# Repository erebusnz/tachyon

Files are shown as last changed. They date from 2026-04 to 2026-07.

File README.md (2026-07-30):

# Tachyon

An open-hardware Eurorack step sequencer with an onboard **wavetable
voice**, built around the STM32F405RGT6 (WeAct core board). Tachyon plays
single-cycle wavetables loaded from a microSD card (Korg
`.korgmultisample` format), driven by a circle-of-fifths key/chord
arpeggiator or by a USB-MIDI host. It generates two precision 1 V/oct CV
outputs, two +5 V gate outputs, and two audio outputs, accepts two CV
modulation inputs and an external clock, and is navigated via a rotary
encoder, a parameter adjustment pot, and a 128×128 OLED screen.

## At a glance

| | |
|---|---|
| **MCU** | STM32F405RGT6 @ 168 MHz (WeAct 64-pin core board), 1 MB Flash, 192 KB RAM |
| **Storage** | MicroSD slot on the WeAct board (SDIO 4-bit) |
| **CV outputs** | 2 × 16-bit, 0–10 V, 1 V/oct, DAC8552 + OPA1642 ×4 |
| **Gate outputs** | 2 × 0/+5 V, 2N7002K level shift |
| **CV inputs** | 2 × bipolar modulation, OPA1642 attenuator → ADC1 |
| **Clock input** | +5 V trigger, TIM2 input capture (with internal BPM fallback) |
| **Audio output** | Stereo I²S, PCM5102A DirectPath |
| **Display** | 1.5″ 128×128 OLED (SSD1327, 4-bit grayscale, SPI) |
| **Controls** | Alps EC11E rotary encoder w/ push switch + Alps 100K pot |
| **USB** | USB-C on the WeAct board — USB MIDI class device, DFU flashing |
| **Power** | 10-pin Doepfer header, ±12 V only (local +5 V buck) |
| **Format** | Eurorack, 10 HP, 3-board sandwich (front / IO / backing) |

### High-level design

- **[hardware-design-plan.md](hardware-design-plan.md)** — the master
  hardware plan. MCU pin budget, peripheral selection, input /
  display / DAC / op-amp choices with rationale.

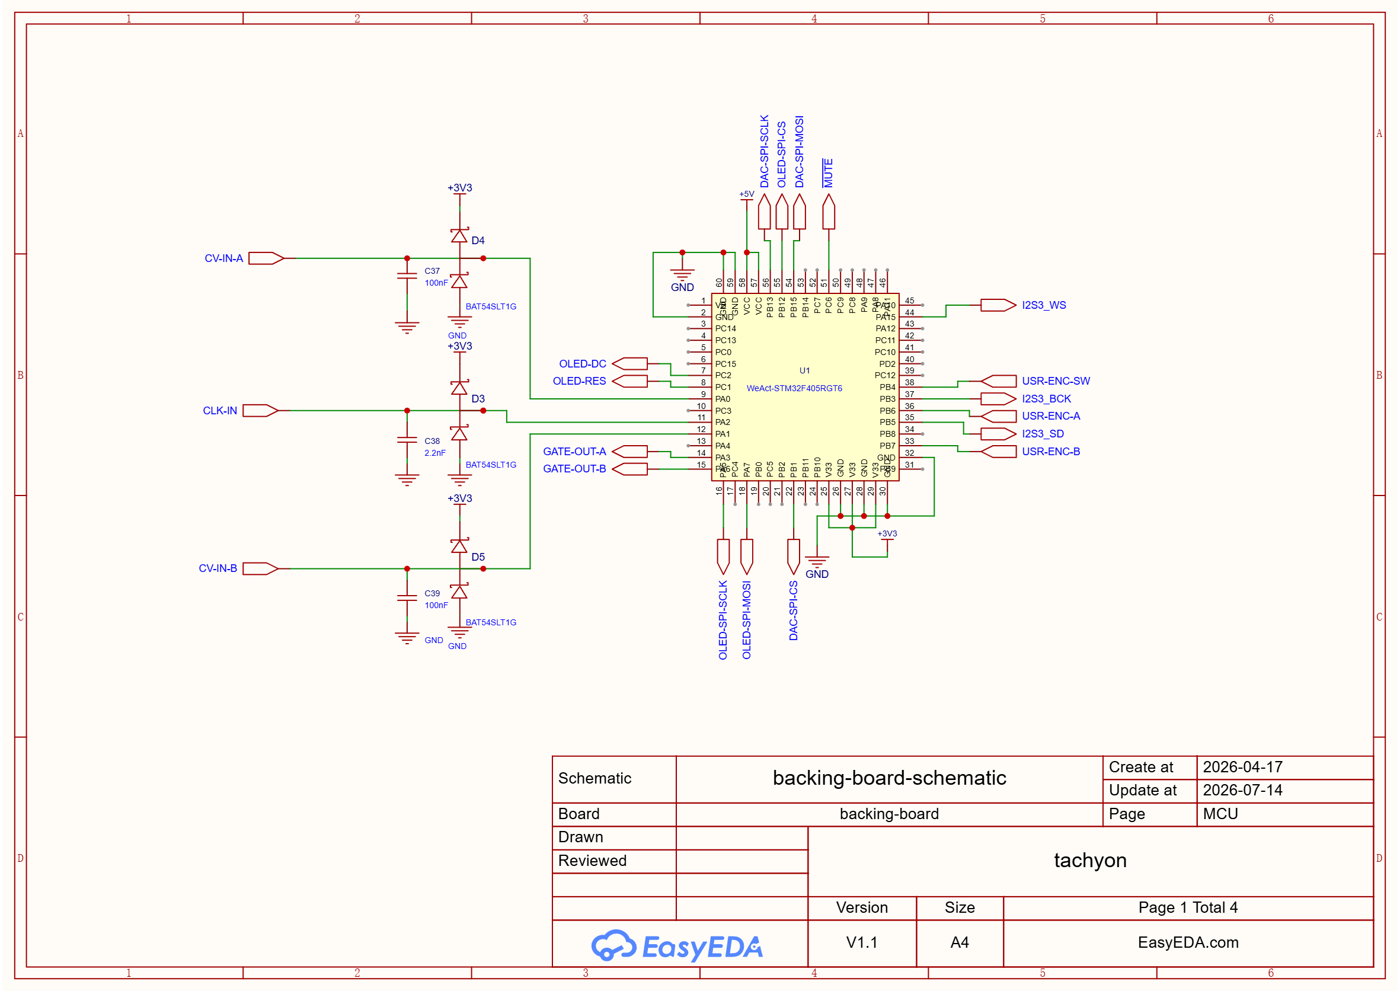
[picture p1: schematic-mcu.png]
MCU schematic
  

### Subsystem specs

These are schematic specs — per-pin connections,
decoupling BOMs:

- **[cv-output-dac.md](cv-output-dac.md)** — precision CV chain:
  DAC8552 (U6) + REF5025 (U2) + OPA1642 (U7), ×4 non-inverting gain
  stage producing 0–10 V at 1 V/oct, with feedback-tap and
  output-protection rules.

- **[cv-input.md](cv-input.md)** — 2 × bipolar Eurorack CV jacks
  through an OPA1642 (U23) inverting attenuator + 1.25 V bias stage
  into ADC1 (PA0/PA1), with BAT54S input clamping.

- **[gate-output.md](gate-output.md)** — 2 × 0/+5 V gate/trigger
  outputs via 2N7002K MOSFET inverting drivers with pull-ups to the
  +5 V rail.

- **[clock-input.md](clock-input.md)** — external +5 V clock jack
  routed to TIM2 input capture (PA2) with the same BAT54S clamp;
  firmware-generated BPM clock as the internal fallback.

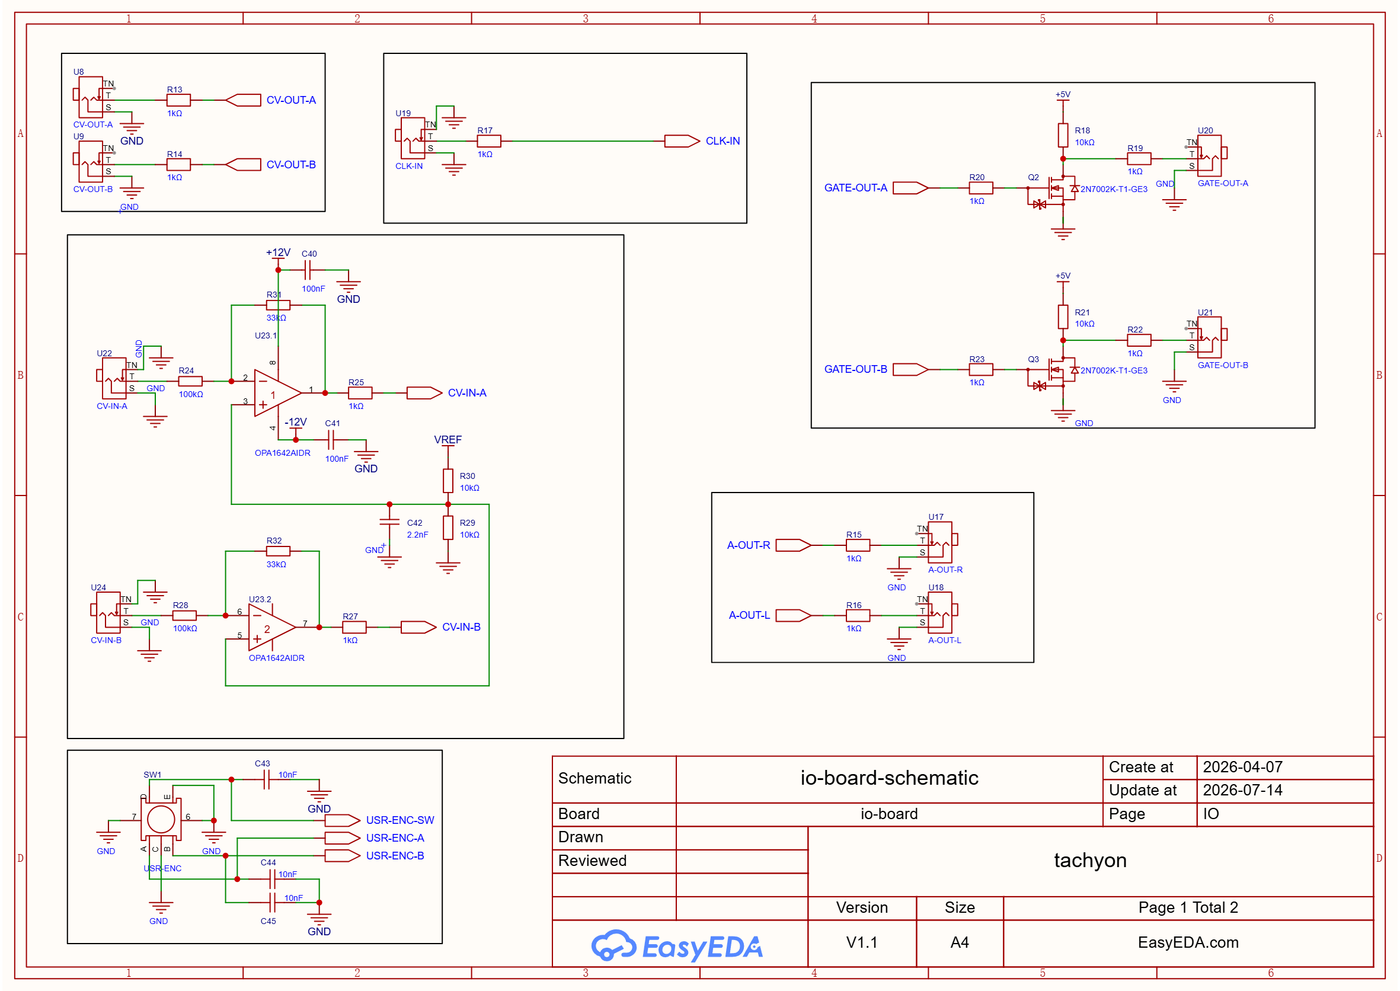
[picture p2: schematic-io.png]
CV and I/O schematic
  

- **[audio-output-dac.md](audio-output-dac.md)** — stereo audio
  chain: PCM5102A (U3) on I²S3, DirectPath outputs to two TS jacks,
  `~MUTE` line, and per-pin decoupling.

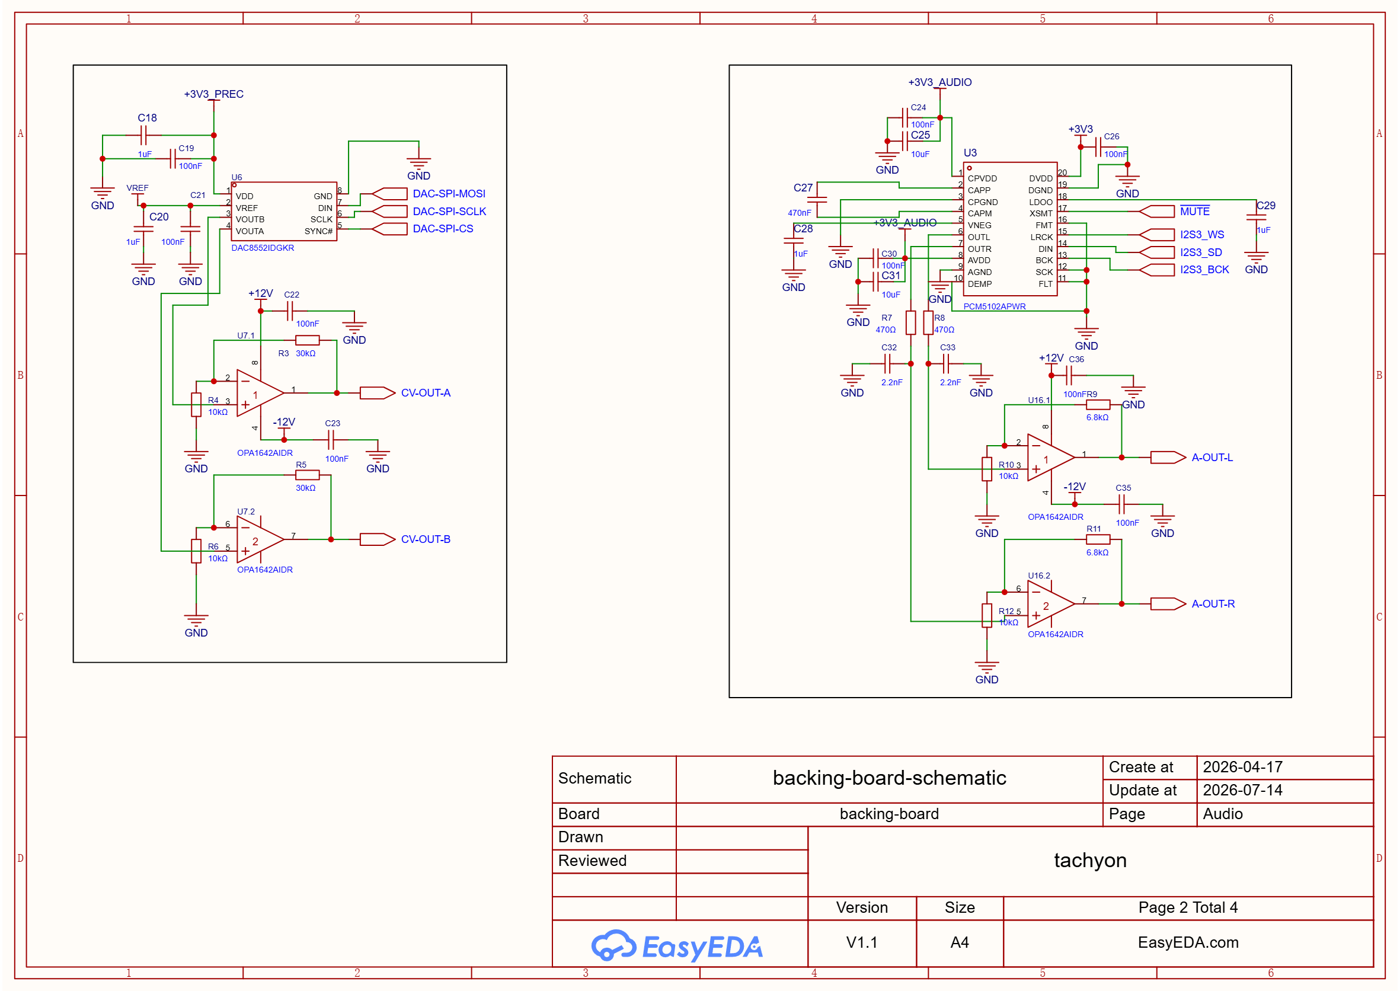
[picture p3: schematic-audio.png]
Audio schematic
  

- **[user-interface.md](user-interface.md)** — front-panel I/O:
  SSD1327 OLED on dedicated SPI1, Alps EC11E quadrature encoder on
  TIM4 with EXTI push-switch, and a 100 K Alps pot into ADC1.

- **[power-supply.md](power-supply.md)** — full power tree: +12 V
  input protection, +12 V → +5 V buck (TPS54202), the two
  TPS7A2033 low-noise LDOs for `+3V3_PREC` and `+3V3_AUDIO`, and
  the rail current budget.

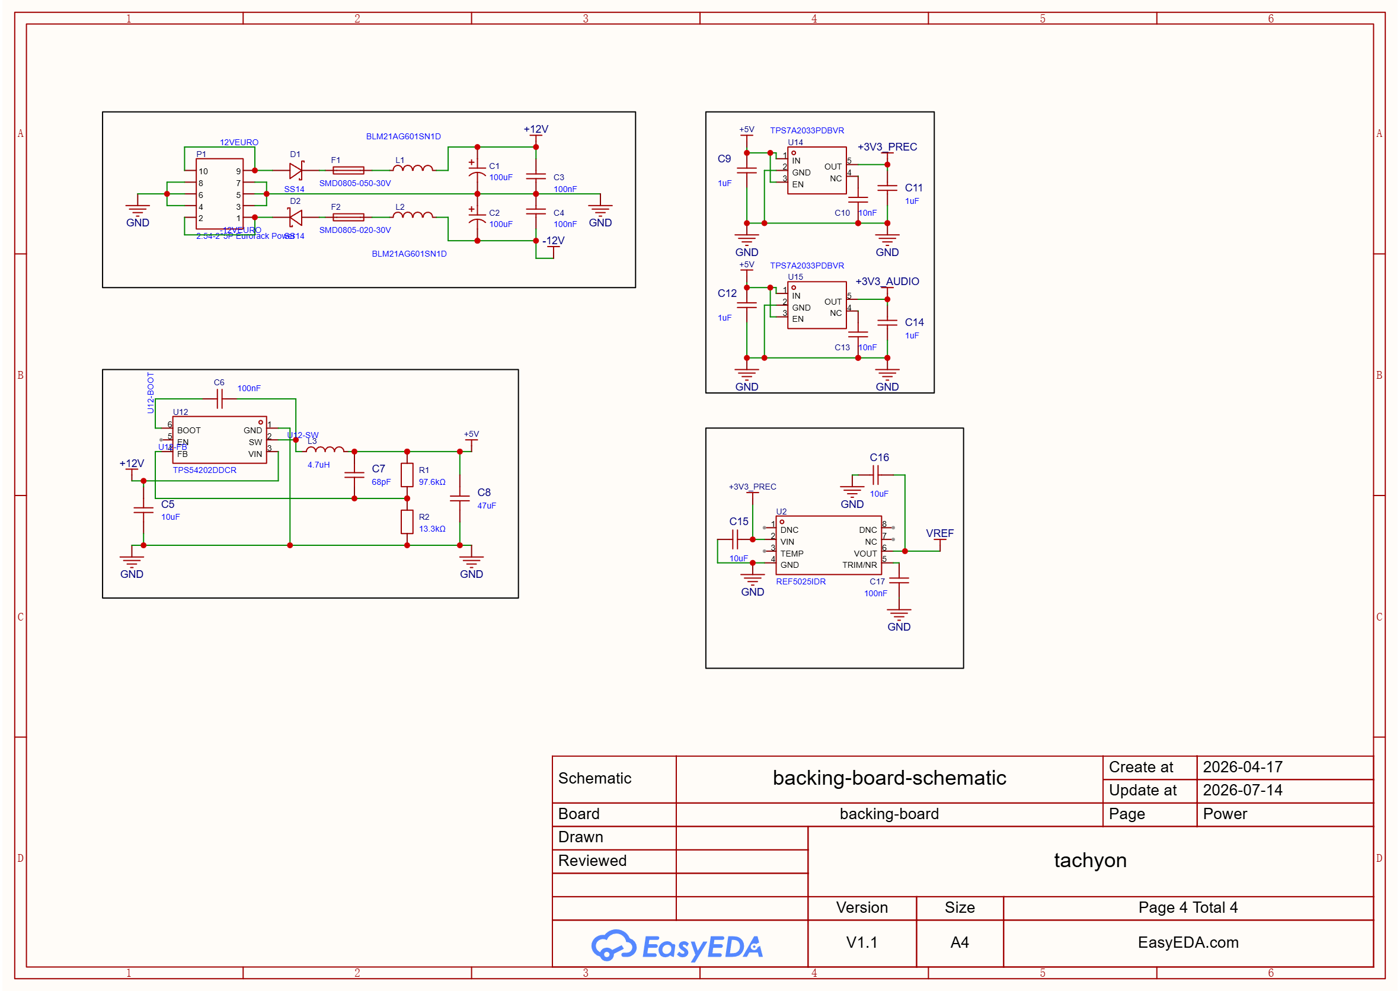
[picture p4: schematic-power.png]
Power schematic
  

### Physical design

The module is a three-PCB sandwich: a **front** board (panel
graphics, no electrical content), an **IO** board (panel-side
jacks, pot, encoder, and OLED ribbon connector), and a **backing**
board (the dense analog/digital board with the buck, LDOs,
references, DACs, op-amps, and the WeAct STM32 module on its
bottom side). The boards mate via inter-board pin headers.

- **[pcb-design.md](pcb-design.md)** — PCB stackup, ground plane
  rules (one continuous Layer 2 plane, no splits), power pour
  regions, placement zones, and signal routing guidance for the
  backing board, plus the inter-board header map.

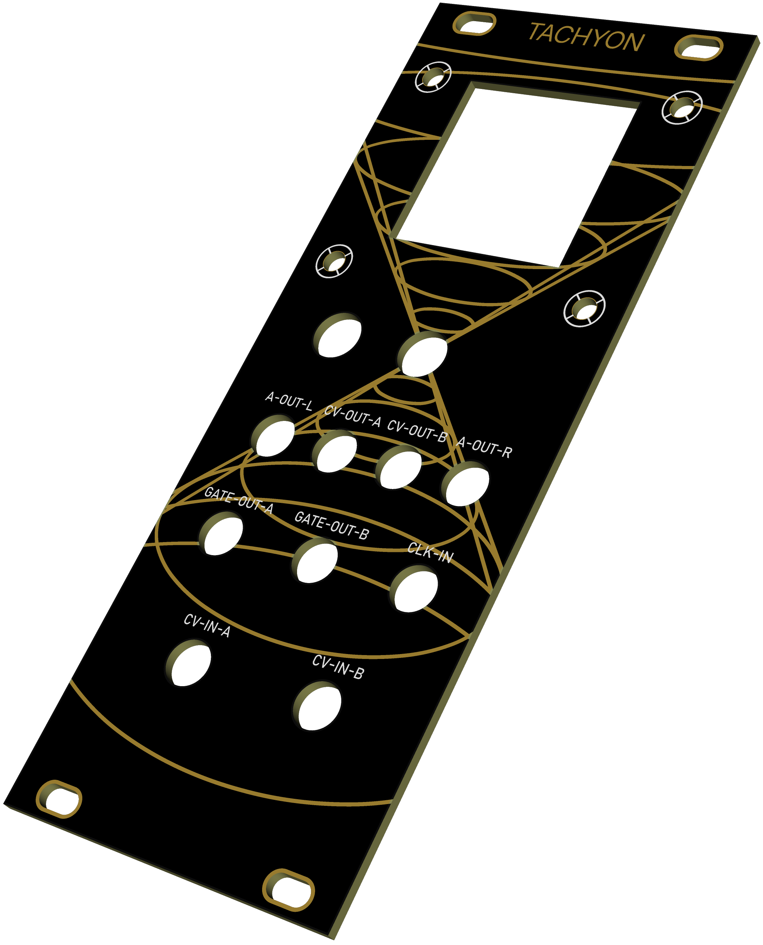
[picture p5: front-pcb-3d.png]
Front PCB 3D render
  

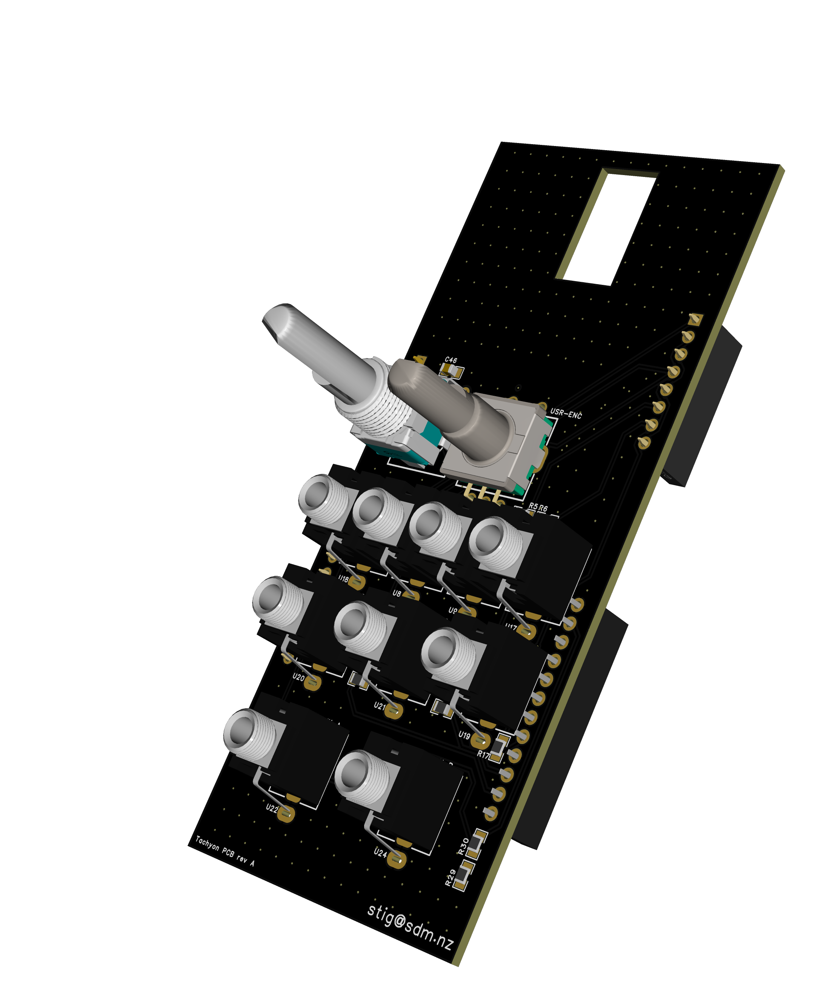
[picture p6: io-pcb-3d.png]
IO PCB 3D render
  

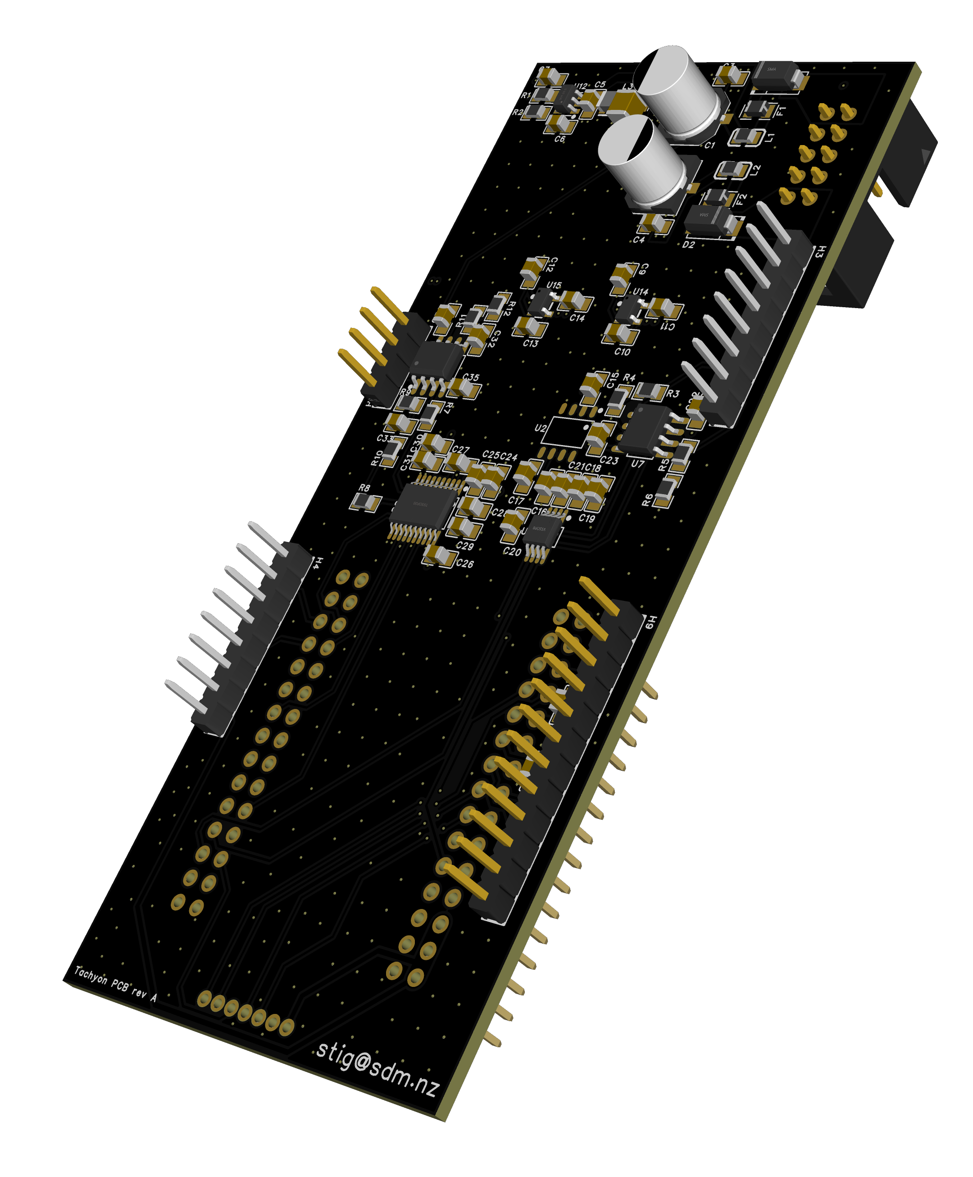
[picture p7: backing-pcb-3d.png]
Backing PCB 3D render
  

### Manufacturing outputs

The [`gerber/`](gerber/) folder holds the latest fab/assembly
exports for all three boards, plus the per-board audit reports
([`audit-front-board.md`](gerber/audit-front-board.md),
[`audit-io-board.md`](gerber/audit-io-board.md),
[`audit-backing-board.md`](gerber/audit-backing-board.md))
created by the included [`pcb-designer`](.claude/skills/pcb-designer/)
skill for Claude that cross-check each export against the design
docs. Combined per-board schematic PDFs live at the repo root:
[`io-board-schematic.pdf`](io-board-schematic.pdf),
[`mcu-audio-board-schematic.pdf`](mcu-audio-board-schematic.pdf).
The EasyEDA Pro source project is [`tachyon.eprj`](tachyon.eprj).

### Ordering PCBs

Using EasyEDA you can order direct with JLCPCB, but
[PCBWay](https://www.pcbway.com/) also provide excellent
high-quality PCB manufacturing, with a choice of 9 different
solder mask colors as well as a Black FR4 substrate option —
perfect for the Eurorack front plate.

When ordering the two 4-layer boards (IO and backing) from PCBWay,
the EasyEDA layer names aren't recognised automatically — select the
following Gerber file for each layer:

| PCBWay layer | Gerber file |
|---|---|
| L1 | `Gerber_TopLayer.GTL` |
| L2 | `Gerber_InnerLayer1.G1` |
| L3 | `Gerber_InnerLayer2.G2` |
| L4 | `Gerber_BottomLayer.GBL` |

Alternatively, rename `.G1` to `.GP1` and `.G2` to `.GP2` before
uploading.

### Bring-up

- **[calibration.md](calibration.md)** — one-time CV output
  calibration procedure (two-point slope/offset fit against a DMM)
  for the precision DAC path.

### Datasheets

The [`datasheets/`](datasheets/) folder holds per-part markdown
summaries (pinout, key electrical specs, application notes)
extracted from the manufacturer PDFs for every non-passive component
in the BOM. The PDFs live alongside each `.md` summary. Root-level
docs cite these with paths like `DAC8552.md:72` when a specific
paragraph matters.

### Firmware

- **[firmware/README.md](firmware/README.md)** — DFU flashing
  instructions and firmware build notes.

### Software required

- **EasyEDA** — schematic/PCB design
- **Claude Code** — schematic/PCB validation and planning
- **STM32CubeMX** — STM32 peripheral and clock configuration
- **Claude Code** — firmware development

Both hardware (schematic/PCB) and firmware design are supported in
Claude Code. The included markdown files — including MD versions of
the datasheets for key components — for the hardware design and the
[`pcb-designer`](.claude/skills/pcb-designer/) skill allow Claude to
reason about design changes to both hardware and software without
needing additional context to be shared within Claude.

## Operating the synth

### Wavetables — microSD (Korg `.korgmultisample`)

Tachyon's voice plays single-cycle wavetables stored on the WeAct board's
microSD slot. Wavetables are **Korg `.korgmultisample`** sets, created with
Korg's free
[**Sample Builder**](https://www.korg.com/us/support/download/software/1/447/4811/)
application (the sample-import tool for the Wavestate / Modwave): load your
WAVs, lay out the key-zones, and export the `.korgmultisample`. The format
can also be produced by tools such as
[ConvertWithMoss](https://github.com/git-moss/ConvertWithMoss) (whose
reference parser this firmware follows).

Card layout:

- Format the card **FAT32 or exFAT**.
- Put **one wavetable per folder** in the card root. Each folder holds a
  `.korgmultisample` file plus the member **WAV** files it references
  (16-bit mono PCM, single-cycle).
- The `.korgmultisample` maps **key-zones**: each zone assigns a key range
  (low / high / root) to one member WAV, so the timbre is band-limited per
  octave. The stock sets tile roughly one octave per zone.

On boot Tachyon mounts the card, caches the folder list, and loads a
default wavetable. Pick a different one from **Config → Audio Cfg →
Wavetable** (a scrolling browser of the card's folders); **Level** on the
same screen sets output volume. The played note chooses the zone and sets
the pitch — pitch is independent of each sample's recorded rate. Up to
**four voices** sound at once.

### The three play modes

Select a mode from the main menu (turn the encoder, push to enter). A mode
is an *instrument* — it keeps sounding while you visit the config screens;
**long-press** the encoder to return to the menu.

| Mode | What it does | Controls |
|---|---|---|
| **Key Arp** | A circle-of-fifths **key wheel**; the arpeggiator plays the key's tonic triad. | Turn = pick key · push = major/minor |
| **Chord Arp** | Pick among the **seven diatonic triads** of the selected key (circle-of-fifths order); the arp plays the chosen chord. | Turn = pick chord |
| **USB MIDI** | Tachyon enumerates over USB-C as **"Tachyon MIDI"**; notes from a DAW or controller play the wavetable voice **polyphonically** (4 voices). | Push = all-notes-off panic |

The arpeggiator (Key / Chord modes) is configured in **Config → Arp Cfg**:
direction, octave range, step length, internal/external clock, and tempo.
In those modes each step drives the audio voice **and** `CV-OUT-A`
(1 V/oct) plus the gate outputs — so Tachyon plays its own voice while
sequencing external modules, clocked internally or from the clock input.
The **USB MIDI** mode plays the internal voice only.

Every voice runs through a velocity-sensitive **envelope filter** (a
per-voice lowpass swept by an ADSR — playing harder is brighter and
louder), configured in **Config → Filter Cfg**: cutoff, resonance,
envelope amount, attack/decay/sustain/release, and velocity→level. See
**[filters.md](filters.md)**.

See **[harmony-engine.md](harmony-engine.md)** for the source × engine
model behind the modes, and **[usb-midi.md](usb-midi.md)** for the
USB-MIDI device (including the `USB_SERIAL_DEBUG` build flag that swaps the
port to a CDC serial console for debugging).

## Licence

Hardware (schematics, PCB, mechanical) is licensed under the
[CERN Open Hardware Licence Version 2 — Strongly Reciprocal](LICENSE)
(CERN-OHL-S v2).

Firmware (everything under [`firmware/`](firmware/)) is licensed
separately under the [MIT License](firmware/LICENSE).

Copyright © 2026 Stig Manning.

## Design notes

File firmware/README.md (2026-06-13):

# Firmware

## Flashing

### ST-LINK/V2 over SWD (preferred)

Fastest path — no BOOT0/DFU dance, ~2 s per flash. Wire the ST-LINK/V2 to the
WeAct board's SWD header (PA13/PA14, see `hardware-design-plan.md`):

| ST-LINK pin | Board pin |
|---|---|
| SWDIO | PA13 (`DIO`) |
| SWCLK | PA14 (`CLK`) |
| GND | GND |
| 3.3V (VTref) | 3V3 |

The `3.3V`/VTref wire is required even when the board is self-powered — the
ST-LINK senses target voltage on it before driving the SWD lines (a missing
VTref shows up as `Voltage : 0.00V` and `Unable to get core ID`). With the board
self-powered this ties the probe's 3.3 V to the live 3V3 rail (both ~3.3 V),
which is fine for programming.

Build and flash with the helper script (auto-discovers `STM32_Programmer_CLI`):
```powershell
./flash.ps1            # flash build/Debug/firmware.elf
./flash.ps1 -Build     # build Debug first, then flash
./flash.ps1 Release    # flash the Release build
```

Or invoke the programmer directly:
```
STM32_Programmer_CLI --connect port=SWD mode=UR --download build\Debug\firmware.elf --start
```

### DFU over USB (fallback, no ST-LINK)

Hold down the BOOT0 (B0) button and connect to the computer via USB, release after 1s. You should now be in DFU mode over USB.

You can test connection with:
```
STM32_Programmer_CLI --connect port=USB1
```

Flashing firmware:
```
STM32_Programmer_CLI --connect port=USB1 --download build\Debug\firmware.elf 0x08000000 --start
```

## Audio output (PCM5102A) — I2S considerations

The audio DAC (U3, PCM5102A) is driven from **I2S3**: `PB3` = BCK, `PB5` =
DIN/SD, `PA15` = LRCK/WS, with `PC6` = `~MUTE` to the XSMT pin. It is wired in
**3-wire mode**: `SCK` (pin 12) is tied to GND, so the part runs its **internal
PLL**, deriving the system clock from BCK — there is no MCLK. See
`audio-output-dac.md` and `datasheets/PCM5102A.md` for the full wiring.

This mode imposes firmware rules that are easy to get wrong and produce a DAC
that is powered, unmuted, and correctly clocked yet **completely silent**:

- **The I2S clocks must run continuously — never stop BCK/LRCK.** The PCM5102A
  treats any clock halt or invalid BCK/LRCK relationship (more than 4 LRCK
  periods) as a clock error: it drops to **standby and forces the analog
  output to bipolar-zero (silence)** until the clocks resynchronise. A blocking
  / one-shot `HAL_I2S_Transmit()` per buffer stops the clocks between bursts and
  will leave the output muted.
- **Drive the DAC from a circular DMA**, not polling/normal-mode transfers.
  `HAL_I2S_Transmit_DMA()` with the SPI3_TX stream (`DMA1_Stream5`, Channel 0)
  in `DMA_CIRCULAR` mode keeps the clocks free-running even when the CPU is busy
  (e.g. during a blocking OLED frame blit): if a refill callback is late the DMA
  simply replays the buffer rather than halting the clocks. Refill the buffer
  halves from `HAL_I2S_TxHalfCpltCallback` / `HAL_I2S_TxCpltCallback`. To emit
  silence, stream zeros — **do not stop the DMA.**
- **Let the PLL lock before expecting output.** With SCK grounded the internal
  PLL only starts after BCK + LRCK have run for **16 successive LRCK periods**.
  Start the (silent) stream early in init so the PLL is locked by the time audio
  is needed.
- **XSMT (`~MUTE`, PC6) sequencing:** hold it **LOW** through init until the I2S
  clocks are stable, then drive it **HIGH** to unmute (the net is active-low; PC6
  goes straight to XSMT with no inverter). XSMT LOW is also the part's
  power-down state.
- **Clock ratio:** the build runs **192 kHz, 32-bit** I2S (Philips standard),
  i.e. **64 BCK per stereo frame** (32 BCK/channel) → BCK = 12.288 MHz. That is
  within the PLL's supported BCK/LRCK range (32/48/64 per channel); changing the
  sample rate or word length must keep the ratio in that range.

> The `firmware-test/` bring-up console drives the DAC exactly this way
> (continuous circular DMA streaming silence from boot, sine on `tone <hz>`);
> mirror that pattern in the application audio path.

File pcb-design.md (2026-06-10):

# PCB Design -- Stackup and Layout Strategy

This document defines the PCB stackup and the mixed-signal layout
strategy for the Tachyon Eurorack module. It is the authoritative
source for:

- Layer count and stackup
- Ground plane topology (one plane, no splits)
- Power pour regions
- Component placement zones
- Signal routing guidance

Rail definitions, part selections, and per-IC decoupling live in
`power-supply.md` and `audio-output-dac.md`; this document describes how
those rails and ICs are arranged on the physical board.

**Naming convention:** "Layer 1 / Layer 2 / Layer 3 / Layer 4" refers to
the PCB stackup layers. Bare designators `L1`, `L2`, `L3` refer to
**component** reference designators (the two input ferrites and the buck
inductor, respectively, per `power-supply.md`).

---

## 1. Why 4 layers

A 2-layer board cannot deliver acceptable EMI or analog performance for
this design: the TPS54202 buck switch-node loop, the STM32F405 clock
lines, the I2S traces to the PCM5102A, and the precision reference /
DAC8552 rail all have to coexist within ~50 mm of each other. On 2
layers every fast return current loops through the air as a radiator,
and the precision analog rail shares its reference with the buck return.

A 4-layer board solves this with two devices:

1. **A continuous, unbroken ground plane** directly underneath every
   signal trace, containing HF return currents locally.
2. **A dedicated power pour layer**, so each rail gets its own copper
   region sized to its load, without running as a trace.

**6 layers would be overkill.** None of the signals on this board are
fast enough to need stripline routing, none of the ICs need tighter
power delivery than a 4-layer pour can give, and the cost jump
(roughly 5-6x at prototype quantity from JLCPCB) buys nothing audible
or measurable for this IC lineup. 4-layer is the correct target.

---

## 2. Stackup

Target fab: JLCPCB or equivalent, standard 1.6 mm 4-layer FR4, 1 oz
copper on all layers.

```
┌──────────────────────────────────────────────────┐
│ Layer 1  TOP     -- components + signal routing  │   0.035 mm Cu
├──────────────────────────────────────────────────┤
│         prepreg    ~0.2 mm                       │
├──────────────────────────────────────────────────┤
│ Layer 2  GND     -- solid, continuous ground     │   0.035 mm Cu
├──────────────────────────────────────────────────┤
│         core       ~1.065 mm                     │
├──────────────────────────────────────────────────┤
│ Layer 3  PWR     -- power pour regions           │   0.035 mm Cu
├──────────────────────────────────────────────────┤
│         prepreg    ~0.2 mm                       │
├──────────────────────────────────────────────────┤
│ Layer 4  BOTTOM  -- components + signal routing  │   0.035 mm Cu
└──────────────────────────────────────────────────┘
                  total ~1.6 mm
```

Notes on the stackup:

- **Layer 1 - Layer 2 separation (~0.2 mm)** is deliberately much thinner
  than the core. Layer 1 signals are referenced tightly to the Layer 2
  ground plane with low loop inductance. This is where the fast / noisy
  signals should route (buck switch node loop, I2S, SPI).
- **Layer 2 and Layer 3 are separated by the core (~1.065 mm)**. This is
  fine -- the distance between GND and PWR planes is not performance-
  critical here; bulk decoupling comes from the explicit ceramic caps,
  not from plane capacitance.
- **Layer 4 - Layer 3 separation (~0.2 mm)** mirrors Layer 1 - Layer 2,
  so bottom-side signals are referenced to the Layer 3 power pour
  regions. This is acceptable for slow signals (encoders, front-panel
  wiring, OLED cable, CV jacks) but **not** for fast signals -- those
  belong on Layer 1 over the GND plane.
- Fab will set the exact prepreg/core thicknesses to hit 1.6 mm; the
  ratios above are the standard JLCPCB "JLC04161H-7628" stackup. Do
  not request a custom stackup unless there is a specific reason.

---

## 3. Ground plane (Layer 2)

**Rule 1: Layer 2 is one single, continuous copper pour. It is never
split, cut, moated, or partitioned.**

This is the single most important layout rule on the board. The old
mixed-signal dogma of "split AGND from DGND and join at a star point"
is wrong for modern layouts and has been repeatedly debunked (Henry
Ott, Howard Johnson, Rick Hartley). A split plane forces return
currents to detour around the cut, which *increases* loop area and
radiated EMI rather than reducing it.

**Why one plane works:** HF return current does not take the path of
least resistance -- it takes the path of least inductance, which is
directly underneath the signal trace on the adjacent plane. This means
a continuous plane automatically separates return currents by
placement: the buck's return current stays under the buck, the audio
DAC's return current stays under the audio DAC, and they do not mix
even though the copper is electrically one net.

**Consequences:**

- There is no "AGND net" and no "DGND net" in the schematic. Everything
  is `GND`.
- There is no star-point tie between analog and digital grounds. There
  is nothing to star.
- The `power-supply.md` rule about "tie AGND at the LDO output cap" is
  **obsolete** with this stackup -- one continuous plane handles it.
- Partitioning is done by **component placement on Layer 1**, not by
  copper topology on Layer 2. See Section 5.

**Exceptions:** none. Do not cut Layer 2. If you think you need to cut
Layer 2, the answer is to move a component instead.

**Stitching vias:** place generous GND-to-GND stitching vias between
Layer 1 / Layer 4 ground pours and Layer 2, especially:

- Around the TPS54202 package (≥ 6 vias on its GND pad / thermal pad)
- Under the PCM5102A and DAC8552 GND pins
- Along the edge of the board (a via fence ~2 mm inside the board
  outline, ~5 mm pitch, for return-current containment at the edge)
- On the ground return of every decoupling cap (one via per cap, as
  close to the GND pad as possible)

---

## 4. Power plane (Layer 3)

Layer 3 is **not** a single power plane -- it is a set of **poured
regions**, each dedicated to one rail. The regions are placed directly
underneath the ICs they feed, so power delivery is vertical (through
vias) rather than horizontal (through traces).

### Regions

| Region | Rail | Footprint under... |
|---|---|---|
| `+5V` | Buck output | From TPS54202 output to WeAct VIN and both LDO VINs |
| `+3V3` | WeAct 3V3 out | STM32F405, OLED connector, PCM5102A DVDD |
| `+3V3_PREC` | U14 out | DAC8552 VDD and REF5025 VIN |
| `+3V3_AUDIO`| U15 out | PCM5102A AVDD pin 8 and CPVDD pin 1 |
| `+12V` | P1 (post D1 / L1 ferrite) | OPA1642 V+ (U7 pin 8) |
| `-12V` | P1 (post D2 / L2 ferrite) | OPA1642 V- (U7 pin 4) |

### Pour rules

- **Each region is a solid pour**, not a trace. Use polygon pours, not
  wide tracks.
- **Regions do not overlap.** The boundaries are determined by the
  placement of the ICs each region feeds -- if two ICs on different
  rails are adjacent, the boundary runs between them.
- **No region may cross under a sensitive IC that belongs to a different
  rail.** Specifically: `+5V` (noisy, carries buck output ripple) must
  not pass under the PCM5102A, REF5025, or DAC8552. The `+3V3_AUDIO` and
  `+3V3_PREC` regions sit there instead.
- **Gap between regions:** 0.5 mm minimum, to avoid fab over-etch
  joining two rails. The gap is not a slot in the *ground* plane
  (Layer 2) -- Layer 2 remains continuous beneath the power-region
  boundary.
- **Delivery vias:** each IC power pin gets its own via from Layer 1
  pad to Layer 3 region, placed as close to the pin as possible. Do not
  share one via between multiple power pins.
- **Bulk caps go to the same vias.** The decoupling cap for a given IC
  sits next to that IC on Layer 1 and shares the same local via stack
  down to Layer 3 (power) and Layer 2 (ground).

### What about the inter-region gaps on Layer 3?

The gaps between power regions on Layer 3 are **thin slivers of bare
FR4** (no copper). Signals on Layer 4 that cross these gaps would see a
return-path discontinuity on Layer 3 -- but this is not a problem in
practice because:

1. Layer 4 signals are referenced primarily to Layer 3 for slow
   signals, but the fast signals (I2S, SPI, buck switch loop) are on
   Layer 1 over Layer 2 (which is continuous and has no gaps).
2. Slow signals (encoders, CV jacks, OLED ribbon) have edge rates too
   low to care about return-path discontinuities on the other reference
   plane.

If you find yourself needing to route a fast signal on Layer 4 across
a power-region boundary, move it to Layer 1 instead.

---

## 5. Component placement (backing-board)

This section describes the placement strategy for the **backing-board**
(the dense board: TPS54202 buck, LDOs, STM32 module, audio DAC, CV DAC,
references, op-amps). The io-board is panel-side and its placement is
dictated by the panel ergonomics (jack and pot positions). The
front-board has no electrical content.

### Stratified layout

The backing-board is partitioned by **horizontal stratification** down
the long axis, not by cardinal quadrants. The board is 48 × 110 mm with
the Eurorack header (P1) at the top edge.

```
┌──────────────────────────────────────────────────────┐
│  POWER ENTRY STRIP    (top, ~Y = 0 .. -12 mm)         │
│  U12 TPS54202 buck (top-left, top side)               │
│  P1 Eurorack header (top-right, BOTTOM side; cable    │
│      plugs into the back face of the module)          │
│  D1 / D2 SS14 protection diodes                       │
│  F1 / F2 PTC fuses, L1 / L2 ferrites                  │
│  C1 / C2 bulk caps, C3 / C4 HF bypass                 │
│  C5 (buck input), C6 (BOOT), C7 (FF), C8 (output),    │
│      L3 (buck inductor), R1 / R2 (FB divider)         │
├──────────────────────────────────────────────────────┤
│  UPPER ANALOG BAND    (~Y = -28 .. -48 mm)            │
│  U14 TPS7A2033 +3V3_PREC LDO                          │
│  U15 TPS7A2033 +3V3_AUDIO LDO                         │
│  U2  REF5025 precision reference                      │
│  U7  OPA1642 CV output buffers                        │
│  U16 OPA1642 audio output buffers                     │
├──────────────────────────────────────────────────────┤
│  MID ANALOG BAND      (~Y = -48 .. -65 mm)            │
│  U3  PCM5102A audio DAC                               │
│  U6  DAC8552 CV DAC                                   │
├──────────────────────────────────────────────────────┤
│  MCU REGION           (~Y = -75 .. -95 mm)            │
│  U1  WeAct STM32F405 module — on the BOTTOM side      │
│      (physically isolated from the analog parts on    │
│       the top side by the PCB itself)                 │
│  H4, H9 — IO-board headers (bottom side)              │
└──────────────────────────────────────────────────────┘

Inter-board headers H2 / H3 sit on the left / right edges between the
upper and mid analog bands.
```

The buck noise source is at one extreme of the long axis, the analog
bands sit in the middle, and the MCU module hides on the back side of
the PCB. Analog return currents stay on the top half of the GND plane;
buck switching loop currents stay near U12; MCU digital return
currents stay near U1's pin headers on the bottom side.

### Spacing rules

Placement is constrained by these distance invariants. The audit script
(`run_audit.py`'s `SPACING_RULES`) enforces them automatically; keep
the two in sync.

| Constraint | Threshold | Rationale |
|---|---|---|
| `U12 ↔ U3` (buck ↔ audio DAC) | ≥ 30 mm | Switch-node loop must be far from the audio DAC to avoid radiative coupling. |
| `U12 ↔ U2` (buck ↔ ref) | ≥ 30 mm | Switch-node loop must be far from the precision Vref. |
| `U12 ↔ U16` (buck ↔ audio op-amp)| ≥ 30 mm | Audio output buffers are as sensitive as the DAC; same rule applies. |
| `U2 ↔ U6` (REF5025 ↔ DAC8552) | ≤ 20 mm | `VREF` analog trace must be short (`cv-output-dac.md` §6). |

Adjacency / orientation rules that don't reduce to a single distance:

- **U12 (TPS54202) sits at the top edge** of the board so the buck
  switch-node loop closes locally on Layer 1 with C5 (input) → VIN →
  GND → C5, ≤ 5 mm² loop area target.
- **U7 (OPA1642 CV)** sits adjacent to U6 (DAC8552) so DAC → buffer
  traces are short. CV output traces from U7 then run to H3 on the
  right edge.
- **U16 (OPA1642 audio)** sits adjacent to U3 (PCM5102A) so PCM5102A
  OUTL/OUTR → buffer inputs are short. Audio output traces from U16
  run to H2 on the left edge.
- **U14 / U15 LDOs** sit between the power-entry strip and the upper
  analog band, so the noisy +5 V copper terminates at the LDO inputs
  and only the regulated `+3V3_PREC` / `+3V3_AUDIO` rails reach the
  analog bands.
- **U1 (WeAct STM32 module) on the bottom side** keeps the digital
  switching noise on the opposite face of the PCB from the analog
  ICs. The WeAct module has its own onboard 3V3 LDO and decoupling;
  no per-pin bypass caps from the main PCB are required.

### Decoupling caps

Every IC's decoupling cap must be on the same side of the board as the
IC, within 2 mm of the power pin it decouples, with its GND via directly
adjacent to the cap pad. The audit reports the centre-to-centre
distance from each cap to its IC; ≤ 8 mm centre-to-centre on 0805 caps
is the practical equivalent of the 2 mm pin-to-cap rule.

Sub-modules with onboard decoupling (currently the WeAct STM32F405
module, U1) are exempt — those rely on their internal bypass network
and only need a single bulk cap at the module's `+5 V` input pin.

### The I2S bridge

The I2S signals (`I2S3_BCK`, `I2S3_SD`, `I2S3_WS`) run from U1 (STM32,
bottom side) to U3 (PCM5102A, top side, mid analog band). This is the
one place on the board where a fast digital signal must transition
between layers and enter the analog half. Mitigations:

1. **Route on Layer 1 over Layer 2 GND** for the segment on the top
   side. Drop a stitching via to Layer 2 GND adjacent to each
   layer-transition via.
2. **Keep total trace length short** — under 30 mm preferred, under
   50 mm absolute. Centre-to-centre U1 ↔ U3 is ~28 mm; routed length
   will be slightly longer.
3. **Ground-flanked routing.** Run a ground pour on Layer 1 on both
   sides of the I2S bundle, stitched to Layer 2 every ~3 mm with vias,
   for the segment closest to the analog band.
4. **No other signals in the I2S corridor.** The strip of board
   between U1 and U3 is reserved for I2S and ground only.

There is no buffer IC in the I2S path — earlier revisions of this
document referenced a 74AHCT1G125 (U4); that part was dropped because
the PCM5102A's internal PLL handles the clock-domain transition and
the STM32 I2S drive strength is adequate at the trace lengths on this
board.

#### Series termination — not required at this trace length

Earlier revisions of this section mandated 33 Ω series termination
at the STM32 I2S output. That rule was over-conservative for the
trace lengths on this board.

Howard Johnson's rule of thumb: a trace is electrically short and
needs no termination when its length is less than `t_r × v / 6`,
where `t_r` is the source rise time and `v` is the FR4 propagation
velocity (~167 mm/ns).

| STM32F405 GPIO speed | `t_r` | Critical length | This board's I2S trace |
|---|---:|---:|---:|
| Low (2 MHz) | 100 ns | 2800 mm | 30-40 mm  (90× margin) |
| Medium (25 MHz) | 10 ns  | 280 mm | 30-40 mm  (7× margin)  |
| Fast (50 MHz) | 4 ns | 110 mm | 30-40 mm  (3× margin)  |
| High (100 MHz) | 2 ns | 56 mm | 30-40 mm  (1.5× margin)|

The I2S signals are at audio rates (≤ 12.288 MHz BCK at 192 kHz / 64-fs),
so the firmware can — and should — set the I2S GPIO pins to **low or
medium speed**. At those speed settings the trace is electrically
short by a wide margin, reflections die out before edges transition,
and series termination delivers no measurable improvement (and can
slow edges enough to degrade the signal).

**Implementation note for firmware:** configure `PB3 (I2S3_BCK)`,
`PB5 (I2S3_SD)`, and `PA15 (I2S3_WS)` with
`GPIO_Speed_Level_Low` or `_Medium` in the I2S init code. Do not use
`_High` or `_Very_High`.

If a future redesign stretches the I2S trace beyond ~50 mm, or moves
to a faster receiver where edge rate must come up, revisit this
calculation. Until then the netlist correctly omits termination
resistors.

---

## 6. Signal routing guidance

### Where each signal class belongs

| Signal class | Preferred layer | Reference plane | Notes |
|---|---|---|---|
| Buck switch-node loop | Layer 1 | Layer 2 GND | Tightest possible loop |
| I2S (MCLK, BCK, LRCK, DATA) | Layer 1 | Layer 2 GND | Series-terminated, flanked |
| SPI to DAC8552 (SCK, MOSI, CS) | Layer 1 | Layer 2 GND | Short as possible |
| Precision analog (Vref → DAC, DAC → OPA1642 → jacks) | Layer 1 | Layer 2 GND | Kept inside Zone C |
| Audio output (PCM5102A → jacks) | Layer 1 | Layer 2 GND | Kept inside Zone C |
| Encoder / button / slow digital | Layer 1 or Layer 4 | Layer 2 or Layer 3 | No restrictions |
| Power delivery | Layer 3 pour | -- | Vertical via drops |
| Front-panel wiring (OLED cable, jacks) | Layer 1 or Layer 4 | -- | Kept away from buck |

### Layer transitions (vias)

- Minimize Layer 1 ↔ Layer 4 transitions for fast signals. Each via is
  an impedance discontinuity and each transition changes the reference
  plane (Layer 2 → Layer 3).
- When a fast signal must transition, place a stitching via
  (GND ↔ GND, Layer 2 ↔ local Layer 1 / Layer 4 pour) within 1 mm of
  the signal via, so the return current has a nearby path to hop to the
  new reference plane.
- Slow signals (encoders, etc.) do not need stitching vias on transitions.

### Trace widths (minimum)

| Net | Minimum width | Reason |
|---|---|---|
| +12V, -12V | 0.5 mm | Bus rail current + reverse-diode  |
| +5V | 0.6 mm | Full board digital + LDO inputs |
| +3V3 (digital)  | 0.4 mm | MCU + OLED load |
| +3V3_AUDIO | 0.3 mm | ~25 mA load |
| +3V3_PREC | 0.3 mm | ~10 mA load |
| GND return | n/a | Uses Layer 2 plane, not traces |
| Signal | 0.15 mm | JLCPCB minimum for 1 oz |
| I2S / SPI | 0.2 mm | Slight over-minimum for impedance |

Power rails are preferably delivered as Layer 3 pours, not traces; the
widths above apply only where a pour is not feasible (e.g. bridging
around a component).

---

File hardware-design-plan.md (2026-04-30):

# Tachyon — Hardware Design Plan

### MCU Specifications (STM32F405RGT6)

[WeAct Studio STM32F405RGT6 64-Pin Core Board](https://github.com/WeActStudio/WeActStudio.STM32F4_64Pin_CoreBoard)

- **CPU:** Cortex-M4F @ 168 MHz with hardware single-precision FPU + DSP SIMD
- **RAM:** 192 KB SRAM
- **Flash:** 1 MB onboard
- **ADC:** 12-bit, 3 × ADC peripherals (up to 16 channels each), ±2 LSB INL — adequate for all pots and CV modulation inputs
- **DAC:** 2 × 12-bit onboard DAC
- **I2S:** 2–3 × hardware I2S peripherals
- **USB:** USB OTG Full Speed — USB MIDI class device, no driver needed on Mac/Windows/Linux
- **Used in:** Mutable Instruments Clouds, Rings, Braids, Elements; Rebel Technology OWL — the proven Eurorack standard

### What the WeAct Board Provides
- **8 MHz HSE crystal** on PH0/PH1 — satisfies the USB clock requirement; feeds PLL to 168 MHz SYSCLK
- **32.768 kHz LSE crystal** on PC14/PC15 — RTC timekeeping
- **USB-C connector** on PA11 (D−) / PA12 (D+) — USB MIDI ready out of the box
- **3.3V LDO regulator** — digital supply for MCU; reduce digital power noise by adding a separate analog LDO (see Power Supply section below)
- **1× Blue LED** on PB2 — available for debug/status use
- **1× User button (KEY)** on PC13 (pull-down, active-high) — available for mode switching
- **MicroSD slot** via SDIO — available for patch/preset storage if needed

#### MicroSD SDIO Pin Allocation

| MicroSD pin | Signal | STM32 pin | Peripheral / AF |
|---|---|---|---|
| 1 (DAT2) | `SDIO_D2` | PC10 | SDIO_D2 (AF12) |
| 2 (CD/DAT3) | `SDIO_D3` | PC11 | SDIO_D3 (AF12) |
| 3 (CMD) | `SDIO_CMD` | PD2 | SDIO_CMD (AF12) |
| 4 (VDD) | `+3V3` | — | Decoupled with 100 nF close to slot |
| 5 (CLK) | `SDIO_CK` | PC12 | SDIO_CK (AF12) |
| 6 (VSS) | GND | — | — |
| 7 (DAT0) | `SDIO_D0` | PC8 | SDIO_D0 (AF12) |
| 8 (DAT1) | `SDIO_D1` | PC9 | SDIO_D1 (AF12) |

Card detect: NC (normally-closed) switch on MicroSD slot connects PA8 to GND when no card is present; inserting a card opens the switch. Internal pull-up on PA8 pulls it HIGH when the switch opens. Firmware reads PA8 as GPIO input with pull-up (HIGH = card inserted, LOW = no card).

On-board R11 100 kΩ pull-up on CD/DAT3 (PC11) keeps DAT3 high during card insertion to prevent spurious SPI-mode entry
- **SWD debug header** on PA13/PA14 — leave accessible for firmware development

### Pin Conflicts and Reservations

The following pins are consumed by on-board hardware and must not be reassigned to sequencer I/O:

| Pin(s) | Net name | Peripheral / AF | Notes |
|---|---|---|---|
| PH0, PH1 | — | HSE crystal | WeAct board; must remain unloaded |
| PC14, PC15 | — | LSE crystal | WeAct board; must remain unloaded |
| PA11, PA12 | — | USB OTG FS D−/D+ | WeAct board; keep 27 Ω series resistors populated |
| PA13, PA14 | — | SWD SWDIO/SWCLK | WeAct board; leave accessible for debug |
| PA0 | `CV-IN-A` | ADC1_IN0 | CV modulation input A (see `cv-input.md`) |
| PA1 | `CV-IN-B` | ADC1_IN1 | CV modulation input B (see `cv-input.md`) |
| PA2 | `CLK-IN` | TIM2_CH3 | Clock input capture (see `clock-input.md`) |
| PA3 | `GATE-OUT-A` | TIM2_CH4 | Gate A output compare (see `gate-output.md`) |
| PA8 | `SD_CD` | GPIO input | MicroSD card detect, NC switch with internal pull-up (HIGH = card inserted, LOW = no card) |
| PA5 | `OLED-SPI-SCLK` | SPI1_SCK (AF5) | OLED dedicated bus (see `user-interface.md` §1) |
| PA6 | `GATE-OUT-B` | TIM3_CH1 | Gate B output compare (see `gate-output.md`) |
| PA7 | `OLED-SPI-MOSI` | SPI1_MOSI (AF5) | OLED dedicated bus (see `user-interface.md` §1) |
| PA15 | `I2S3_WS` | I2S3_WS (AF6) | PCM5102A word select (see `audio-output-dac.md`) |
| PC1 | `OLED-RES` | GPIO output | OLED reset, active-low (see `user-interface.md` §1) |
| PC2 | `OLED-DC` | GPIO output | OLED data/command select (see `user-interface.md` §1) |
| PB1 | `DAC-SPI-CS` | GPIO output | DAC8552 SYNC, active-low (see `cv-output-dac.md`) |
| PB3 | `I2S3_BCK` | I2S3_CK (AF6) | PCM5102A bit clock (see `audio-output-dac.md`) |
| PB4 | `USR-ENC-SW` | GPIO EXTI | Encoder push switch (see `user-interface.md` §2) |
| PB5 | `I2S3_SD` | I2S3_SD (AF6) | PCM5102A serial data (see `audio-output-dac.md`) |
| PB6 | `USR-ENC-A` | TIM4_CH1 (AF2) | Encoder quadrature A (see `user-interface.md` §2) |
| PB7 | `USR-ENC-B` | TIM4_CH2 (AF2) | Encoder quadrature B (see `user-interface.md` §2) |
| PB12 | `OLED-SPI-CS` | GPIO output | OLED chip select, active-low (see `user-interface.md` §1) |
| PB13 | `DAC-SPI-SCLK` | SPI2_SCK (AF5) | DAC8552 clock (see `cv-output-dac.md`) |
| PB15 | `DAC-SPI-MOSI` | SPI2_MOSI (AF5) | DAC8552 data (see `cv-output-dac.md`) |
| PC0 | `USR-POT-1` | ADC1_IN10 | 100K pot wiper, U25 (see `user-interface.md` §3) |
| PC6 | `~MUTE` | GPIO output | PCM5102A ~XSMT (see `audio-output-dac.md`) |
| PC8 | `SDIO_D0` | SDIO_D0 (AF12) | MicroSD data 0 (WeAct board) |
| PC9 | `SDIO_D1` | SDIO_D1 (AF12) | MicroSD data 1 (WeAct board) |
| PC10 | `SDIO_D2` | SDIO_D2 (AF12) | MicroSD data 2 (WeAct board) |
| PC11 | `SDIO_D3` | SDIO_D3 (AF12) | MicroSD data 3 (WeAct board) |
| PC12 | `SDIO_CK` | SDIO_CK (AF12) | MicroSD clock (WeAct board) |
| PD2 | `SDIO_CMD` | SDIO_CMD (AF12) | MicroSD command (WeAct board) |

### Available GPIO for Sequencer Use

- **Port A:** PA4, PA9, PA10 (PA0/PA1 = CV in, PA2 = clock in, PA3 = gate A, PA5/PA7 = SPI1 OLED, PA6 = gate B, PA8 = SD card detect)
- **Port B:** PB0, PB2, PB8–PB11, PB14 (PB1 = `DAC-SPI-CS`, PB2 = LED shared, PB3 = `I2S3_BCK`, PB4 = `USR-ENC-SW`, PB5 = `I2S3_SD`, PB6/PB7 = `USR-ENC-A`/`USR-ENC-B`, PB12 = `OLED-SPI-CS`, PB13/PB15 = SPI2)
- **Port C:** PC3–PC5, PC7, PC13 (button, shared) (PC0 = `USR-POT-1`, PC1 = `OLED-RES`, PC2 = `OLED-DC`, PC8–PC12/PD2 = SDIO)
- **ADC-capable pins (12-bit):** PA0–PA7 (ADC1/2/3 inputs), PC0–PC5 (ADC1/2 inputs), PB0–PB1 (ADC1/2 inputs)
- **Reserve ADC pool:** PC3–PC5, PB0 — four ADC-capable pins for future pots, CV inputs, or sensors (PC1/PC2 consumed by OLED)
- **DAC outputs:** PA4 (DAC1) — onboard 12-bit; PA5 (DAC2) consumed by SPI1 OLED SCK. Supplemented by external 16-bit DAC for CV precision (see DAC section)
- **SPI buses:** SPI1 (PA5 SCK / PA7 MOSI) — OLED; SPI2 (PB13/PB15 + CS) — DAC8552
- **I2C buses:** I2C1 (PB8/PB9 — default PB6/PB7 consumed by TIM4 encoder), I2C2 (PB10/PB11)
- **Timers with PWM:** TIM1–TIM14; PWM available on most GPIO pins for RGB LED or gate timing

## RGB LED for Operating Mode Indication

**Problem:** The module has no visual feedback beyond the gate signals reaching downstream modules. With planned features (quantization on/off, scale selection, latch state, channel inversion mode), the operator has no way to read the current operating mode at a glance.

**Addition:** One common-cathode (or common-anode) RGB LED on the front panel, driven from 3 PWM-capable GPIO pins.

**Suggested colour mapping:**

| Colour | Mode |
|---|---|
| White / dim white | Default / unquantized LFSR output |
| Green | Quantization active, chromatic |
| Blue | Quantization active, diatonic scale |
| Cyan | Quantization active, pentatonic scale |
| Yellow | Lock latched (button pressed, pot frozen) |
| Red | Sequence fully locked (lock value at maximum) |
| Magenta | Channel 2 inversion active (switch) |

Colours can be mixed and brightness PWM-dimmed to indicate combined states (e.g. blue + yellow = quantized scale with latch active).

**Hardware requirements:**
- 3 PWM GPIO pins (one per channel R/G/B) with 3 current-limiting resistors (~100–330 Ω depending on LED spec).
- If GPIO PWM count is constrained, a single IS31FL3193 or PCA9685 I2C LED driver handles all three channels from one I2C bus.
- Panel footprint: standard 3mm or 5mm LED bezel, or a Lumex/ROHM SMD RGB in a daughterboard.
- Requires PWM support on the MCU — available on RP2040 (all GPIO support PWM) or SAMD21.

---

---

## STM32F405RGT6 Peripheral Stack

This section answers: given the WeAct STM32F405 core board, what external chips does the sequencer module still need?

### ADC — Built-in is sufficient

The STM32F405 has three independent 12-bit ADC peripherals with low INL (±2 LSB typical), running up to 1 MSPS each. F4 ADC is well-characterised with no known non-linearity pathologies near the rails. It is adequate for:

- All potentiometer readings (lock, steps, etc.)
- CV modulation inputs (lock CV per channel)
- Any non-pitch CV (steps CV, mod CV)

**No external ADC is needed** for this module's use case. The only scenario requiring an external ADC would be if a future revision adds a V/oct CV *input* for pitch tracking across 5+ octaves with sub-cent accuracy — at that point, a 16-bit ADC (e.g. ADS1115 via I2C) would be appropriate. For now, skip it.

The F405 can comfortably handle all existing CV inputs (CV_1, CV_2, LOCK, STEPS, SWITCH) and the new additions (reset trigger, extra lock CV) using built-in ADC channels.

### Crystal Oscillator — Already on WeAct board

The WeAct core board ships with an 8 MHz HSE crystal on PH0/PH1, which feeds the PLL to produce 168 MHz SYSCLK and the required 48 MHz USB clock (via PLLQ = 7). No crystal needs to be sourced or placed on the sequencer PCB.

---

### Power Supply — Partial (board provides digital 3.3V)

The WeAct board includes a 3.3V LDO that covers the MCU, USB, and DAC digital supply. The sequencer PCB still needs:

- **Analog 3.3V (separate):** Low-noise LDO with extra decoupling (e.g. MCP1700 or LT3042) for ADC VREF and DAC analog supply. Do not share the board's digital LDO — switching noise from the MCU couples into ADC readings.
- **Precision voltage reference:** For the DAC8552, an external 2.5 V precision reference (REF5025IDR, 3 ppm/°C) drives VREF at 2.500 V to set DAC full-scale. The board's onboard LDO is not stable enough to use as a DAC reference directly. See `cv-output-dac.md` for wiring.
- **Eurorack power input:** 10-pin (2×5, 2.54 mm pitch) "power-only" Doepfer header carrying ±12 V + GND only (no +5 V row, no CV/gate rows) — see `eurorackpower.png`. The WeAct board takes 5 V input; +5 V is generated locally from +12 V via the TPS54202 buck documented in `power-supply.md`.

---

### USB Connector — Already on WeAct board

The WeAct board has a USB-C connector on PA11/PA12 with the required series resistors. USB MIDI class device works without any additional USB hardware on the sequencer PCB. Route the USB-C port to the Eurorack front panel via a short flex cable or panel-mount USB-C extension.

---

### Non-Volatile Storage — Flash Pages Sufficient

The STM32F405 has 1 MB onboard flash. User settings (scale presets, calibration offsets, lock latch state) can be stored in the last few flash pages (each page = 16 KB on F405) without an external EEPROM. No external storage chip needed.

---

### Summary: External Chip BOM for WeAct STM32F405 Build

Items already provided by the WeAct core board are marked accordingly.

| Chip / Component | Purpose | Interface | Needed on sequencer PCB? |
|---|---|---|---|
| STM32F405RGT6 MCU | Main processor | — | No — on WeAct board |
| 8 MHz HSE crystal | USB + PLL clock | — | No — on WeAct board |
| 32.768 kHz LSE crystal | RTC | — | No — on WeAct board |
| USB-C connector | USB MIDI | — | No — on WeAct board (route to panel via extension) |
| Digital 3.3V LDO | MCU/USB power | — | No — on WeAct board |
| External ADC | Precision CV input | SPI/I2C | No — F405 built-in ADC is sufficient |
| DAC8552IDGKR (16-bit dual DAC) | CV outputs | SPI2 (dedicated) | **Yes** |
| OPA1642AIDR (dual JFET, RRO, LCSC C67640) | DAC output buffering + ×4 gain to 0–10 V | Analog | **Yes** |
| REF5025IDR (precision 2.5 V ref) | DAC VREF, powered from +3V3_PREC | — | **Yes** (for pitch accuracy) |
| Low-noise analog LDO | Separate analog 3.3V rail for ADC/DAC | — | **Yes** |
| PCM5102APWR | Audio I2S output (see `audio-output-dac.md`) | I2S3 | **Yes** |
| SSD1327 OLED 1.5″ 128×128 4-bit grayscale | Menu / status display | SPI1 (dedicated) | **Yes** |
| Alps Alpine EC11E18244AU | Menu navigation, parameter adjust, confirm (rotary encoder w/ push) | TIM4 encoder mode (PB6/PB7) + GPIO EXTI (PB4 switch) | **Yes** |
| Alps Alpine 100K linear pot (RK09K or equiv.) | General-purpose parameter knob, firmware-assignable | ADC1_IN10 (PC0) | **Yes** |

---

### Input Hardware

**Alps Alpine EC11E18244AU — incremental rotary encoder with push switch**
- 11 mm EC11E series, 24 detents/revolution, 24 pulses/revolution, integrated momentary push switch on the shaft
- Quadrature outputs A/B → PB6/PB7 (TIM4_CH1/CH2, AF2); decoded in hardware via TIM4 encoder mode — zero CPU overhead, counter auto-increments in hardware
- Common pin (between A and B) → GND
- Push switch → PB4, GPIO with internal pull-up (active-low on press), EXTI interrupt
- Use: rotate to navigate menu items / adjust the selected parameter value, press to confirm/enter and back out of sub-menus (short vs long press in firmware)
- Single-control UX: menu state machine distinguishes "navigation mode" (rotate moves highlight) from "edit mode" (rotate changes value); press toggles between them

**Debouncing:** The EC11E encoder contacts bounce (~5 ms typical). Handle the push switch in firmware (5–10 ms software debounce). TIM4 encoder mode's input filter (ICFilter) provides hardware-level bounce rejection on A/B; the external 10 nF caps to GND on A, B, and the switch pin add RF immunity in a Eurorack environment.

**Alps Alpine 100K linear potentiometer (RK09K1130C0L or equivalent 9 mm vertical PCB-mount), designator U25**
- Wiper → PC0 (ADC1_IN10), CW terminal → +3V3, CCW terminal → GND
- C46 100 nF on wiper to GND as ADC charge reservoir + noise filter
- Firmware-assignable: the ADC reading maps to whichever parameter is currently selected or assigned via the menu
- Added to the ADC1 scan group after PA0/PA1 (CV inputs); 8–16× moving average in firmware for stable readings

See `user-interface.md` for full wiring, decoupling, and firmware details.

### Display Hardware

**Selected: Waveshare 1.5″ SSD1327 OLED, 128×128, 4-bit grayscale, SPI**
- Controller: SSD1327 (Solomon Systech) — 4-bit grayscale (16 levels per pixel); see `datasheets/SSD1327.md`
- SPI mode: 4-wire (SCK, MOSI, CS, DC) + RES; no MISO needed — display is write-only
- SPI Mode 0 (CPOL=0, CPHA=0), max 10 MHz SCLK; dedicated SPI1 bus (PA5 SCK, PA7 MOSI) — no mode conflict with DAC8552 (Mode 1 on SPI2)
- 3.3V logic supply (VDD), ~15–30 mA typical; panel VCC from on-board boost converter
- GDDRAM: 8192 bytes (two pixels per byte, upper/lower nibble). Full framebuffer transfer at 10 MHz: ~6.6 ms
- 128×128 px fits 5–6 menu lines at 8px font or 3–4 lines at 16px, plus a status bar; grayscale enables smooth UI for waveforms, bar graphs, and highlighted selections
- Module dimensions: ~44.5 mm × 37 mm PCB; visible area ~27mm × 27mm — suits a 10 HP panel
- **Dedicated bus:** OLED runs on SPI1 (PA5 SCK / PA7 MOSI), separate from the DAC8552 on SPI2. This eliminates SPI mode switching and allows concurrent DMA transfers (SPI1 on DMA2, SPI2 on DMA1) — the 6.6 ms OLED framebuffer write never blocks timing-critical DAC updates
- **Driver:** U8g2 `U8G2_SSD1327_WS_128X128` or Adafruit SSD1327 (SPI mode); not register-compatible with SSD1306 or SH1107

### Pin Budget

| Net name | Pin | Peripheral / AF |
|---|---|---|
| `CV-IN-A` | PA0 | ADC1_IN0 |
| `CV-IN-B` | PA1 | ADC1_IN1 |
| `CLK-IN` | PA2 | TIM2_CH3 input capture |
| `GATE-OUT-A` | PA3 | TIM2_CH4 output compare |
| `OLED-SPI-SCLK` | PA5 | SPI1_SCK (AF5) |
| `GATE-OUT-B` | PA6 | TIM3_CH1 output compare |
| `OLED-SPI-MOSI` | PA7 | SPI1_MOSI (AF5) |
| `SD_CD` | PA8 | GPIO input, internal pull-up (HIGH = card inserted) |
| `I2S3_WS` | PA15 | I2S3_WS (AF6) |
| `DAC-SPI-CS` | PB1 | GPIO output, active-low |
| `I2S3_BCK` | PB3 | I2S3_CK (AF6) |
| `USR-ENC-SW` | PB4 | GPIO EXTI, pull-up |
| `I2S3_SD` | PB5 | I2S3_SD (AF6) |
| `USR-ENC-A` | PB6 | TIM4_CH1 (AF2) |
| `USR-ENC-B` | PB7 | TIM4_CH2 (AF2) |
| `OLED-SPI-CS` | PB12 | GPIO output, active-low |
| `DAC-SPI-SCLK` | PB13 | SPI2_SCK (AF5) |
| `DAC-SPI-MOSI` | PB15 | SPI2_MOSI (AF5) |
| `USR-POT-1` | PC0 | ADC1_IN10 |
| `OLED-RES` | PC1 | GPIO output |
| `OLED-DC` | PC2 | GPIO output |
| `~MUTE` | PC6 | GPIO output, active-low |
| `SDIO_D0` | PC8 | SDIO_D0 (AF12) |
| `SDIO_D1` | PC9 | SDIO_D1 (AF12) |
| `SDIO_D2` | PC10 | SDIO_D2 (AF12) |
| `SDIO_D3` | PC11 | SDIO_D3 (AF12) |
| `SDIO_CK` | PC12 | SDIO_CK (AF12) |
| `SDIO_CMD` | PD2 | SDIO_CMD (AF12) |

All pins are drawn from the free GPIO pool. The OLED uses a dedicated SPI1 bus (PA5/PA7) — separate from DAC8552 on SPI2 (PB13/PB15) — so there is no bus contention or SPI mode conflict. I2S3 is on PB3/PB5 (AF6) to avoid conflict with the onboard SDIO (PC8–PC12). PB6/PB7 provide TIM4 hardware encoder mode (CH1/CH2). OLED-DC and OLED-RES moved to PC2/PC1 respectively.

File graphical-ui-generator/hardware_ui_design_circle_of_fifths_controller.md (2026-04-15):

# Hardware UI Design – Circle of Fifths Controller

## Overview
This document defines a minimal, coherent hardware UI using:
- 1x Rotary Encoder (with push button)
- 1x Potentiometer

The goal is to control harmonic content (keys, progressions, modes) in a way that aligns with music theory and user intuition.

---

## Core Design Principles

- **Encoder = discrete harmonic movement**
- **Pot = continuous variation (tension / complexity)**
- **Button = context switching (mode layer)**

Avoid overlapping responsibilities between controls.

---

## Control Mapping

### 🎛 Rotary Encoder → Key (Circle of Fifths)

Each detent moves one step around the circle:

- Clockwise → +1 fifth (C → G → D → A…)
- Counterclockwise → −1 fifth (C → F → Bb → Eb…)

#### Controls:
- Global key center
- Key signature
- Diatonic chord set

#### Rationale:
- Matches the structure of the circle of fifths
- Produces musically valid transitions
- Keeps harmonic context consistent

---

### 🎚 Potentiometer → Harmonic Complexity / Progression Shape

Maps continuously to progression complexity:

| Position | Behaviour |
|---|---|
| 0% | Static (I only) |
| 25% | Simple (I–V) |
| 50% | Pop baseline (I–V–vi–IV) |
| 75% | Circle motion (I–IV–vii°–iii–vi–ii–V) |
| 100% | Extended / jazz (secondary dominants, ii–V chains) |

#### Controls:
- Number of chords
- Functional movement
- Harmonic tension

#### Rationale:
- Continuous control suits a pot
- Maps naturally to “more vs less movement”
- Avoids arbitrary parameters

---

### 🔘 Encoder Push Button → Mode Switching

Short press cycles between modes.

---

## Modes

### Mode 1: Key Select (Default)

- Encoder → Key (circle of fifths)
- Pot → Progression complexity

---

### Mode 2: Scale / Mode Selection

- Encoder → Select mode:
  - Ionian (Major)
  - Dorian
  - Phrygian
  - Lydian
  - Mixolydian
  - Aeolian (Minor)
  - Locrian

- Pot → Modal intensity:
  - Degree of modal mixture
  - Borrowed chord usage

---

### Mode 3: Playback / Step Control

- Encoder → Step through progression
- Pot → Tempo control

---

## Simplified Variant (Recommended for v1)

If complexity needs to be reduced:

- Encoder → Key (circle)
- Pot → Progression complexity
- Button → Play / Stop OR regenerate progression

#### Rationale:
- Lower implementation complexity
- More robust UX
- Faster iteration

---

## Interaction Enhancements

### Encoder Acceleration

- Slow rotation → single step
- Fast rotation → skip multiple steps

#### Benefit:
- Faster navigation across keys
- Improved responsiveness

---

### Smooth Transitions

- Key changes → transpose existing progression
- Pot changes → morph progression instead of replacing

#### Benefit:
- Feels like an instrument, not a preset selector

---

## Anti-Patterns (Avoid)

### ❌ Encoder = direct chord selection
- Breaks harmonic context
- Confuses users

### ❌ Pot = key selection
- Continuous input unsuitable for discrete pitch

### ❌ Button = major/minor toggle only
- Wastes limited input bandwidth

---

## Mental Model

Think of the system as:

- **Encoder → position in harmonic space**
- **Pot → amount of movement / tension**

If both controls attempt to select discrete states, the UI becomes ambiguous.

---

## Implementation Notes (Optional)

- Represent circle of fifths as a cyclic array
- Store chord sets per key + mode
- Use interpolation or rule-based morphing for progression changes
- Maintain separation between:
  - Key state
  - Mode state
  - Progression generator

---

## Summary

This design:
- Aligns physical controls with music theory
- Minimizes cognitive load
- Scales from simple to advanced usage
- Avoids common UI pitfalls

The result is a compact but expressive harmonic control interface.

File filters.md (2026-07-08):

# Filters — velocity-driven envelope filter for keyboard play

This document specifies the Tachyon's filter subsystem. The first deliverable
is a classic **envelope filter**: a per-voice lowpass whose cutoff is swept by
a velocity-scaled ADSR, so playing the USB-MIDI keyboard harder opens the
filter (and the note is louder). Later phases extend the same building blocks
to other filter types and modulation sources.

Source references / modules this builds on:
- `Core/IO/audio.c` — I2S render seam: ~192 kHz (`AUDIO_FS_HZ`), 128-frame
  blocks (`HALF_FRAMES`), render callback runs in the DMA Tx IRQ (≈667 µs
  deadline per block, see the `O3` note in `wt_osc.c`)
- `Core/IO/wt_osc.c` — 4-voice wavetable oscillator; the filter and envelope
  live inside its voice loop
- `Core/UI/app.c` — USB-MIDI event ring already carries `vel`, currently
  dropped in `midi_note_on()` ("Velocity is ignored for now")
- `usb-midi.md` §5 — flags per-voice velocity as a future `wt_osc` extension
- `firmware/test/` — host Unity/CTest suite; the new DSP modules are pure C
  and get host tests like `arp.c` and `wav.c` do

---

## 1. Concept

Today a voice is `wavetable → gain → sum`. Note-on resets phase (clean
attack); note-off zeroes `active` (a hard cut, which clicks). This plan makes
each voice:

```
             ┌───────────┐    ┌─────────────┐    ┌───────────┐
  note ───▶  │ wavetable │ ─▶ │  SVF (LP)   │ ─▶ │ VCA gain  │ ─▶ sum
             └───────────┘    └─────────────┘    └───────────┘
                                    ▲                  ▲
                              cutoff = base      level = env
                              × 2^(amt·env·vel)  × vel curve
                                    │                  │
                              ┌─────┴──────────────────┴───┐
  gate/velocity ────────────▶ │      per-voice ADSR        │
                              └────────────────────────────┘
```

- **One ADSR per voice**, triggered by note-on with that note's velocity,
  released by note-off. Phase 1 routes the single envelope to **both** the
  filter cutoff and the voice amplitude (Minimoog-style shared contour). A
  separate filter envelope is a later phase — one envelope already gives the
  target behaviour (velocity → brightness + loudness) and fixes the note-off
  click for free.
- **One SVF per voice**, because velocity is per note: two notes at different
  velocities must sound different brightnesses simultaneously. A single
  filter on the mix (paraphonic) is the documented fallback if the CPU
  budget fails (§6), not the design.
- Envelope and cutoff are evaluated at **block rate** (128 frames ≈ 0.67 ms —
  well above any audible envelope granularity); only the filter state update
  runs per sample.

---

## 2. Modules

Two new pure-C modules, no HAL includes, so they compile host-side unchanged
(same pattern as `arp.c`):

### 2.1 `Core/DSP/adsr.{c,h}`

```c
typedef struct { float a_coef, d_coef, r_coef, sustain; } adsr_params_t;
typedef struct { float level; uint8_t stage; } adsr_t;   /* per voice */

void  adsr_config(adsr_params_t *p, float a_ms, float d_ms,
                  float sustain, float r_ms);            /* main loop */
void  adsr_gate_on(adsr_t *e);        /* (re)attack from current level */
void  adsr_gate_off(adsr_t *e);
float adsr_step(adsr_t *e, const adsr_params_t *p);      /* one block tick */
bool  adsr_idle(const adsr_t *e);     /* fully released — voice reclaimable */
```

- Stages: idle → attack → decay → sustain → release. Exponential segments
  (one-pole toward a target), the standard analog-feel shape:
  `level += coef * (target - level)`, with attack overshooting toward ~1.27
  so it actually reaches 1.0 in the nominal time.
- Coefficients are derived from times at the **block rate**
  (`AUDIO_FS_HZ / HALF_FRAMES` ≈ 1.5 kHz), computed in `adsr_config()` on the
  main loop — the IRQ path never calls `expf`.
- Time ranges log-scaled: A 1 ms–5 s, D/R 5 ms–10 s, S 0–1.
- Retrigger attacks **from the current level** (no reset to 0) so fast
  re-strikes don't click.
- Release-to-idle threshold ≈ −80 dB (1e-4); at idle the voice is silent and
  reclaimable.

### 2.2 `Core/DSP/svf.{c,h}`

Zavalishin/Simper **TPT state-variable filter** — stable under fast cutoff
modulation (an envelope sweep is exactly that), cheap, and gives LP/BP/HP
from the same state for later phases.

```c
typedef struct { float g, k; } svf_coef_t;    /* shared per voice-block */
typedef struct { float ic1, ic2; } svf_t;     /* per voice state */

void  svf_coef(svf_coef_t *c, float fc_hz, float res, float fs_hz);
float svf_lp(svf_t *s, const svf_coef_t *c, float x);  /* per sample */
void  svf_reset(svf_t *s);
```

- `g = tan(pi * fc / fs)`, `k = 2 - 2*res`. At 192 kHz even fc = 20 kHz is
  only fs/9.6, so a short polynomial `tan` approximation is accurate across
  the whole audible range — no lookup table needed. `svf_coef()` runs at
  block rate; verify on the bench whether the approximation is needed at all
  or plain `tanf` fits the budget.
- `res` 0–1, clamped below self-oscillation (k ≥ ~0.06, Q ≈ 16) in phase 1.
- fc clamped to [20 Hz, 20 kHz].
- Per-sample cost ≈ 9 flops. Worst case 4 voices × 128 samples ≈ 4.6 k flops
  per block — tens of µs at 168 MHz under `O3`, comfortably inside the
  667 µs deadline. Confirmed by measurement in phase 3, not assumed (§6).

---

## 3. Voice integration (`wt_osc.c`)

### 3.1 Voice struct additions

`wt_voice_t` gains: `adsr_t env`, `svf_t filt`, `float vel` (0–1), and the
block snapshot in `wt_render()` carries the per-voice gain and `svf_coef_t`
for the block.

### 3.2 Render loop changes

Per block, per active voice (before the sample loop):
1. `e = adsr_step(&v->env, &params)`
2. `fc = base_cutoff * exp2f(env_amount_oct * e * v->vel)` — cutoff in
   octaves above the base, scaled by envelope and velocity
3. `svf_coef(...)` for this block
4. voice gain `= WT_OUT_GAIN * e * vel_curve(v->vel)`
5. if `adsr_idle()` after release → clear `active` (voice reclaimed)

Per sample, per voice: existing table lookup → `svf_lp()` → accumulate with
the block gain. One `exp2f` + one coefficient computation per voice per
block is main-cost-free next to the sample loop.

Block-rate coefficient stepping (rather than per-sample smoothing) is the
phase-1 answer to zipper noise; at a 1.5 kHz update rate with an exponential
envelope this is inaudible for cutoff. If a fast full-range attack sweep
audibly steps, linear-interpolate `g` across the block as a follow-up.

### 3.3 Note lifecycle changes (the semantic shift)

This is the real behavioural change and needs care:

- **`wt_osc_note_off()` no longer silences** — it calls `adsr_gate_off()`;
  the voice keeps sounding through its release and frees itself when the
  envelope idles (render clears `active`).
- **Voice allocation** (`alloc_voice()`): prefer a truly idle voice, then the
  quietest *releasing* voice, then steal the oldest as today. A stolen voice
  hard-retriggers (envelope re-attacks from its current level — no click).
- **`wt_osc_all_off()` / mode switches**: forcing every envelope into a fast
  release (~5 ms) instead of an instant cut kills the mode-change click too;
  `wt_osc_set_multisample()` keeps the hard cut (the table pointer is going
  away under the voice).

### 3.4 API — velocity plumbing

```c
void wt_osc_note_on(int midi_note, float freq_hz, uint8_t vel);  /* 1..127 */
```

- Existing call sites and the mono helpers (`wt_osc_note`,
  `wt_osc_set_pitch`, `wt_osc_chord`) pass a default velocity (100); the arp
  and CV paths get real dynamics in a later phase (arp accent).
- `app.c midi_note_on()` drops its `(void)vel;` and forwards the value —
  update the "velocity is ignored" comments here, in `app.h`, and in
  `usb-midi.md` §5 (this doc supersedes that note).
- The **CV free-run path** (`wt_osc_set_pitch`) must keep gating exactly as
  today: it re-gates only on a fresh note, never per pitch update, so glides
  don't retrigger the envelope.
- A **bypass** (`filter enabled: off`) preserves today's exact render path —
  the safe default until the feature is proven, and the A/B for CPU and
  sound checks.

### 3.5 Velocity mapping

Velocity is normalised (`v = vel/127.0f`) and routed to **exactly one
destination**, selected by the `VelMode` parameter (§4.1 row 8). The modes,
with `S` = the configured sustain level:

| Mode | Velocity drives | Mapping |
|---|---|---|
| **Volume** (default) | voice level | `gain × v^1.5` (perceptual curve) |
| **AtkAmt** | the A/D transient above sustain | `env' = S + (env − S)·v` for `env > S`; sustain & release unchanged |
| **AtkDec** | the whole contour, sustain included | `env' = env·v` |
| **FltEnv** | the cutoff sweep depth | `fc = base × 2^(EnvAmt·env·v)`; level follows the raw envelope |
| **AtkTime** | attack time | `t = attack_ms × (1−v)`, clamped ≥ 1 ms — harder = snappier |

- The routing is exclusive: in every mode but Volume, loudness follows the
  (possibly velocity-shaped) envelope only. AtkAmt/AtkDec shape the shared
  contour, so they are heard on both brightness and level.
- Per-note values (`vel_gain`, attack coef) are baked at note-on on the main
  loop; a mode or attack edit rebakes sounding voices so it is heard
  immediately. AtkAmt/AtkDec/FltEnv shaping runs at block rate in the render.
- Velocity curve selection (soft/linear/hard) is a later phase; linear
  scaling first.

---

## 4. Parameters & UI

### 4.1 Parameters

| # | Param | Range | Default |
|---|---|---|---|
| 0 | Filter | off / LP | LP |
| 1 | Cutoff (base) | 20 Hz – 20 kHz, log | 400 Hz |
| 2 | Resonance | 0 – 100 % | 15 % |
| 3 | Env amount | 0 – +7 oct | +4 oct |
| 4 | Attack | 1 ms – 5 s, log | 5 ms |
| 5 | Decay | 5 ms – 10 s, log | 300 ms |
| 6 | Sustain | 0 – 100 % | 60 % |
| 7 | Release | 5 ms – 10 s, log | 200 ms |
| 8 | VelMode | Volume / AtkAmt / AtkDec / FltEnv / AtkTime (§3.5) | Volume |

Defaults are chosen so plugging in a keyboard immediately gives the classic
"harder = louder" response with the envelope sweeping the filter at full
depth. Live pot → cutoff (à la user-interface.md §3 pot handling) is a
candidate follow-up, not phase 1.

### 4.2 Menu placement

The Config submenu (`render_config_menu()`) gains a third entry:
`Arp Cfg / Audio Cfg / Filter Cfg`, opening a new `APP_SCREEN_FILTER_CFG`.
The envelope lives on this screen too — it is the *filter's* contour (§1),
so a separate "Env Cfg" screen would split one instrument-feature across two
menus for no gain.

### 4.3 Filter Cfg screen

Same anatomy as Arp Cfg: 14 px header bar ("Filter Cfg"), one `Name: value`
row per parameter (Font12, 15 px pitch). Nine parameters don't fit the
~7 rows below the header, so the list **scrolls in a window** exactly like
the wavetable browser (`render_browse()` keeps the cursor centred and clamps
the window at the ends). All nine params — including the four envelope rows —
are plain list rows; nothing modal beyond the shared edit state.

Row rendering follows the Arp Cfg convention:

```
Filter:  LP
Cutoff:  400 Hz
Res:     15%
EnvAmt:  +4.0 oct
Attack: [5 ms]        <- cursored + editing: inverted bar, value in brackets
Decay:   300 ms
Sustain: 60%
                       (Release, VelMode scrolled below)
```

### 4.4 Encoder controls

Identical interaction grammar to Arp Cfg (`APP_SCREEN_ARP_CFG` handling in
`app_tick`), so nothing new to learn:

| Input | Not editing | Editing |
|---|---|---|
| rotate | move cursor (wrap) | adjust value, one step per detent |
| short press | on/off row (Filter): toggle in place, like `AP_CLK`; value rows (VelMode included): enter edit (brackets on) | confirm, leave edit |
| long press | back to Config | leave edit first (stay on screen) |

Value steps per detent:
- **Cutoff**: multiplicative, 12 steps/octave (≈ semitone resolution, ~120
  detents end-to-end; fine enough to dial a formant, coarse enough to sweep).
- **Attack / Decay / Release**: multiplicative ×1.12 per detent (~72/62/62
  detents across their log ranges), snapped for display.
- **Resonance / Sustain / Env amount**: linear — 2 %, 2 %, 0.25 oct.

Display formatting: times < 1 s as integer ms (`5 ms`, `300 ms`), ≥ 1 s as
seconds with one decimal (`1.5 s`); cutoff < 1 kHz as Hz, above as kHz with
one decimal (`2.4 kHz`).

### 4.5 Live edits

Edits apply **immediately** to sounding voices — hold a chord and dial the
release or sweep the cutoff to hear it. Mechanically free with §2's design:
the UI writes the shared `adsr_params_t` / base-cutoff / res from the main
loop; the render reads them at block rate, and single-float writes are
atomic on the M4 so no critical section is needed (same discipline as
`s_level`). The one exception is `Filter: off→on/on→off`, which hard-cuts
all sounding notes and resets per-voice envelope + SVF state under the
usual short `__disable_irq()` — the two render paths must not inherit each
other's state (a note carried across would jump or swell in level), so the
toggle trades a momentary silence for determinism.

### 4.6 Envelope preview (step-4 polish, optional)

When the cursor sits on an envelope row, draw a small ADSR shape
(~120 × 24 px, `Paint_DrawLine` segments) in place of the hint line at the
bottom: attack ramp, decay curve to the sustain plateau, release tail, with
the segment being edited drawn thicker. Cheap to render, and makes the four
time/level numbers legible as one shape. Nice-to-have — the numeric rows are
the deliverable.

---

## 5. Host tests (`firmware/test/`)

`test_adsr.c` and `test_svf.c`, compiled with the modules directly (as
`test_arp` does). Property-style assertions with tolerances — no
sample-exact golden vectors:

**ADSR**: attack reaches ≥0.99 within the configured time ±10 %; decay
settles to sustain; release decays to idle and `adsr_idle()` flips; retrigger
mid-release starts from current level (no discontinuity > step size); output
always in [0, ~1]; zero-length attack doesn't divide by zero.

**SVF**: DC in → DC out unchanged at any cutoff (LP passes DC); signal well
above cutoff attenuated (sine at 8×fc down ≥ 20 dB); silence in → decays to
silence (stability, no NaN/denormal blowup) across the full fc × res corner
grid, including per-block cutoff jumps from 20 Hz to 20 kHz (modulation
stability — the property TPT buys us); resonance boosts a sine at fc
monotonically with `res`.

---

## 6. CPU budget — measured, not assumed

The render already needs `O3` to meet the 667 µs block deadline.

- **Measurement (implemented)**: `wt_render()` is timed with the DWT cycle
  counter; `wt_osc_render_max_us()` returns the worst block since the last
  call. The Filter Cfg screen shows it live, right-aligned in the header —
  play a 4-note chord with the filter on and read the number.
- Budget target: ≤ 50 % of the block period (≤ ~330 µs) at 4 voices, leaving
  room for the chord engine and future mod sources. Record the measured
  worst case here after hardware bring-up: **TBD µs**.
- **Fallback if over budget** (in order): tan approximation instead of
  `tanf`; single paraphonic SVF on the mix (envelope from the newest note's
  velocity); reduce to 2× oversampled internal rate. Decision recorded here.

---

## 7. Later phases (out of scope for the envelope filter)

- **Filter types**: BP / HP outputs of the same SVF (free), LP/BP/HP morph.
- **Separate filter & amp envelopes** (two ADSRs per voice).
- **Keytracking**: cutoff follows note pitch (0 / 50 / 100 %).
- **CV-IN → cutoff**: `analog_in` CV modulates base cutoff — the Eurorack
  move; needs block-rate smoothing of the CV value.
- **Arp accent → velocity**: per-step velocity pattern in `arp.c`.
- **Drive**: soft saturation into the filter input.
- **LFO → cutoff**: shared LFO module, also useful for pitch/wavetable mod.

---

## 8. Implementation order

1. **`adsr.c` + host tests** — pure module, no firmware wiring. ✔ done
2. **`svf.c` + host tests** — pure module, includes the modulation-stability
   corner grid. ✔ done
3. **`wt_osc` integration** — voice struct, render loop, note lifecycle
   (release/steal semantics), velocity API + `app.c` plumbing, bypass
   switch. ✔ done — pending on-hardware verification: no clicks on
   note-off, velocity audibly opens the filter, CV free-run unaffected,
   block time within budget (§6).
4. **Filter Cfg screen** — Config submenu entry, scrolling param list with
   the cursor/edit encoder grammar, live-edit semantics (§4). ✔ done —
   the envelope preview (§4.6) not implemented yet. Note: parameters reset
   to defaults at boot; nothing in the firmware persists settings today
   (FatFs is compiled read-only), matching the arp/audio config screens.
5. Doc sweep: update `usb-midi.md` §5, `wt_osc.h` header comment, README
   feature list. ✔ done

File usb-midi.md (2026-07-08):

# USB-MIDI Device — play the wavetable synth from a USB-MIDI source

This document specifies the **USB MIDI** operating mode: the Tachyon
enumerates over its WeAct USB-C port as a **class-compliant USB-MIDI
device**, and a host (a PC running a DAW, or any USB-MIDI controller
routed through one) plays the polyphonic wavetable voice over USB.

The note sources are the Key wheel, the Chord wheel, and USB MIDI.
CV-IN (`cv-input.md`) is a modulation input only — it is not a harmonic
source. CV *output* (`CV-OUT-A`, gates) is driven by the Key/Chord arp
modes.

Source references / modules this builds on:
- `Core/IO/wt_osc.c` / `wt_osc.h` — polyphonic wavetable voice; the
  `wt_osc_note_on()` / `wt_osc_note_off()` pair is documented for exactly
  this "incremental / MIDI-style" use.
- `harmony-engine.md` — the `mode = (source × engine)` pipeline this
  plugs a new source into.
- `Core/UI/app.c` — the menu / mode state machine.
- `USB_DEVICE/` — the existing ST USB **device** stack (currently CDC).
- `power-supply.md` §5 — the WeAct onboard 3V3 LDO and how the board is
  powered; relevant to the "device, not host" power note below.

---

## 1. Why device-mode (and not host)

Three options were weighed for getting note data in:

| Option | HW change | FW effort | Standalone | Keeps debug |
|---|---|---|---|---|
| **USB-MIDI device → PC** (chosen) | none | small | ✗ needs PC | flag (§3) |
| TRS/DIN MIDI in (UART + optocoupler) | 1 jack + opto | small | ✓ | ✓ |
| USB host → keyboard | VBUS rework | large | ✓ | ✗ |

Device-mode wins on effort: the port is **already** a USB device, so
there is no enumeration code to write (the host enumerates *us*), no
VBUS sourcing problem, and no Type-C CC rework. The cost is that a
computer has to sit in the signal path. TRS-MIDI-in remains the cheapest
path to a *standalone* instrument and is kept on the table as a future
addition; it is orthogonal to this spec (different transport, same voice
routing in §5).

---

## 2. Hardware — no change

The WeAct USB-C port stays wired exactly as drawn (device/sink):

- `PA11`/`PA12` = `USB_OTG_FS_DM`/`DP` — unchanged; the OTG core stays in
  **device** role.
- `CC1`/`CC2` 5.1 kΩ pulldowns (Rd) — **correct** for a device.
- VBUS is an **input**, supplied by the host PC. The board's own power
  comes from the Eurorack buck (`+5 V → WeAct VIN`); the WeAct's `D4`
  Schottky isolates the PC's VBUS from the local 5 V rail, so the two
  5 V sources coexist exactly as they already do today whenever the CDC
  debug console is plugged in. No new power work.

(For contrast: *host* mode would have required driving 5 V out onto the
receptacle VBUS pin to power a keyboard — feeding the buck to the
connector-side VBUS net, not the post-`D4` VCC node — plus Rd→Rp. None
of that applies here.)

---

## 3. USB personality + the `USB_SERIAL_DEBUG` build flag

The OTG-FS port is a **single** USB device — it can be CDC *or* MIDI, not
both (a composite CDC+MIDI device was considered and rejected: the IAD
descriptor and shared endpoint dispatch are the most error-prone part of
the whole feature, and they only buy USB-side debug). The two
personalities are selected at **compile time**:

| `USB_SERIAL_DEBUG` | USB enumerates as | `printf` goes to | Use |
|---|---|---|---|
| **0 (default)** | MIDI device (this spec) | **SWO / ITM** | normal / play |
| **1** | CDC virtual COM port (today's behaviour) | USB CDC | bench debugging |

**CMake option** (in `firmware/CMakeLists.txt`):
```cmake
option(USB_SERIAL_DEBUG "USB enumerates as a CDC serial console instead of the MIDI device" OFF)
if(USB_SERIAL_DEBUG)
    target_compile_definitions(${CMAKE_PROJECT_NAME} PRIVATE USB_SERIAL_DEBUG=1)
endif()
```

**Code gating** — three `#if USB_SERIAL_DEBUG` sites:
- `MX_USB_DEVICE_Init` (`usb_device.c`): register `USBD_CDC` + the CDC
  interface, **else** register `USBD_MIDI`.
- `usbd_desc.c`: device-descriptor class triple
  (`0x02/0x02/0x00` CDC **vs** `0x00/0x00/0x00` "class at interface" for
  MIDI) and the product string (`"…Virtual ComPort"` vs `"Tachyon MIDI"`).
- `_write` (`main.c`): the CDC `while(CDC_Transmit_FS()==BUSY)` path
  **vs** `ITM_SendChar()` (SWO). The CDC retarget must move behind the
  flag regardless, because `CDC_Transmit_FS` does not exist in the MIDI
  build.

**Build-flash step** — a `-UsbSerialDebug` switch on `flash.ps1`:
```powershell
./flash.ps1 -Build                 # MIDI device build (default)
./flash.ps1 -Build -UsbSerialDebug # CDC serial-console build
```
The switch configures the flag and builds into a dedicated
`build/Debug-usbserial` directory so the two variants don't thrash each
other's CMake cache, then flashes that ELF over SWD. (If the `build/`
dirs turn out to be CubeIDE-configured rather than plain-`cmake`, the
flag falls back to a one-line `#define` in a small `usb_personality.h`
header — same compile-time switch, no reconfigure needed.)

**Debug pin:** SWO is `PB3` (TRACESWO); confirm it is broken out on the
WeAct header and that the ST-Link supports SWV. If not, the SWO branch
can instead retarget to a spare UART, or be stubbed (debugger-only).

---

## 4. MIDI device descriptors (USB-MIDI 1.0, MIDI-only)

A standard class-compliant USB-MIDI 1.0 device. Endpoint budget on
OTG-FS FS (EP0 control + EP1) — only one bulk pair is needed, so this
fits comfortably:

| Endpoint | Dir | Type | Use |
|---|---|---|---|
| EP0 | IN/OUT | Control | enumeration / standard requests |
| EP1 | OUT | Bulk (64 B) | host → device MIDI (**the notes we play**) |
| EP1 | IN | Bulk (64 B) | device → host MIDI (declared for compliance; unused initially) |

**Config descriptor layout** (~101 bytes):
```
Configuration
├─ Interface 0  AudioControl (class 0x01, subclass 0x01)
│   └─ CS AC header → references the MIDIStreaming interface
└─ Interface 1  MIDIStreaming (class 0x01, subclass 0x03)
    ├─ CS MS header
    ├─ MIDI IN  Jack  (Embedded)   id 1
    ├─ MIDI IN  Jack  (External)   id 2
    ├─ MIDI OUT Jack  (Embedded)   id 3  ← sourced from External-IN  (2)
    ├─ MIDI OUT Jack  (External)   id 4  ← sourced from Embedded-IN  (1)
    ├─ Bulk OUT endpoint (EP1 OUT) + CS-endpoint → Embedded-IN jack 1
    └─ Bulk IN  endpoint (EP1 IN)  + CS-endpoint → Embedded-OUT jack 3
```

Device descriptor: `bDeviceClass/SubClass/Protocol = 0x00/0x00/0x00`
(class defined per-interface), VID `0x0483` (ST), a project PID,
product string `"Tachyon MIDI"`. The class lives in a new
`USB_DEVICE/App/usbd_midi.c` + `.h` implementing `USBD_ClassTypeDef`
(`Init`/`DeInit`/`Setup`/`DataIn`/`DataOut`/`GetCfgDesc`), registered in
place of `USBD_CDC` when the flag is off.

---

## 5. MIDI parsing → voice routing

USB-MIDI delivers **32-bit USB-MIDI Event Packets** on the bulk-OUT
endpoint — each packet is 4 bytes, and a single bulk transfer may carry
several:

```
byte 0:  [ Cable Number (4b) | Code Index Number (4b) ]
byte 1:  MIDI status   (e.g. 0x90 = Note On ch 1)
byte 2:  MIDI data 1   (note number)
byte 3:  MIDI data 2   (velocity)
```

The OUT callback (in `usbd_midi.c`) walks the buffer in 4-byte strides
and dispatches by **Code Index Number** (low nibble of byte 0):

| CIN | Meaning | Action |
|---|---|---|
| `0x9` | Note On | `vel==0` → note-off, else **note-on** |
| `0x8` | Note Off | **note-off** |
| `0xB` | Control Change | (future: sustain, mod) |
| `0xE` | Pitch Bend | (future) |
| other | — | ignored |

```c
for (; len >= 4; p += 4, len -= 4) {
    uint8_t cin = p[0] & 0x0F;
    uint8_t note = p[2], vel = p[3];
    if      (cin == 0x9 && vel) midi_evt_push(MIDI_NOTE_ON,  note, vel);
    else if (cin == 0x9)        midi_evt_push(MIDI_NOTE_OFF, note, 0);
    else if (cin == 0x8)        midi_evt_push(MIDI_NOTE_OFF, note, 0);
}
```

**Threading.** The OUT callback runs in the **OTG IRQ**. Rather than call
the oscillator directly from that context (it takes a short critical
section that also guards the audio render IRQ), parsed events are pushed
into a small **lock-free SPSC ring** and drained in `app_tick()` on the
main loop:

```c
/* app.c, in app_tick() before render */
midi_evt_t e;
while (midi_evt_pop(&e)) {
    if (e.kind == MIDI_NOTE_ON)  app_midi_note_on(e.note, e.vel);
    else                         app_midi_note_off(e.note);
}
```

**The app seam** (declared in `app.h`, called only from the drain loop):
```c
void app_midi_note_on(uint8_t note, uint8_t vel);
void app_midi_note_off(uint8_t note);
```
Both are **gated**: they act only while `s_mode_active && s_src ==
SRC_MIDI`. Mapping:
- `app_midi_note_on(n,v)` → `wt_osc_note_on(n, midi_freq(n), v)` (the
  voice pool reuses the note's own voice on a re-strike, else allocates
  a free voice, else the quietest releasing one, else steals the oldest).
- `app_midi_note_off(n)`  → `wt_osc_note_off(n)` (starts the voice's
  envelope release; with the filter off, an immediate cut).

**Velocity** drives one selectable destination (the Filter Cfg `VelMode`
row, filters.md §3.5): voice level (default), the envelope's A/D transient,
the whole contour, the filter sweep depth, or the attack time.

Outside the mode (or before a mode is picked), events are still drained
and discarded, so stale notes never leak when you switch into USB MIDI.

---

## 6. App / menu integration

The mode matrix (`harmony-engine.md` §2) carries a USB-MIDI source on
the **Direct** engine, polyphonic:

| Source \ Engine | **Direct** | **Arp** |
|---|---|---|
| **Key wheel** | (freebie) | **Key Arp** |
| **Chord wheel** | — | **Chord Arp** |
| **USB MIDI** | **Midi Synth — poly, play-as-received** | — |

Target `app.c` / `app.h` structure:

- `pitch_src_t` includes `SRC_MIDI`.
- `AppScreen` / `k_mode_items[]` carry `APP_SCREEN_USB_MIDI` /
  `"USB MIDI"`. Modes stay contiguous so the menu-index → screen mapping
  is `APP_SCREEN_FIRST_MODE + selected`.
- `engine_tick()`: `if (s_src == SRC_MIDI) return;` — notes are
  event-driven from the drain loop, not polled from a root.
- Entering the mode calls `set_mode(SRC_MIDI, ENG_DIRECT)` (arp disabled,
  `wt_osc_all_off()` for a clean start).
- `render_usb_midi()` screen: title, USB connect state (enumerated /
  not), and a live count of sounding voices (or the last note name).

The USB connect state for the screen comes from a flag the class sets in
its `Init`/`DeInit` callbacks (`usbd_midi` exposes `usb_midi_connected()`).

---

## 7. Phased build plan

1. **App/menu refactor** — drop CV VCO/CV Arp, add the `USB MIDI` mode,
   `SRC_MIDI`, the `app_midi_note_on/off` seam, the SPSC event ring, and
   the `render_usb_midi()` screen. Compiles and is UI-testable with **no
   USB code yet** (ring simply stays empty).
2. **Flag plumbing** — CMake `option`, `flash.ps1 -UsbSerialDebug`, and
   the conditional `_write` → SWO/ITM retarget. After this the default
   build still enumerates CDC (until step 3) but `printf` is on SWO.
3. **MIDI device class** — `usbd_midi.c/.h` (descriptors §4 + the
   bulk-OUT parser §5 feeding the ring), registered under the flag in
   `MX_USB_DEVICE_Init`. Default build now enumerates as `Tachyon MIDI`.

Each step builds green; the feature is end-to-end after step 3.

---

## 8. Future / out of scope

- **CC / pitch-bend** (sustain pedal = CC64; pitch bend = CIN `0xE`).
- **MIDI channel filter** (play only a selected channel; today: omni).
- **MIDI clock in** (CIN `0xF`, 0xF8) driving the arp as an external
  clock source, unifying with `clock-input.md`.
- **TRS/DIN MIDI-in** (UART + optocoupler) as a standalone transport
  feeding the same `app_midi_note_on/off` seam — no PC required.
- **Device → host MIDI** (the declared EP1-IN): echo played notes / arp
  steps back to the DAW.

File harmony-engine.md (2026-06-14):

# Harmony Engine — note generation, modes, and progression sequencer

This document specifies how the Tachyon turns a **harmonic source** into the
**wavetable audio voice** and the **CV/gate outputs**. It replaces the ad-hoc
"CV VCO vs Arp" peer-screens (which let two note sources fight over the
oscillator) with one layered pipeline.

Source references / modules this builds on:
- `Core/IO/wt_osc.c` — single-cycle wavetable oscillator (the audio voice)
- `Core/Music/arp.c` — arpeggiator (step generator)
- `Core/UI/circle_of_fifths.c` — the key wheel rendering + geometry
- `Core/IO/cv_out.c`, `gate-output.md` — `CV-OUT-A`, `GATE-A/B` (1 V/oct + gates)
- `Core/IO/clock_in.c`, `clock-input.md` — external clock / internal tempo
- `Core/IO/analog_in.c`, `user-interface.md` §3 — CV-IN-A/B, panel pot, encoder

---

## 1. Concept

Everything is one pipeline:

```
   ┌──────────────────────┐     ┌───────────────┐     ┌────────────────────┐
   │   HARMONIC SOURCE    │     │    ENGINE     │     │      OUTPUTS       │
   │  (produces the live  │ ──▶ │ (renders the  │ ──▶ │  audio wavetable   │
   │  root / key / chord) │     │  harmony)     │     │  CV-OUT + gates    │
   └──────────────────────┘     └───────────────┘     └────────────────────┘
        CV-IN                       Direct                 1 V/oct CV
        Key wheel  (+ seq)          Arp                    gate per step
        Chord wheel(+ seq)          Chord (poly, future)
```

- Exactly **one** harmonic source is active at a time (this is what makes the
  modes mutually exclusive — the old bug was the arp running *globally* and
  colliding with the CV VCO).
- The **engine** decides how the current harmony becomes sound and CV.
- **Mode = (source × engine)** and is **persistent**: a selected mode keeps
  running while you visit config screens (Audio Cfg, Arp Cfg), like an
  instrument — it is not bound to whichever screen is on the OLED.

---

## 2. Mode matrix (source × engine)

| Source \ Engine | **Direct** | **Arp** | **Chord** (future) |
|---|---|---|---|
| **CV-IN** | **#1** CV VCO — note @ CV pitch, note passed to CV-OUT | **#2** CV root → arp → audio + CV-OUT | — |
| **Key wheel** | "play the wheel note" (freebie) | **#3** wheel → arp → audio + CV-OUT | — |
| **Chord wheel** | — | (arp the chord's notes) | **#4** chord on audio, arp on CV-OUT |

The four numbered cells are the user's four intended uses. `Key·Direct` falls
out for free; the empty cells are not required initially.

**CV-OUT / gate rule:**
- **Direct** → emit the (quantized) root on CV-OUT, gate on note change.
- **Arp** → emit each arp step on CV-OUT + gate per step (today's `arp_step_cb`).
- **Chord** → audio plays the chord (poly), arp drives CV-OUT + gate.

---

## 3. Harmonic sources

### 3.1 CV-IN
- Read `CV-IN-A` or `CV-IN-B` (short-press toggles; see CV VCO screen), 1 V/oct.
- **Quantize to nearest semitone** (chromatic — *not* scale-aware; the key/scale
  is a wheel concept and must not leak into CV mode). Hysteresis to avoid
  flutter at step boundaries. 0 V = C3.
- Produces a live **root note**. In `Direct` it is the played note; in `Arp` it
  is the arp's root.

### 3.2 Key wheel
- Circle-of-fifths selection (existing `circle_of_fifths.c`), with a
  **major / minor** option per key.
- Either a **single key**, or a **key sequence** (see §5): an ordered list of
  steps `{key, bars}` — e.g. `Am·2  Em·2  Bm·2` — advanced by the clock.
- Produces the current **key** (root + major/minor). The engine arpeggiates /
  plays the key's chord (default triad of the key root).

### 3.3 Chord wheel  *(alternative to the key wheel)*
- You first pick a key (root + major/minor) on the key wheel; the chord wheel
  then presents that key's **seven diatonic triads** (§4). Turning the wheel
  selects among them.
- Either a **single chord**, or a **chord sequence** (§5): steps `{chord, bars}`
  — e.g. `C·2  Dm·2  G·2` — advanced by the clock.
- Key-sequence and chord-sequence are **alternatives** — you sequence *keys*, or
  you sequence *chords within one key*, never both stacked.

---

## 4. Music theory (triads only, to start)

Diatonic triads of a key, in scale-degree order:

| Degree | Major key | Natural-minor key |
|---|---|---|
| I / i | major | minor |
| ii / ii°  | minor | dim |
| iii / III | minor | major |
| IV / iv | major | minor |
| V / v | major | minor |
| vi / VI | minor | major |
| vii° / VII| dim | major |

- Major and minor are **relative** (C major ↔ A minor share notes); the
  major/minor option selects which tonic the wheel is centred on.
- **Chord-wheel layout (decision):** the seven diatonic triads of a key occupy
  **seven adjacent positions on the circle of fifths** (IV–I–V–ii–vi–iii–vii°
  for a major key). Reusing the existing wheel geometry and highlighting those
  seven positions is the proposed layout — musically natural and reuses
  `circle_of_fifths.c`. (Alternative: lay them out by scale degree I…vii°.)
- A chord = root note + a triad-interval set `{0, third, fifth}` (third = 3 or 4
  semitones, fifth = 7; dim = `{0,3,6}`). The engine expands the chord into
  notes for the arp or the poly voice.

---

## 5. Progression sequencer (shared by key-seq and chord-seq)

One mechanism, applied at two harmonic levels.

- A **step list**, each step = `{ harmony item, length in bars }`. Harmony item
  is a key (key-seq) or a diatonic chord degree (chord-seq).
- **Time signature** is chosen from **predefined options** (e.g. 4/4, 3/4, 6/8);
  it defines beats per bar.
- **Clock**: reuse the arp clock — internal BPM or external `CLK-IN`
  (`clock-input.md`). A *bar* = (beats/bar) × (clock pulses/beat). When the
  current step's bars elapse, advance to the next step; loop at the end.
- The arp (when the engine is Arp) free-runs *within* the current step's
  harmony; the sequencer only swaps the harmonic context at bar boundaries.

---

## 6. Engines

- **Direct** — one note (the root) on the wavetable voice; emit it on CV-OUT.
- **Arp** — existing `arp.c`: expand the current key/chord into a note set,
  arpeggiate per the arp params (dir, octave, length, tempo, clock). Each step
  drives the wavetable + CV-OUT + a gate. Today's `arp_step_cb` already does
  this; it gets fed a root/note-set from the active source instead of only the
  key-select root.
- **Chord** *(future)* — play all chord notes at once on the audio voice
  (**requires polyphony**; the oscillator is mono today — a real dependency to
  flag), while the arp drives CV-OUT.

---

## 7. Outputs
- **Audio** — wavetable voice (`wt_osc`), selected/loaded via Audio Cfg.
- **CV-OUT-A** — 1 V/oct, the arp step or the passed-through Direct note
  (`cv-output-dac.md` range/scaling).
- **GATE-A/B** — per arp step (Arp), or per note change (Direct).

---

## 8. UI & controls

Controls: rotary encoder (rotate + short/long press, `user-interface.md` §2)
**and** the panel pot (`user-interface.md` §3). The sequencer editor uses
**both** — the encoder to navigate/select steps and turn the wheel, the pot for
a second continuous axis (proposed: step **length in bars**, or scrubbing the
harmony quickly). Exact split to be finalised while prototyping the editor.

- **Consistent model everywhere:** rotate = move selection, push = act / enter
  edit (toggles flip in place; values bracket-edit) — already applied to Menu,
  Audio Cfg, and Arp.
- **Screens (proposed):** Mode select (sets source × engine), Key wheel, Chord
  wheel, Sequence editor, Arp Cfg, Audio Cfg. Selecting a mode is persistent;
  config screens don't stop it.
- **Mutual exclusivity** falls out of "one active source": the arp no longer
  runs globally — it runs only when the engine is Arp.

---

## 9. Phased build plan

- **P1 — routing core + modes 1–3.** Persistent `mode = (source, engine)`;
  source = CV-IN | Key wheel, engine = Direct | Arp. Fix the exclusivity bug
  (arp runs only in Arp engine), add **CV-IN → arp root** (#2), and **Direct →
  CV-OUT passthrough** (#1). No sequencer yet (single key/chord).
- **P2 — harmony selection.** Key wheel major/minor; chord wheel showing the
  key's diatonic triads (single chord, no sequence).
- **P3 — progression sequencer.** The `{item, bars}` step list with predefined
  time signatures, clocked; key-seq and chord-seq (alternatives).
- **P4 — chord engine (#4) + polyphony.** Poly wavetable voice for chords; arp
  on CV-OUT. (Biggest unknown — depends on a poly oscillator.)

---

## 10. Open questions / to finalise

1. **Chord-wheel layout** — circle-of-fifths adjacency (proposed) vs scale-degree order.
2. **Pot vs encoder split** in the sequence editor (which axis is which).
3. **Bar definition** in clock pulses — exact mapping of beats↔arp steps↔CLK-IN.
4. **Sequence limits** — max steps, max bars/step, edit/insert/delete/reorder UX.
5. **Polyphony** for the Chord engine — voice count, mixing/headroom on the
   mono PCM5102A path (the oscillator and `audio.c` render are mono today).
6. **CV-OUT range/tuning** for very low/high arp notes (clamp to the DAC range).
7. **Default / power-on mode** and whether the last mode is persisted.

---

## 11. Known issues

- **CV-IN flutters between C3 and B2 when the jack is unplugged.** Unplugged,
  the switched jack normals the input to ~0 V, which *should* quantize to a
  steady C3 (midi 48). But the CV-IN is uncalibrated and `cv-input.md` notes a
  zero-offset of ~50 mV referred to the input ≈ **0.6 semitone** — enough to sit
  the idle reading on the **B/C step boundary (midi 47.5)**, where ADC noise
  tips it across. The quantizer's 0.6-semitone hysteresis isn't enough at the
  boundary, and the software average was removed (P1/CV-VCO) to kill the
  glissando, so nothing damps it. **Fix directions:** calibrate the per-channel
  CV-IN zero-offset (store the constant per `cv-input.md`/`calibration.md`) so
  0 V reads exactly midi 48; and/or widen the deadband / add a slow idle filter
  that only engages when the input is near a step centre. Low priority — only
  affects an *unpatched* CV input.

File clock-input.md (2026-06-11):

# Clock Input -- External Clock Jack → STM32F405 Timer Input Capture

This document is the schematic-side wiring spec for the external clock
input on the Tachyon board:

- **J_CLK** — 3.5 mm switched mono jack (PJ398SM or equivalent)
- **PA2** — STM32F405 GPIO / TIM2_CH3 input capture
- **Internal fallback clock** — firmware-generated BPM clock when
  nothing is patched

The input accepts standard Eurorack +5 V clock/trigger signals at any
PPQN from 1 to 24 (configurable in firmware) and a BPM range of
40–240 BPM.

Source references:
- `datasheets/STM32F405RG.md` — timer input capture, 5V-tolerant pins
- `hardware-design-plan.md` — available GPIO, timer peripherals
- `power-supply.md` — `+3V3` rail definitions
- `cv-input.md` — BAT54S clamping strategy (reused here)

---

## 1. Configuration summary

| Decision | Value | Rationale |
|---|---|---|
| Number of inputs | 1 | Single clock/trigger input |
| Nominal input | +5 V trigger/gate, 0 V low | Standard Eurorack clock level |
| Absolute max input | ±12 V (clamped) | BAT54S clamp + series R protects the GPIO; stage is not damaged |
| BPM range | 40–240 BPM | Covers typical musical tempo range |
| PPQN range | 1–24 (firmware-configurable) | At 240 BPM / 24 PPQN the max edge rate is 96 Hz — trivial for input capture |
| Detection method | Timer input capture (TIM2_CH3) | Hardware timestamping of rising edges; jitter-free period measurement at 32-bit resolution |
| Internal fallback | TIM-based software clock | When no external edges are detected within a timeout, firmware generates its own BPM clock |
| Jack normalization | Switched jack tip → GND when unplugged | Unpatched input is held LOW; no spurious edges, firmware sees silence and uses internal clock |
| Input threshold | STM32 Schmitt-trigger GPIO input | VIH ≈ 2.0 V on 5V-tolerant (FT) pin; clean switching on +5 V triggers |

---

## 2. Topology

The input stage is deliberately minimal — a series resistor, a small
filter cap, and a Schottky clamp — because the STM32F405's 5V-tolerant
GPIO pins already have built-in Schmitt-trigger inputs suitable for
digital clock signals.

```
                        R17 1 kΩ
JACK_TIP (U19) ──/\/\/\──┬──────────────────────► PA2 (TIM2_CH3)
                          │
                          ├── C38 2.2 nF ── GND
                          │
                          └── D3 BAT54SLT1G ── GND / +3V3
```

### Signal path

1. **Jack tip** receives the external clock signal (0/+5 V typical)
2. **R17 (1 kΩ)** limits fault current into the clamp diodes and
   GPIO under over-voltage conditions
3. **C38 (2.2 nF)** with R17 forms a low-pass filter at
   fc ≈ 72 kHz — passes clock edges cleanly (fastest edge rate at
   240 BPM / 24 PPQN is 96 Hz) while rejecting RF and switcher noise
4. **D3 (BAT54SLT1G)** clamps the filtered node to the 0–3.3 V
   range (same strategy as `cv-input.md` §4.2)
5. **PA2** reads the digital level via the internal Schmitt trigger;
   TIM2_CH3 captures the rising-edge timestamp in hardware

### Jack switch behaviour

The PJ398SM switched jack ties the tip to GND when no plug is
inserted. This holds PA2 LOW continuously — no edges, no interrupts.
Firmware interprets the absence of edges (timeout > 1.5 s, i.e.
below 40 BPM at 1 PPQN) as "no external clock" and runs the internal
BPM generator instead.

When a plug is inserted, the switch opens, and the tip receives
whatever the upstream module is sending. The first valid rising edge
causes firmware to lock onto the external clock and disable the
internal generator. If edges stop arriving (cable pulled, upstream
module stopped), the timeout fires and firmware reverts to internal
clock seamlessly.

---

## 3. Internal clock

When no external clock is detected, firmware runs a timer-based
internal clock:

| Parameter | Value | Notes |
|---|---|---|
| BPM range | 40–240 | Set via encoder / menu |
| Resolution | Sub-ms period accuracy | TIM2 at 84 MHz gives ~12 ns tick; period jitter is negligible |
| PPQN | 1–24, user-configurable | Internal clock generates edges at `60 / (BPM × PPQN)` second intervals |
| Output | Software event (same ISR path as external capture) | Downstream firmware sees identical tick events regardless of source |

The internal clock uses a separate TIM channel (or a second timer) in
output-compare mode to generate periodic interrupts at the configured
BPM and PPQN. The firmware clock API abstracts the source: consumers
receive a tick callback and a `clock_source` flag (internal/external)
but do not need to handle the two cases differently.

### External-to-internal handoff

When the external clock is active, firmware measures the inter-edge
period via TIM2_CH3 input capture. If edges stop (timeout), the
internal clock picks up at the **last measured tempo** so the sequence
continues without an abrupt tempo jump. The user can then adjust BPM
manually via the encoder.

### PPQN detection / configuration

PPQN is not auto-detected by default — the user sets it in the menu
(**default: 4 PPQN**). Firmware divides or multiplies incoming edges as
needed:

| Setting | Meaning |
|---|---|
| 1 PPQN | One clock edge = one step (quarter note) |
| 2 PPQN | Two edges per step — firmware counts every 2nd edge |
| **4 PPQN** | **Four edges per step (16th-note "step clock") — Doepfer analog default (MCV 24 / MSY2) and the common Eurorack default; the recommended default here** |
| 24 PPQN | Twenty-four edges per step (MIDI clock rate / Roland DIN sync) |

**BPM conversion:** `BPM = f_clk × 60 / PPQN` (f_clk in Hz). The earlier
default of 1 PPQN reported 4× the true tempo against a standard Doepfer
4-PPQN clock — e.g. a 120 BPM Doepfer clock emits 8 Hz, which at 1 PPQN
reads "480 BPM". Defaulting to 4 PPQN makes the displayed tempo correct
for typical Eurorack clocks. (Bench-confirmed 2026-06-10; the `firmware-test`
harness hardcodes `CLK_PPQN = 4` for its `clk`/OLED readout.)

If auto-detection is desired in a future revision, firmware can
measure the edge rate against a known BPM range and infer PPQN — but
this is a firmware feature, not a hardware concern.

---

## 4. Protection

### 4.1 Over-voltage (BAT54S clamp)

Same strategy as `cv-input.md` §4.2. R17 (1 kΩ) limits current
into the BAT54SLT1G clamp diodes at the GPIO node:

| Fault scenario | Voltage at jack | Current through R17 |
|---|---|---|
| Normal +5 V clock | +5 V | ~1.7 mA (5 V − 3.3 V across 1 kΩ) |
| Patched to +12 V | +12 V | ~8.7 mA into upper diode |
| Patched to −12 V | −12 V | ~12 mA into lower diode |

All currents are well within BAT54SLT1G ratings (200 mA pulse). The GPIO
pin never sees more than ~3.6 V or less than ~−0.3 V (diode forward
drop).

### 4.2 No TVS needed

The 1 kΩ series resistor limits DC fault current to safe levels and
the BAT54SLT1G diodes absorb transients. No TVS is required — same
reasoning as `cv-input.md` §4.3.

---

## 5. STM32F405 pin allocation

| Signal | STM32 pin | Peripheral / AF | Notes |
|---|---|---|---|
| `CLK-IN` | **PA2** | TIM2_CH3 (AF1) / TIM5_CH3 (AF2) / TIM9_CH1 (AF3) | 5V-tolerant (FT) pin; input capture for period measurement |

PA2 is **free** per the current `hardware-design-plan.md` pin
allocation. It is not claimed by USB, SWD, I2S3, SPI2, the encoder,
OLED, DAC CS, or the CV inputs (PA0/PA1).

### Why PA2 specifically

- Maps to **TIM2_CH3** — TIM2 is a 32-bit timer clocked at 84 MHz
  (APB1 × 2), giving ~12 ns resolution and a 51-second overflow
  period. At 40 BPM / 1 PPQN the inter-edge period is 1.5 s; at
  240 BPM / 24 PPQN it is ~10.4 ms. Both fit comfortably in 32 bits
  with no overflow handling needed for single-period measurement.
- Also available on TIM5_CH3 (another 32-bit timer) and TIM9_CH1
  (16-bit), giving flexibility if TIM2 is needed elsewhere.
- Adjacent to PA0/PA1 (CV inputs) — clean routing in Zone A of the
  PCB.
- Leaves PA3 and higher Port A pins free for future expansion (reset
  input, gate outputs, etc.).

### GPIO configuration

| Setting | Value | Rationale |
|---|---|---|
| Mode | Alternate function (TIM2_CH3, AF1) | Hardware input capture |
| Pull | Pull-down | Ensures pin reads LOW when jack is unplugged (belt-and-suspenders with the jack switch to GND) |
| Speed | Low (2 MHz) | Input pin; speed setting is irrelevant but low minimises EMI |
| Input capture edge | Rising edge | Captures the leading edge of each clock pulse |
| Input capture prescaler | /1 (every edge) | Firmware handles PPQN division in software |
| Input capture filter | 4 samples at fDTS/2 | Minimal hardware debounce; rejects sub-microsecond glitches without adding latency to real edges |

---

## 6. Jack wiring

Use a **switched** mono 3.5 mm jack (PJ398SM or equivalent):

| Jack pin | Net |
|---|---|
| Tip | `CLK_IN_TIP` — goes to R_clk |
| Tip switch (normalled) | **GND** — unplugged = tip held LOW |
| Sleeve | GND |

When nothing is plugged in, the tip switch ties the tip to GND. PA2
reads a steady LOW, no input capture interrupts fire, and firmware
runs the internal clock.

Inserting a plug breaks the normal and routes the external clock
signal to the conditioning network. The first rising edge triggers
input capture and firmware locks to the external source.

---

## 7. Component values

| Ref | Value | Package | MPN / LCSC | Notes |
|---|---|---|---|---|
| R17 | 1.0 kΩ 1 % | 0805 | Existing BOM 1 k line | Series current limiter; part of RC filter |
| C38 | 2.2 nF C0G/NP0 | 0805 | LCSC TODO | Filter cap; C0G for stable capacitance. fc ≈ 72 kHz with R17 |
| D3 | BAT54SLT1G | SOT-23 | BAT54SLT1G / LCSC TODO | Dual Schottky (common anode); clamps to +3V3 and GND |
| U19 | PJ398SM switched 3.5 mm jack | — | PJ398SM / LCSC TODO | Same jack type as J_CV1/J_CV2 |

All passives except C38 are already in the BOM.

---

## 8. Firmware notes

### Clock API sketch

```
typedef struct {
    uint32_t period_ticks;     // TIM2 ticks between last two edges
    uint32_t bpm_x100;        // derived BPM × 100 for 0.01 BPM resolution
    uint8_t  ppqn;            // user-configured PPQN (1–24)
    bool     external;        // true = external clock active
} clock_state_t;
```

- **Input capture ISR:** On each TIM2_CH3 capture event, compute
  `period = CCR_now − CCR_prev`. Convert to BPM:
  `bpm = 60 × f_timer / (period × ppqn)`. Apply a simple moving
  average (4–8 samples) to smooth jitter from upstream analog clocks.
- **Timeout:** If no capture event within `max_period` ticks
  (corresponding to 40 BPM at the configured PPQN), set
  `external = false` and start the internal clock at the last known
  BPM.
- **Internal clock:** Output-compare interrupt on a TIM channel,
  period set from the BPM/PPQN menu setting. Calls the same tick
  handler as the external capture path.
- **Swing / shuffle:** Can be applied in firmware by delaying
  alternate ticks — this is independent of the clock source and does
  not affect the hardware design.

### Tempo display

The measured or set BPM should be shown on the OLED status bar. When
external clock is active, show the measured BPM and a plug icon (or
"EXT" label). When internal, show the set BPM and "INT".

---

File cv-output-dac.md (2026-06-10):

# CV Output DAC -- DAC8552 (U6) + OPA1642 (U7) + REF5025 (U2) Wiring Spec

This document is the schematic-side wiring spec for the precision CV output
chain on the Tachyon board:

- **U6 — DAC8552IDGKR** — 16-bit dual-channel SPI DAC (raw 0–2.5 V output)
- **U2 — REF5025IDR** — 2.5 V precision voltage reference driving DAC8552 VREF
- **U7 — OPA1642AIDR** — dual JFET op-amp, ×4 non-inverting gain stage to 0–10 V

The symbols are already placed; this file enumerates every net, decoupling
component, feedback resistor, and MCU pin assignment needed to wire the
pitch-critical CV path in EasyEDA Pro.

Source references:
- `datasheets/DAC8552.md` — pinout, SPI protocol, decoupling rules
- `datasheets/REF5025.md` — pinout, noise-reduction pin, decoupling
- `datasheets/OPA1642.md` — pinout, rail-to-rail headroom, capacitive-load notes
- `hardware-design-plan.md` §"DAC 16-bit Precision DAC" and §"Op-Amp Output Stage — Mandatory"
- `power-supply.md` — rail definitions (`+3V3_PREC`, `+5V`, `±12V`), LDOs, current budget
- `ref-dac-amp.png` — reference schematic (feedback topology, resistor values)

---

## 1. Configuration summary

| Decision | Value | Rationale |
|---|---|---|
| DAC resolution | 16-bit | ~0.013 cents per step at 1 V/oct — full calibration headroom |
| DAC channels | 2 (DAC A, DAC B) | One per CV output; no spare channels for accent/mod |
| DAC VREF | 2.500 V from REF5025 (pin 6); net named `VREF` | Sets DAC full-scale to 2.500 V (the 2.5 V precision reference net is `VREF` — not to be confused with the STM32 ADC VREF+, which is the `+3V3` rail) |
| DAC SPI mode | Mode 1 (CPOL = 0, CPHA = 1) | Clocks in on falling SCLK edge |
| SPI bus | SPI2 (dedicated — OLED is on separate SPI1) | No bus contention or SPI mode conflict |
| Reference | REF5025IDR, 2.5 V, 3 ppm/°C | Drives DAC8552 VREF at 2.500 V |
| Op-amp | OPA1642AIDR (dual JFET, rail-to-rail) | 5.1 nV/√Hz noise, 1 mV typ Vos, ±11.8 V swing on ±12 V |
| Topology | Non-inverting, G = ×4 | Scales 0–2.500 V DAC to 0–10.000 V CV |
| Full-scale CV output | 0 V to +10 V unipolar | 10 octaves of 1 V/oct |
| Output protection | 1 kΩ series resistor per jack | Short-circuit limit + stability + defined Zout |

---

## 2. STM32F405 pin allocation

SPI2 is dedicated to the DAC8552 — the SSD1327 OLED runs on its own SPI1 bus
(see `user-interface.md` §1). This eliminates any bus contention between
display refreshes and timing-critical DAC updates.

| DAC8552 pin | Net name | STM32 pin | Peripheral / AF |
|---|---|---|---|
| 5 SYNC (~CS) | `DAC-SPI-CS` | **PB1** | GPIO output, push-pull, idle HIGH |
| 6 SCLK | `DAC-SPI-SCLK` | **PB13** | SPI2_SCK (AF5) |
| 7 DIN | `DAC-SPI-MOSI` | **PB15** | SPI2_MOSI (AF5) |

Notes:
- **`DAC-SPI-CS`** must idle HIGH. The DAC8552 clocks DIN on the falling edge
  of SCLK only while SYNC is LOW, and latches the 24-bit frame on the 24th
  falling edge; a premature rising edge on SYNC aborts the transfer
  (`DAC8552.md:46,72`). Firmware drives CS LOW for exactly 24 SCLK cycles
  per write.
- **SPI mode 1 (CPOL = 0, CPHA = 1).** The device also accepts mode 2
  (`DAC8552.md:71`), but pick mode 1 in the HAL config and do not change it.
- **No bus sharing.** The OLED has been moved to SPI1 (PA5/PA7) so SPI2 is
  now dedicated to the DAC8552. SPI2 remains permanently in Mode 1 — no
  CPHA switching needed. See `user-interface.md` §1.2 for rationale.

The REF5025 and OPA1642 consume **no MCU pins** — both are purely analog.

---

## 3. Pin-by-pin connection table

### U6 — DAC8552IDGKR (VSSOP-8)

| Pin | Name | Connection |
|---|---|---|
| 1 | VDD | `+3V3_PREC` via C18 (1 µF) + C19 (100 nF) decoupling |
| 2 | VREF | `VREF` from U2 (REF5025) pin 6, decoupled with C20 (1 µF) + C21 (100 nF) |
| 3 | VOUTB | To U7.1 +IN A (pin 3) — drives **CV-OUT-A** jack (channels cross-wired — see note below) |
| 4 | VOUTA | To U7.2 +IN B (pin 5) — drives **CV-OUT-B** jack (channels cross-wired — see note below) |
| 5 | SYNC | `DAC-SPI-CS` → STM32 PB1 |
| 6 | SCLK | `DAC-SPI-SCLK` → STM32 PB13 (shared SPI2 SCK) |
| 7 | DIN | `DAC-SPI-MOSI` → STM32 PB15 (shared SPI2 MOSI) |
| 8 | GND | GND (Layer 2 plane) |

> **Channel swap (PCB-placement driven):** DAC8552 `VOUTA` (pin 4) feeds the
> CV-OUT-**B** jack via U7.2, and `VOUTB` (pin 3) feeds the CV-OUT-**A** jack
> via U7.1. Firmware must therefore drive **DAC channel B** to reach the physical
> CV-OUT-A jack, and **DAC channel A** for CV-OUT-B. Channel select is the
> **buffer-select bit DB18** (0 = DAC A, 1 = DAC B), *not* DB21 — use the canonical
> control bytes **0x24 = write+update DAC B** (CV-OUT-A jack) and **0x10 =
> write+update DAC A** (CV-OUT-B jack). See `datasheets/DAC8552.md` §Application
> Notes. The select lives in the DAC driver; the `cv_cal[]` table in
> `calibration.md` remains indexed by physical jack (0 = CV-OUT-A,
> 1 = CV-OUT-B) so calibration and user-facing menus are unaffected.
> **(Corrected 2026-06-10 — was wrongly written as "set DB[21]=1"; that bit is
> the load-B control, not the channel select, and the bug left VOUTB dead.)**

### U2 — REF5025IDR (SOIC-8)

| Pin | Name | Connection |
|---|---|---|
| 1 | DNC | Do not connect (leave floating) |
| 2 | VIN | `+3V3_PREC` via C15 decoupling |
| 3 | TEMP | No connect (leave floating) |
| 4 | GND | GND (Layer 2 plane) |
| 5 | TRIM/NR | Noise-reduction cap C17 (100 nF) to GND |
| 6 | VOUT | `VREF` → U6 DAC8552 pin 2 via C16 decoupling |
| 7 | NC | No connect |
| 8 | DNC | Do not connect (leave floating) |

### U7 — OPA1642AIDR (SOIC-8, dual)

U7.1 (OPA1642 unit A) — drives **CV-OUT-A** jack, fed from DAC8552 **VOUTB**:

| Pin | Name | Connection |
|---|---|---|
| 1 | OUT A | CV_A net → R13 1 kΩ → CV jack A tip; also → R3 (30 kΩ) feedback tap |
| 2 | -IN A | Junction of R3 (30 kΩ to OUT A) and R4 (10 kΩ to GND) |
| 3 | +IN A | U6 pin 3 (VOUTB) — DAC channel B raw output |
| 4 | V- | `-12V` (Eurorack) via C23 (100 nF) |

U7.2 (OPA1642 unit B) — drives **CV-OUT-B** jack, fed from DAC8552 **VOUTA**:

| Pin | Name | Connection |
|---|---|---|
| 5 | +IN B | U6 pin 4 (VOUTA) — DAC channel A raw output |
| 6 | -IN B | Junction of R5 (30 kΩ to OUT B) and R6 (10 kΩ to GND) |
| 7 | OUT B | CV_B net → R14 1 kΩ → CV jack B tip; also → R5 (30 kΩ) feedback tap |
| 8 | V+ | `+12V` (Eurorack) via C22 (100 nF) |

All "GND" connections above land on the single continuous Layer 2
ground plane defined in `pcb-design.md` §3. There is no separate AGND /
DGND net; the DAC8552 GND (pin 8) and REF5025 GND (pin 4) each get
their own via to Layer 2 placed directly adjacent to the pin.

---

## 4. Power rails

Rail definitions, LDO selection, current budget, and sequencing live in
**`power-supply.md`**. This document only specifies which rail each pin
lands on:

| Part | Pin | Rail |
|---|---|---|
| U6 DAC8552 | VDD (pin 1) | `+3V3_PREC` |
| U2 REF5025 | VIN (pin 2) | `+3V3_PREC` (0.6 V over the REF5025 VS_min = 2.7 V hard floor per datasheet §6.5; moved onto the LDO rail so U2 can sit next to U6 and keep the `VREF` trace < 20 mm per §6) |
| U7 OPA1642 | V+ (pin 8) / V− (pin 4) | `+12V` / `−12V` (Eurorack) |

---

## 4a. Decoupling and passives BOM

Place every cap **as close to its pin as possible**, on the same side as the
part where practical, with short fat traces to GND.

### U6 — DAC8552 decoupling (per `DAC8552.md:74`)

| Ref | Value | Package | Net | Notes |
|---|---|---|---|---|
| C18 | 1 µF | 0805 X7R | VDD (pin 1) – GND | Bulk on `+3V3_PREC` |
| C19 | 100 nF | 0805 | VDD (pin 1) – GND | HF bypass, closest to pin |
| C20 | 1 µF | 0805 X7R | VREF (pin 2) – GND | Bulk on `VREF`; low-impedance source is mandatory (`DAC8552.md:75`) |
| C21 | 100 nF | 0805 | VREF (pin 2) – GND | HF bypass, closest to pin |
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

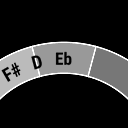
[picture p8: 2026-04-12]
graphical-ui-generator/note_sprites_preview.png

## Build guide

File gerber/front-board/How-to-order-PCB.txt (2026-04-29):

How to Order PCB

Please refer to:
https://prodocs.easyeda.com/en/pcb/order-order-pcb/index.html

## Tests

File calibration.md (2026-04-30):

# CV Output Calibration

Procedure for calibrating Tachyon's precision CV outputs
(CV-OUT-A and CV-OUT-B) so that each jack produces accurate 1 V/oct
pitch voltages across the full 0–10 V range.

This is a bring-up-time procedure, run once per assembled board and
stored in flash. Re-run if the board is moved to a dramatically
different temperature environment or if a downstream VCO is replaced
with one of very different input impedance.

Scope: this document covers only the precision CV path:

```
DAC8552 (VREF = REF5025 2.500 V)  →  OPA1642 non-inverting ×4
                                   →  R13/R14 1 kΩ  →  CV-OUT-A / CV-OUT-B jack
```

The audio DAC path (PCM5102A) is not calibrated — see `audio-output-dac.md`.

---

## 1. Why calibration is necessary

The nominal transfer function is:

```
V_jack_ideal = (DAC_code / 65535) × V_REF × Gain
             = (DAC_code / 65535) × 2.500 × 4
             = (DAC_code / 65535) × 10.000  V
```

In practice the actual jack voltage deviates from this because of a
chain of static linear errors, each contributing to either the
**slope** (V per DAC code) or the **offset** (V at DAC code 0):

| Source | Typical spread | Contribution |
|---|---|---|
| REF5025 initial accuracy | ±0.1% (±2.5 mV at 2.5 V) — I-grade | Slope |
| REF5025 tempco | 8 ppm/°C max = ±80 ppm over 10 °C — I-grade | Slope drift |
| DAC8552 INL | ±12 LSB max over 65536 codes = ±0.018% FS | Mostly slope, tiny curvature |
| DAC8552 DNL | ±1 LSB (guaranteed monotonic) | Below calibration resolution |
| R_f / R_g ratio (0.1% resistors) | √2 × 0.1% = ±0.14% | Slope |
| Feedback-resistor tempco mismatch | ~25 ppm/°C × 10 °C = ±250 ppm | Slope drift |
| R13/R14 / Eurorack Z_in divider (1 kΩ / 100 kΩ) | −0.99%, load-dependent | Slope |
| OPA1642 Vos × Gain | ±3.5 mV × 4 = ±14 mV max | Offset |
| OPA1642 Vos drift | 1.5 µV/°C × 4 × 10 °C = ±60 µV | Offset drift |

Sum of static slope errors: roughly ±1.3% worst case before
calibration. At 1 V/oct that is **~15 cents of pitch error per
octave**, accumulating to a full semitone over the 10-octave range.
Audibly out of tune.

After two-point calibration these all collapse into two per-channel
constants stored in flash. Residual errors are from tempco drift
(negligible over normal operating swings) and DAC nonlinearity (well
below 1 cent and below the quantizer's step size anyway).

---

## 2. What gets calibrated

Two numbers per channel, stored per unit in the last flash page:

```c
typedef struct {
    float slope;     // volts per DAC code, typically ≈ 10.0 / 65535 = 152.6 µV/LSB
    float offset;    // volts at DAC code 0, typically ≈ 0 ± 15 mV
} cv_cal_t;

cv_cal_t cv_cal[2];  // index 0 = channel A, index 1 = channel B
```

To produce a target voltage `V_target`, firmware computes:

```c
uint16_t code = (uint16_t)roundf((V_target - cv_cal[ch].offset) / cv_cal[ch].slope);
if (code > 65535) code = 65535;
dac8552_write(ch, code);
```

Slope and offset are fitted from two measured points via the standard
two-point linear fit:

```
slope  = (V_high_measured − V_low_measured) / (code_high − code_low)
offset = V_low_measured − slope × code_low
```

---

## 3. Equipment required

Pick one of the two measurement paths:

**Path A — digital multimeter (recommended, most accurate)**
- DMM with ≥ 4½ digit resolution on DC volts (a basic Fluke 115,
  Brymen BM235, or even a cheap UT61E is adequate; 5½ or 6½ digit is
  better if available).
- DC accuracy ≤ 0.1% of reading in the 0–20 V range (~10 mV worst case
  at 10 V; well under a semitone at 1 V/oct, leaving headroom for the
  Tachyon itself to be the dominant error).
- Test leads with banana-to-3.5mm-TS adapter, or a bare 3.5 mm TS cable
  cut short with the conductors stripped.

**Path B — reference VCO + chromatic tuner**
- A known-good 1 V/oct VCO with flat tracking (e.g. Mutable Plaits,
  Doepfer A-110-1, Intellijel Dixie II).
- A chromatic tuner accurate to ≥ 1 cent (Peterson StroboStomp, a
  Korg OT-120, or a software tuner like TE Tuner / Cleartune).
- Patch cable between the sequencer output and the VCO 1 V/oct input,
  audio cable from VCO out to the tuner's input.

Path A calibrates the sequencer **as a voltage source** and is
independent of any downstream module — the resulting slope/offset are
universal. Path B calibrates the sequencer **as-patched into one
specific VCO** — the slope absorbs that VCO's particular input
impedance into the R13/R14 divider, giving slightly better accuracy
when used with that VCO but slightly worse accuracy with others.

Recommended: use Path A for the permanent flash-stored calibration,
then spot-verify with Path B against the VCO you'll actually patch
into most often.

---

## 4. Procedure — Path A (DMM)

### 4.1 Setup

1. Power the sequencer from the Eurorack bus (±12 V and +5 V present,
   +3V3_PREC rail up, REF5025 and DAC8552 powered).
2. Connect the DMM across the CV-OUT-A jack: red probe on the tip
   (plug only partially inserted, or use a TS breakout), black probe
   on the sleeve (board GND).
3. **Leave the jack unloaded** — do not patch CV-OUT-A into any
   downstream module during this measurement. An unloaded output
   eliminates the R13/R14 divider so the calibration captures only the
   DAC + op-amp + REF5025 errors. (Why: see §6 below.)
4. Enter calibration mode via the OLED menu: **Menu → Calibration →
   CV Out A**. Firmware disables any sequence playback and holds the
   selected DAC code steady.

### 4.2 Low-point measurement

1. Firmware sets DAC code = **6554** (nominal 1.0000 V — 10% of full
   scale; avoids using code 0, which would make any output offset
   invisible).
2. Wait 2 seconds for the reading to settle (op-amp slews in
   microseconds, but the DMM filter averaging takes ~1 second for a
   stable reading).
3. Record the DMM reading as `V_low_measured` — to 4 decimal places
   if possible.
4. Press the EC11E encoder switch to confirm; firmware stores
   `code_low = 6554` and `V_low_measured`.

### 4.3 High-point measurement

1. Firmware sets DAC code = **58982** (nominal 9.0000 V — 90% of full
   scale; stays well inside OPA1642's rail-to-rail output capability
   even at ±12 V supplies, see `hardware-design-plan.md` § Op-Amp Output
   Stage for the headroom calculation).
2. Wait 2 seconds for settling.
3. Record `V_high_measured`.
4. Press to confirm; firmware stores `code_high = 58982` and
   `V_high_measured`.

### 4.4 Slope and offset computation

Firmware computes:

```c
float slope  = (V_high_measured - V_low_measured) / (58982.0f - 6554.0f);
float offset = V_low_measured - slope * 6554.0f;
cv_cal[0].slope  = slope;
cv_cal[0].offset = offset;
```

Example with typical real-world measurements:

```
V_low_measured  = 0.9972 V
V_high_measured = 8.9854 V

slope  = (8.9854 − 0.9972) / (58982 − 6554)
       = 7.9882 / 52428
       = 152.363 µV / LSB

offset = 0.9972 − 152.363e−6 × 6554
       = 0.9972 − 0.9986
       = −0.00137 V (−1.37 mV)
```

Compare against the ideal: 152.588 µV/LSB and 0 V offset. The
measured slope is 0.15% low (consistent with the R13/R14 divider not
being active because the jack is unloaded, and the feedback-resistor
ratio being slightly under 4) and the offset is within spec.

### 4.5 Save to flash

Firmware writes the new `cv_cal[0]` into the calibration flash page
and displays "CV A calibrated — slope 152.36 µV/LSB, offset −1.4 mV"
for user confirmation.

### 4.6 Repeat for CV-OUT-B

Same procedure with the DMM moved to the CV-OUT-B jack and the menu
advanced to **Menu → Calibration → CV Out B**. The two channels have
independent `slope` and `offset` values because the feedback
resistors R3/R5 and ground-leg R4/R6 have independent tolerances.

---

## 5. Procedure — Path B (reference VCO + tuner)

Use only to spot-verify or when a DMM isn't available.

1. Patch CV-OUT-A → VCO 1 V/oct input. Patch VCO audio out → tuner.
2. In the calibration menu, firmware sets code 6554 (nominal 1.0 V).
3. Note the VCO's current pitch on the tuner (e.g. "A2 +3 cents").
4. Firmware sets code 58982 (nominal 9.0 V).
5. Confirm the pitch is exactly 8 semitones × 12 = 96 semitones higher
   (e.g. "A10 +3 cents" — same cents offset).
6. If the cents offset differs between the two points, the slope is
   wrong. Compute the slope correction from the cents delta:

```
cents_error = cents_at_high - cents_at_low
slope_correction_factor = 1 - (cents_error / (8 × 1200))
new_slope = old_slope × slope_correction_factor
```

7. If the cents offset is the same at both points but non-zero,
   that's the octave offset — adjust `offset` by `(cents_at_low / 1200) × 1 V`.

Path B has no way to measure absolute voltage, only pitch ratios, so
it cannot calibrate the offset independently of the VCO's own offset.
This is why Path A (DMM) is the canonical procedure.

---

## 6. Why the jack is unloaded during Path A calibration

R13 / R14 (1 kΩ each) form a voltage divider with the downstream module's
input impedance. A typical Eurorack 1 V/oct input is 100 kΩ, giving a
−0.99% attenuation at the jack. Different VCOs have different input
impedances (30 kΩ to 1 MΩ is the range in the wild), so calibrating
into one VCO gives a slope that is 0.1–2% wrong for any other VCO.

Calibrating with the jack **unloaded** sidesteps this — the DMM's
input impedance is typically 10 MΩ (or 1 GΩ for an electrometer
DMM), so the divider attenuation is < 0.01% and effectively zero.
The stored slope then represents the op-amp output impedance, not
the op-amp + a particular load.

At runtime, every downstream module gets the same unloaded-calibration
slope, and the ~1% divider error at the jack is treated as part of
each downstream module's own tuning tolerance (which it is, since
different VCOs have different input impedances anyway). In practice
this residual error is well under a semitone and is absorbed into
the VCO's own front-panel tuning knob.

---

## 7. Verification

After calibration, firmware offers a **Menu → Calibration → Verify**
page that cycles through 5 test points and waits for the user to
record the DMM reading at each:

| Point | DAC code | Expected voltage | Measured | Error |
|---|---|---|---|---|
| 1 | 0 | 0.000 V | ___ | ___ |
| 2 | 16384 | 2.500 V | ___ | ___ |
| 3 | 32768 | 5.000 V | ___ | ___ |
| 4 | 49152 | 7.500 V | ___ | ___ |
| 5 | 65535 | 10.000 V | ___ | ___ |

Pass criteria:
- **Absolute error** at each point ≤ ±5 mV (half a cent at 1 V/oct).
- **Linearity error** (residual after subtracting the linear fit from
  point 1 to point 5) ≤ ±2 mV at any intermediate point.

If linearity is out of spec, the likely causes in order of probability:
1. DAC8552 has a bad INL segment (swap chips to confirm).
2. Op-amp is clipping on the high point (lower the high-point code
   from 65535 to 58982 and re-verify the top of range separately).
3. Feedback resistors have drifted or the PCB has a cold joint at R3
   or R5 — reflow U7's feedback network.
4. REF5025 is noisy or oscillating (add/check the NR cap on pin 5 and
   verify the 10 µF bulk on `+3V3_PREC`).

---

## 8. Flash storage format

Calibration constants live in the last 16 KB flash sector (sector 11
on the STM32F405RG) along with user presets. The calibration record
is a 32-byte struct at a fixed offset from the sector base:

```c
#define CAL_MAGIC 0x43564143  // 'CVCA'

typedef struct __attribute__((packed)) {
    uint32_t magic;        // CAL_MAGIC for valid record
    uint32_t version;      // 1
    float    slope_a;      // V per LSB, channel A
    float    offset_a;     // V, channel A
    float    slope_b;      // V per LSB, channel B
    float    offset_b;     // V, channel B
    uint32_t crc32;        // CRC-32 over bytes [0..27]
} cv_cal_flash_t;          // 32 bytes total
```

On boot, firmware reads the record, verifies magic and CRC, and
either loads the stored constants or falls back to the nominal
defaults (`slope = 10.0 / 65535`, `offset = 0`) if the record is
absent or corrupted. The user is notified via the OLED status bar if
default constants are in use.

Re-calibration rewrites only this 32-byte struct using the standard
erase-sector / program-word pattern. Since this is a 16 KB sector,
the other user data in the sector must be preserved via a
read-modify-write cycle with an RAM buffer.

---

## 9. When to re-calibrate

Calibration is stable and does not drift meaningfully under normal
conditions. Re-run only if:

- **First power-on after assembly** (no valid record in flash).
- **Ambient temperature has changed by > 15 °C** from the calibration
  temperature and pitch accuracy is audibly off. Typical Eurorack
  shows open to house temperature and a short soak; if you
  calibrated at 20 °C in winter and play at 35 °C under stage
  lights, recalibrate. Realistically this is ~5 cents of drift and
  most users won't notice.
- **A passive part in the precision chain has been replaced**
  (REF5025, DAC8552, OPA1642, R3–R6). This retunes the slope.
- **The module has sat unpowered for > 1 year** — op-amp Vos can age
  slightly. Verify first, re-cal only if out of spec.

Do not re-calibrate in response to a downstream VCO sounding flat —
that is almost always the VCO's own tuning knob, not the sequencer.

---

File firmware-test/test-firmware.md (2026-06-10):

# Tachyon IO Bring-up Test Plan

Bench-test plan for exercising **every non-power-rail IO pin** on the
assembled Tachyon stack (WeAct STM32F405 core) using instrument MCP servers
driven from this session plus a purpose-built **test firmware** running on
the F405.

## Test boundary — BACKING BOARD ONLY

**Only the backing (MCU + audio) board is under test. The IO board and front
panel are NOT connected.** Every test therefore happens **at the H2 / H3 /
H4 / H9 header pins** on the backing board, and the expected value is the
**backing-board-side** signal — *not* the post-IO-board jack/control value.

This matters because several conditioning stages live on the **IO board**, so
their effect is absent at the header:

| Stage | Lives on | Consequence at the backing-board header |
|---|---|---|
| Gate 2N7002K invert + +5 V level-shift | IO board (`H9.11→R20→Q2`) | Gates leave the MCU as **raw 3.3 V GPIO, non-inverting** — 3.3 V at H9.11/H9.10 is CORRECT, not a fault |
| Pot (U25) | IO board | H9.4 goes ~straight to the MCU ADC — **inject** a voltage at the header to test |
| Encoder (SW1) | IO board | H4.2/4.3/4.5 go ~straight to the MCU — **inject** edges at the header |
| CV-in scaling op-amp (inverting map) | IO board | H9.5/H9.6 reach the MCU ADC through protection only — **inject** 0–3.3 V; ADC code is linear, the inverted transfer function is absent |

Stages that **are** on the backing board and so *are* live at the header:
- **CV-out**: DAC8552 → **OPA1642 (U7)** → H3.6 / H3.7 (full 0–10 V swing).
- **Audio**: PCM5102A → buffer **U16** → H2.2 / H2.3 (~10 Vpp).
- **VREF**: REF5025 (U2/U6) → **H9.2 ≈ 2.500 V DC**.
- **Gates** (raw GPIO), **CLK-IN** (protection → TIM2 capture).

Pin/stage assignments are authoritative in the per-board `.tel` netlists
(`gerber/Netlist_backing-board-schematic_*.tel` and the `io-board` one), not
in the design markdown.

The test firmware in this folder (`firmware-test/`) is a fork of the main
`firmware/` tree. It replaces the application with a **USB-CDC test
console**: a command interpreter that lets the host drive each output and
read back each input, so the instruments and the MCU meet in the middle on
every net.

## Instruments

| Role | Hardware | MCP server | Purpose |
|---|---|---|---|
| Stimulus / digital capture | **Bus Pirate 6** | [`mplogas/buspirate-mcp`](https://github.com/mplogas/buspirate-mcp) | PSU stimulus into analog inputs, logic-analyzer capture of digital buses, SPI/I2C sniff, GPIO toggling |
| Measurement | **Rigol DS1000Z scope** (DS1054Z / DS1104Z etc.) | [`erebusnz/rigol-mcp`](https://github.com/erebusnz/rigol-mcp) | DC + AC measurement at output jacks, waveform capture, edge/pulse timing, frequency |

Key capability split, because it shapes the whole plan:

- **rigol-mcp is scope-only** — it measures, it cannot source a signal.
  No function generator, no DMM, no PSU. Tools we lean on: `measure`
  (VMAX/VMIN/VPP/VRMS/FREQ/PERIOD/PWIDTH/RTIME), `get_waveform`,
  `set_channel`, `set_timebase`, `set_trigger`, `screenshot`, `send_raw`.
- **buspirate-mcp is the only programmable source** — its bench PSU
  (`set_voltage` / `set_power`, **0–5 V positive only**, confirmation-gated)
  is our analog stimulus, and its 75 MHz 8-ch **logic analyzer**
  (`la_prepare`/`la_command`/`la_analyze`/`la_identify`/`la_cleanup`) plus
  `open_spi`/`spi_*` capture and decode the digital buses. GPIO toggling is
  available for injecting edges.

Consequences baked into the procedures below:

- The Bus Pirate PSU **cannot make negative voltage**, and on the backing
  board the CV-in/pot pins go straight to a 3.3 V MCU ADC, so inputs are
  injected over **0 V → 3.3 V** at the header. The bipolar/inverted range is
  an IO-board op-amp and is out of scope here.
- Neither instrument is a clean clock generator, so **CLK-IN is verified by
  loopback** from a Tachyon gate output (see §6), with the BP logic analyzer
  as cross-check.

### Instrument strategy — Bus-Pirate-first (Strategy)

For the backing-board pass the **Bus Pirate is the primary instrument** and
the **Rigol is deferred**. Rationale: everything testable at the headers is
either digital, ≤3.3 V, or a ≤5 V DC level the BP can source/read directly.

- **BP reads a static 0–5 V DC level** via `verify_connection`'s
  `voltage_range_mv` (min≈max for a flat level; it samples ~20 Hz, enough for
  slow gate clocks too). The MCP exposes no generic ADC/GPIO read, so for
  finer pin-ADC reads use the SDK (`bench/bp_probe.py` →
  `status_request()['adc_mv']`).
- **BP sources** analog stimulus with `set_voltage`/`set_power` (0–5 V,
  approval-gated) and **injects edges** by GPIO toggling.
- **Never feed the BP >5 V or anything negative**: the 0–10 V CV-out top
  half, the ~10 Vpp audio, and the ±12 V rails exceed BP limits. Verify CV-out
  only over `dac _ mv 0..5000` (≤5 V at the header), verify audio via the
  **I2S3 logic-analyzer decode** (BCK/LRCK/DIN), and read ±12 V / full audio
  only with the **Rigol + 10× probe** if/when it is reattached.
- The console runs over the F405's own USB-CDC (Windows **COM13**), driven by
  `bench/serial_cli.py`. The BP terminal is **COM14**, its BPIO2 binary
  interface **COM9** (see [[instrument-mcp-servers]]).

### MCP setup checklist

1. Bus Pirate 6 on USB in **BPIO2 binary mode** (`binmode`→`2`→save `y` on
   the COM14 terminal). `list_devices` → `verify_connection`. (Windows
   detection fix + orphan-process gotcha: see [[instrument-mcp-servers]].)
2. Tachyon console enumerated on **COM13**; `serial_cli.py --port COM13
   --send id` returns the build string.
3. **Common ground first, always.** Tie BP **GND** to a Tachyon **GND** (a
   header GND pin — e.g. H9.1/3/7/9/12 — or a board GND test point) before
   any other connection. With the IO board absent there are no jack sleeves.
4. Rigol is **deferred** (BP-first). Only attach it for the >5 V analog
   amplitude checks; then set probes to **10×** and declare the ratio to
   rigol-mcp via `set_channel`.

## Test firmware (USB-CDC console)

The fork keeps all the HAL/peripheral init from `firmware/` (same `.ioc`,
same pin map — see `Core/Inc/main.h`) but swaps the application loop for a
line-based command parser over the USB CDC ACM port. Flash it the working
way: **USB DFU** (BOOT0 high, `dfu-util`), not SWD.

The console exposes one verb per IO function. Sketch of the command set:

| Command | Action | Pins exercised |
|---|---|---|
| `id` | print firmware id + build | — (USB PA11/PA12) |
| `led on/off/blink` | toggle user LED | **PB2** (heartbeat / proof of life) |
| `dac <ch> <code>` | write 16-bit DAC8552 code (raw) | SPI2 PB1/PB13/PB15 → CV-OUT |
| `dac <ch> mv <millivolts>` | write calibrated CV output | CV-OUT-A/B |
| `gate <a\|b> <0\|1>` | static gate level | PA3 / PA6 |
| `gate <a\|b> pulse <ms>` | one-shot timer pulse | PA3 / PA6 |
| `gate <a\|b> clk <bpm> <ppqn>` | free-run gate as clock source | PA3 / PA6 (drives loopback) |
| `adc <a\|b>` | read CV-IN ADC code + volts | PA0 / PA1 |
| `pot` | read USR_POT_1 ADC code | PC0 |
| `clk` | report captured CLK-IN period / BPM | PA2 (TIM2_CH3 capture) |
| `enc` | report count, turn direction, live A/B/SW level + last SW edge | PB6 / PB7 / PB4 |
| `enc reset` | zero the encoder count | PB6 / PB7 |
| `tone <hz>` | play sine over I2S3 | PB3/PB5/PA15 → audio L/R |
| `mute <0\|1>` | drive XSMT | PC6 |
| `oled test` | draw test pattern (also drives SPI1) | PA5/PA7/PB12/PC1/PC2 |
| `sd` | mount card, read/write/verify a test file | PC8–12, PD2; PA8 = CD |
| `stream adc on/off` | continuous ADC dump (for live stimulus sweeps) | PA0/PA1/PC0 |

The console is what makes the instruments useful: for **outputs** the host
commands a known state and the scope measures it; for **inputs** the host
(BP PSU / loopback / a human) applies a stimulus and the console reports
what the MCU saw.

## Test scope — backing-board headers H2 / H3 / H4 / H9

**The OLED (SPI1) is connected and working — it is out of scope.** With the
IO board absent, the goal is to confirm the backing board **correctly drives
or reads each signal at its own header pin**: outputs (gates, CV-out, audio,
VREF) appear at the header at their backing-side level; inputs (CV-in, pot,
encoder, clock) are exercised by **injecting a stimulus at the header pin**
and reading what the MCU saw via the console. The DAC SPI2, I2S3, MUTE,
SDIO, and USB nets are backing-board-internal and validated incidentally
(e.g. a tone proves I2S3 on the way to checking H2).

Each output test is a **drive-and-measure**: the console commands a known
state, the instrument measures the header pin. Each input test is an
**inject-and-read**: the instrument applies a stimulus at the header pin, the
console reports the MCU reading. "Backing pin dead" shows up as the MCU
driving/reading its GPIO but nothing appearing at (or no response to) the
header.

Pinouts below are from `gerber/Netlist_backing-board-schematic_2026-05-04.tel`
(GND pins omitted — tie them to the common ground). **Expect = backing-side
value at the header pin**, with the BP as primary instrument (see Strategy).

### H2 — audio out (4-pin, left edge)
| Pin | Net | Console | Measure at | Expect (backing side) |
|---|---|---|---|---|
| 1, 4 | GND | — | — | common ground |
| 2 | A-OUT-R | `mute 0` + `tone 1000` | H2.2 | ~1 kHz, ~10 Vpp (buffer U16 on backing) — **>BP range; use I2S LA decode or scope** |
| 3 | A-OUT-L | `mute 0` + `tone 1000` | H2.3 | ~1 kHz, ~10 Vpp (via R9/U16) — same |

### H3 — CV out + analog power (8-pin, right edge)
| Pin | Net | Console | Measure at | Expect (backing side) |
|---|---|---|---|---|
| 1 | +12V | — | H3.1 | rail present (power-supply check) — **>BP; scope/DMM** |
| 2 | −12V | — | H3.2 | rail present — **negative; never into BP** |
| 4 | +5V | — | H3.4 | +5 V rail (BP-safe to read) |
| 3,5,8 | GND | — | — | common ground |
| 6 | CV-OUT-A | `dac a mv 0..5000` | H3.6 | 0–5 V, tracks command (DAC8552→OPA1642 U7; full range 0–10 V, **swept to ≤5 V for BP**) |
| 7 | CV-OUT-B | `dac b mv 0..5000` | H3.7 | 0–5 V, tracks command (via R5/U7) |

### H4 — encoder (8-pin, bottom)
| Pin | Net | Console | Stimulus (IO board absent) | Expect |
|---|---|---|---|---|
| 2 | USR-ENC-A | `enc` | **inject** quadrature edges at H4.2 (BP) | count changes |
| 3 | USR-ENC-B | `enc` | **inject** at H4.3, lead/lag vs A | direction sign flips with phase |
| 5 | USR-ENC-SW | `enc` | **pull H4.5 to GND** (BP) | "SHORT/LONG press" prints |
| 7 | +3V3 | — | H4.7 | +3V3 rail present (BP-safe) |
| 1,4,6,8 | GND | — | — | common ground |

### H9 — pot / CV in / clock / gates / Vref (12-pin, bottom)
| Pin | Net | Console | Stimulus / measure | Expect (backing side) |
|---|---|---|---|---|
| 2 | VREF | — | read H9.2 (BP) | **2.500 V DC** (REF5025 U2/U6 on backing) |
| 4 | USR-POT-1 | `pot` | **inject** 0–3.3 V at H9.4 (BP PSU) | code ~0 → ~4095, linear (U25 pot is IO board) |
| 5 | CV-IN-A | `adc a` | **inject** 0–3.3 V at H9.5 (BP PSU) | code linear ≈ V/3.3×4095 (inverted map is IO-board op-amp, absent) |
| 6 | CV-IN-B | `adc b` | **inject** 0–3.3 V at H9.6 | same |
| 8 | CLK-IN | `clk` | gate→clk header loopback, or BP edges at H9.8 | measured period/BPM |
| 10 | GATE-OUT-B | `gate b 1/0/pulse` | read H9.10 (BP) | **0 / 3.3 V, non-inverting** (raw GPIO) |
| 11 | GATE-OUT-A | `gate a 1/0/pulse` | read H9.11 (BP) | **0 / 3.3 V, non-inverting** (raw GPIO) |
| 1,3,7,9,12 | GND | — | — | common ground |

**Header-to-header loopbacks (one patch cable, no external source):**
GATE-OUT-A (H9.11) → CLK-IN (H9.8) proves the gate-out drive and the clock
capture together (3.3 V edges are valid logic). CV-OUT-A (H3.6) → CV-IN-A
(H9.5) proves the DAC→buffer→ADC chain — **sweep `dac a mv 0..3300` only**,
so CV-IN stays ≤3.3 V (the input protection clamps above that).

## Pin inventory — non-power-rail IO

The table below is the full MCU-pin reference. The pins that **cross the
headers above** (CV in/out, gates, clock, encoder, pot, audio) are the test
focus; the rest (SPI2/I2S3/SDIO/USB/OLED/MUTE) are backing-board-internal
and already working or incidentally covered.

Power pins (VDD/VDDA/VBAT/VSS and the board power nets `+3V3`, `+3V3_PREC`,
`+3V3_AUDIO`, `+5V`, `±12V`) are **out of scope** — they are not GPIO and
are validated separately in `power-supply.md` bring-up. Everything below is
a signal pin and gets tested. The **Test method** column reflects the
backing-board pass (measure/inject at the header, BP-first).

| STM32 pin | Net / label | Function | Dir | Test method | Instrument |
|---|---|---|---|---|---|
| PA0 | CV_IN_A | ADC1_IN0 | in | inject 0–3.3 V at H9.5 → `adc a` | BP PSU + console |
| PA1 | CV_IN_B | ADC1_IN1 | in | inject 0–3.3 V at H9.6 → `adc b` | BP PSU + console |
| PC0 | USR_POT_1 | ADC1_IN10 | in | inject 0–3.3 V at H9.4 → `pot` | BP PSU + console |
| PA2 | CLK_IN | TIM2_CH3 capture | in | gate→clk header loopback → `clk` | loopback + BP LA |
| PA3 | GATE_OUT_A | TIM2_CH4 | out | `gate a …`, read **H9.11** (3.3 V GPIO) | BP |
| PA6 | GATE_OUT_B | TIM3_CH1 | out | `gate b …`, read **H9.10** (3.3 V GPIO) | BP |
| PB1 | DAC_SPI_CS | GPIO out (SYNC) | out | `dac …`; frame timing | BP LA |
| PB13 | DAC_SPI_SCLK | SPI2_SCK | out | `dac …`; decode | BP `spi_*` / LA |
| PB15 | DAC_SPI_MOSI | SPI2_MOSI | out | `dac …`; decode | BP `spi_*` / LA |
| H3.6 | CV-OUT-A | DAC8552 B→OPA1642 U7 | out | `dac a mv 0..5000`, read **H3.6** | BP (≤5 V); Rigol for full 0–10 V |
| H3.7 | CV-OUT-B | DAC8552 A→OPA1642 U7 | out | `dac b mv 0..5000`, read **H3.7** | BP (≤5 V); Rigol for full 0–10 V |
| PA5 | OLED_SPI_SCLK | SPI1_SCK | out | `oled test`; clock activity | BP LA / Rigol |
| PA7 | OLED_SPI_MOSI | SPI1_MOSI | out | `oled test`; decode | BP `spi_*` / LA |
| PB12 | OLED_SPI_CS | GPIO out | out | `oled test`; framing | BP LA |
| PC1 | OLED_RES | GPIO out | out | reset pulse on `oled test` | BP LA / Rigol |
| PC2 | OLED_DC | GPIO out | out | toggles cmd/data | BP LA |
| PB3 | I2S3_CK (BCK) | I2S3 | out | `tone`; clock present | BP LA / Rigol |
| PB5 | I2S3_SD (DIN) | I2S3 | out | `tone`; data toggling | BP LA |
| PA15 | I2S3_WS (LRCK) | I2S3 | out | `tone`; ~Fs/64 of BCK | BP LA / Rigol |
| H2.3/H2.2 | A-OUT-L/-R | PCM5102A→buffer U16 | out | `tone 1000`; I2S decode now, F+VPP later | BP LA; Rigol for amplitude |
| PC6 | MUTE_N (XSMT) | GPIO out | out | `mute`; PC6 level (audio collapse on Rigol) | BP LA / SDK + console |
| PB6 | USR_ENC_A | TIM4_CH1 | in | inject edges at H4.2 → `enc` | BP + console |
| PB7 | USR_ENC_B | TIM4_CH2 | in | inject edges at H4.3 → `enc` | BP + console |
| PB4 | USR_ENC_SW | EXTI4 | in | pull H4.5 to GND → `enc` SW edge | BP + console |
| PA8 | SD_CD | GPIO in | in | insert/remove → `sd` | console (manual) |
| PC8–PC12 | SDIO D0–D3/CK | SDIO | i/o | `sd` mount + r/w/verify | console; BP LA optional |
| PD2 | SDIO_CMD | SDIO | i/o | covered by `sd` | console |
| PA11 / PA12 | USB DM / DP | USB FS | i/o | console link itself = pass | host enumeration |

## Per-subsystem procedures

All measurements/injections are **at the backing-board header pin** (IO board
absent). BP is primary; "read level" = `verify_connection` on the BP IO pin
clipped to that header pin, taking `voltage_range_mv`.

### 1. CV outputs (DAC8552 → OPA1642 U7, on backing) — read at H3.6/H3.7
1. BP IO clipped to **H3.6** (CV-OUT-A). Common ground.
2. Console `dac a mv 0 / 1000 / 2500 / 5000`; at each step read the level.
   **Stop at 5000 mV** — the chain swings 0–10 V full-scale, so >5000 mV
   exceeds BP input. (For the full 0–10 V span + calibration, use the Rigol.)
3. Expect a monotonic line, ~1:1 mV→mV over 0–5 V. Repeat on **H3.7**
   (CV-OUT-B). Watch for the documented A/B channel swap (firmware already
   maps jack A→DAC ch B).

### 2. Gate outputs (raw 3.3 V GPIO at the header) — read at H9.11/H9.10
1. BP IO clipped to **H9.11** (GATE-OUT-A). Common ground.
2. `gate a 0` → read ~3.3 V; `gate a 1` → read ~0 V. This is **non-inverting
   3.3 V GPIO** — correct for the backing board. (The MOSFET invert/+5 V
   level-shift is on the IO board; the firmware's inversion only takes effect
   once the IO board is attached.)
3. `gate a clk 120 1` → read over ~2 s: level toggles ~2 Hz (BP ~20 Hz
   sampling resolves it). For precise pulse width/edges use `la_*` or Rigol.
   Repeat for B at **H9.10**.

### 3. SPI bus — DAC (SPI2), backing-internal
1. BP logic analyzer on SPI2 SCK/MOSI/CS (PB13/PB15/PB1);
   `la_prepare` → `dac a 0x8000` (console) → `la_analyze` / `la_identify`,
   or `open_spi`+`spi_*` to decode.
2. Verify clock toggling, CS framing (DAC8552 = 24-bit frame, SYNC low for
   exactly 24 SCLK, **mode 1** per `cv-output-dac.md`), and MOSI data.
   (SPI1/OLED is already validated and out of scope.)

### 4. Audio (I2S3 → PCM5102A → buffer U16, on backing)
1. **Digital decode (BP):** logic analyzer on PB3/PB5/PA15 — confirm BCK
   present, LRCK ≈ BCK/64, data on DIN while `mute 0` + `tone 1000`.
2. **Mute (BP LA / SDK):** `mute 1` → DIN/I2S activity continues but the
   PCM5102A XSMT (PC6) asserts; confirm the PC6 level changes. Analog
   silence/return is only visible on the **Rigol** (audio is ~10 Vpp at
   H2.2/H2.3 — **never into the BP**).
3. **Amplitude (Rigol, deferred):** scope H2.3 AC-coupled, `tone 1000`,
   `measure FREQ`≈1 kHz and `VPP`≈10 Vpp.

### 5. ADC inputs (CV-IN, pot) — inject at the header, read console
1. `stream on`.
2. **CV-IN-A:** BP `set_voltage` 0 → 3.3 V in steps, output clipped to
   **H9.5**; `adc a` code should rise ~linearly (`code ≈ V/3.3×4095`). The
   inverted 0 V⇒2063 map of `cv-input.md` is an **IO-board op-amp** and is
   absent here. Repeat at **H9.6** for CV-IN-B. **Never** feed >5 V or
   negative into the BP. Keep injection ≤3.3 V (input protection clamps).
3. **Pot:** inject 0 → 3.3 V at **H9.4**; `pot` should sweep ~0 → ~4095.

### 6. Loopback self-tests (header-to-header patch, no external source)
- **Gate → Clock:** patch **H9.11 (GATE-OUT-A) → H9.8 (CLK-IN)**.
  `gate a clk 120 1`, then `clk` should report ≈120 BPM via TIM2 capture —
  exercises PA3 (out) and PA2 (capture) together (3.3 V edges are valid
  logic). BP LA on the net confirms the edges.
- **CV-OUT → CV-IN:** patch **H3.6 (CV-OUT-A) → H9.5 (CV-IN-A)**. Sweep
  `dac a mv 0…3300` only (keeps CV-IN ≤3.3 V); `adc a` code should track the
  commanded voltage. Exercises DAC→OPA1642→ADC with just a patch cable.

### 7. Encoder, USB (and SD)
- **Encoder (inject at header):** the encoder (SW1) is on the IO board, so
  pulse **H4.2/H4.3** with quadrature edges from the BP and confirm `enc`
  count moves; lead/lag of A vs B sets the sign (`dir=CW/CCW`). `enc` also
  prints the live A/B/SW pin levels — handy for confirming the BP is actually
  toggling the right header pin before chasing a count that won't move.
  `enc reset` zeroes the count for a clean baseline between sweeps. Pull
  **H4.5** to GND for the SW press; `enc` reports it as `last_sw=SHORT/LONG`.
- **USB:** if the console enumerates on COM13 and round-trips commands,
  PA11/PA12 are proven by definition.
- **SD:** backing-board-internal (card slot on the backing board) — `sd`
  card-detect + block-0 read still applies if a slot/card is present;
  otherwise defer.

## Coverage / limitations
- **Backing-board scope:** every signal pin is checked **at its header**;
  IO-board-side behaviour (MOSFET 0/+5 V gates, pot/encoder hardware,
  inverted CV-in map, jack wiring) is explicitly **out of scope** until the
  IO board is attached.
- **BP input ceiling (≤5 V, no negative):** CV-out is verified only over
  0–5 V, audio only via I2S decode, ±12 V not at all. Full 0–10 V CV-out,
  audio amplitude, and the ±12 V rails need the **Rigol + 10× probe**.
- Inputs with no on-board source (CV-in, pot, encoder) are tested by
  **injecting** a stimulus at the header; the console reports the reading.

## Safety
- Common ground before anything else — to a header GND pin (e.g. H9.1/3/7/
  9/12) or a board GND test point (no jack sleeves with the IO board off).
- Bus Pirate sees only Tachyon's 0–5 V / 3.3 V logic and its own PSU
  output — **never the ±12 V rails, the 0–10 V CV-out top half, or the
  ~10 Vpp audio**. Keep CV-out reads ≤ `dac _ mv 5000` and injections ≤3.3 V;
  use the scope with a 10× probe for anything higher.
- Scope probes at 10×; declare the ratio to rigol-mcp (only when attached).
- BP PSU and `set_power` are confirmation-gated — approve each deliberately,
  and double-check the target pin before enabling output.

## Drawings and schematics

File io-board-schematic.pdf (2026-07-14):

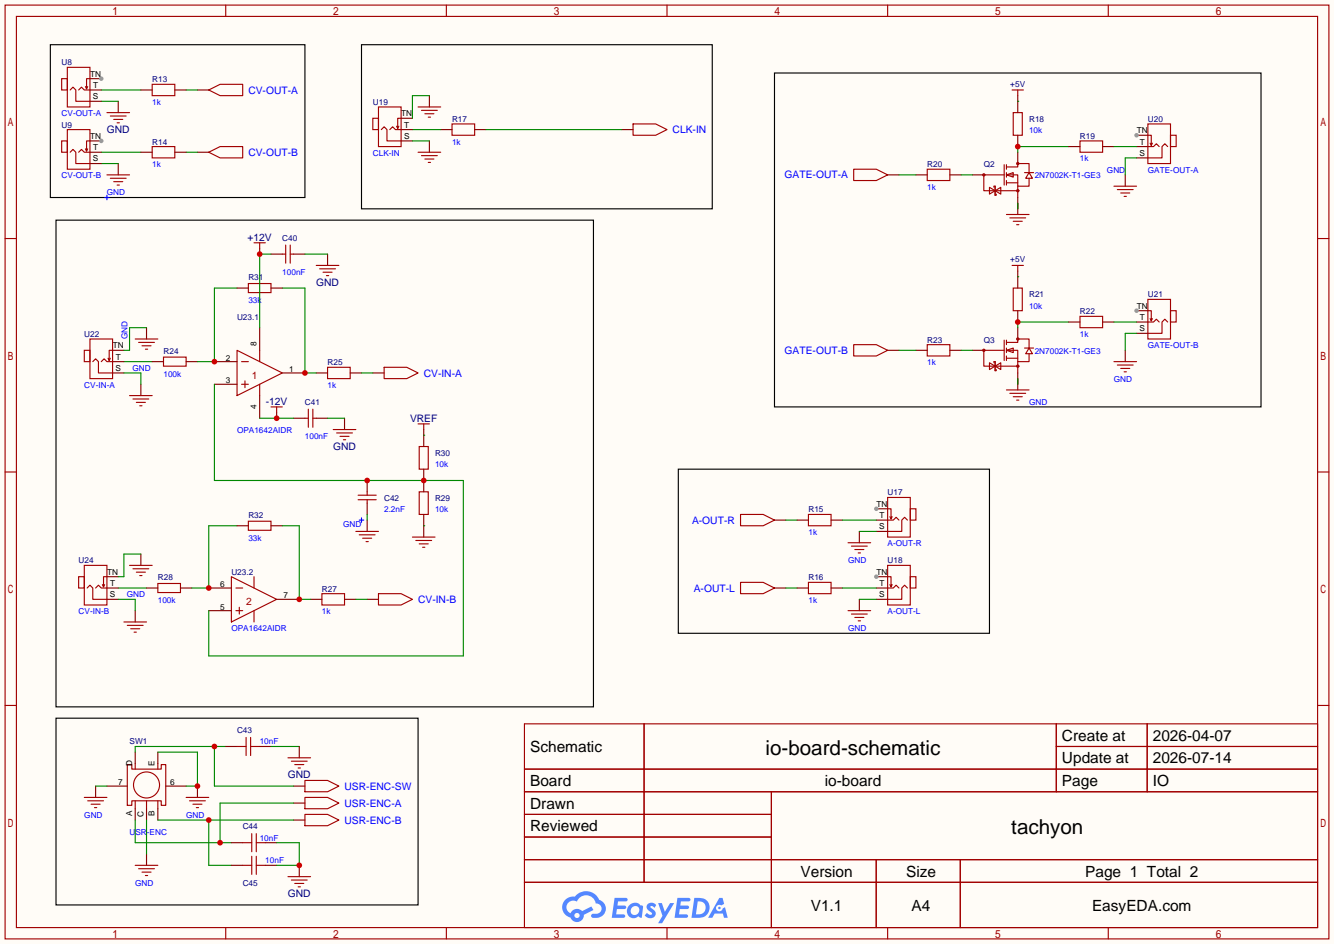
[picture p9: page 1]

Schematic | io-board-schematic | Create at | 2026-04-07

Update at | 2026-07-14

Board | io-board | Page | IO
Drawn | | tachyon
Reviewed

Version | Size | Page 1 Total 2
V1.1 | A4 | EasyEDA.com

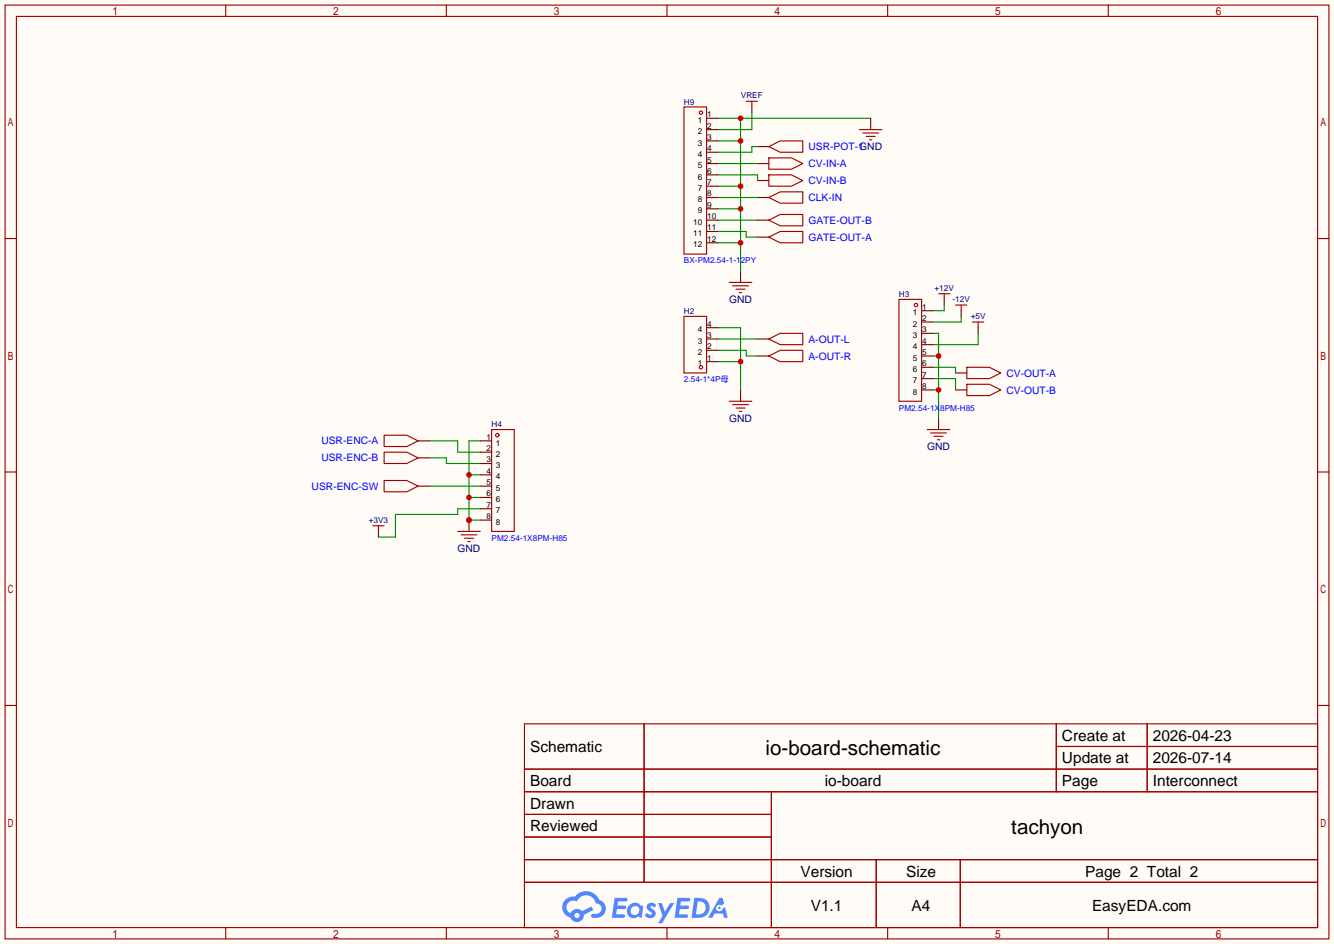
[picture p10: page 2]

Schematic | io-board-schematic | Create at | 2026-04-23

Update at | 2026-07-14

Board | io-board | Page | Interconnect
Drawn | | tachyon
Reviewed

Version | Size | Page 2 Total 2
V1.1 | A4 | EasyEDA.com

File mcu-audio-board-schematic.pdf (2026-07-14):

# GND MUTE

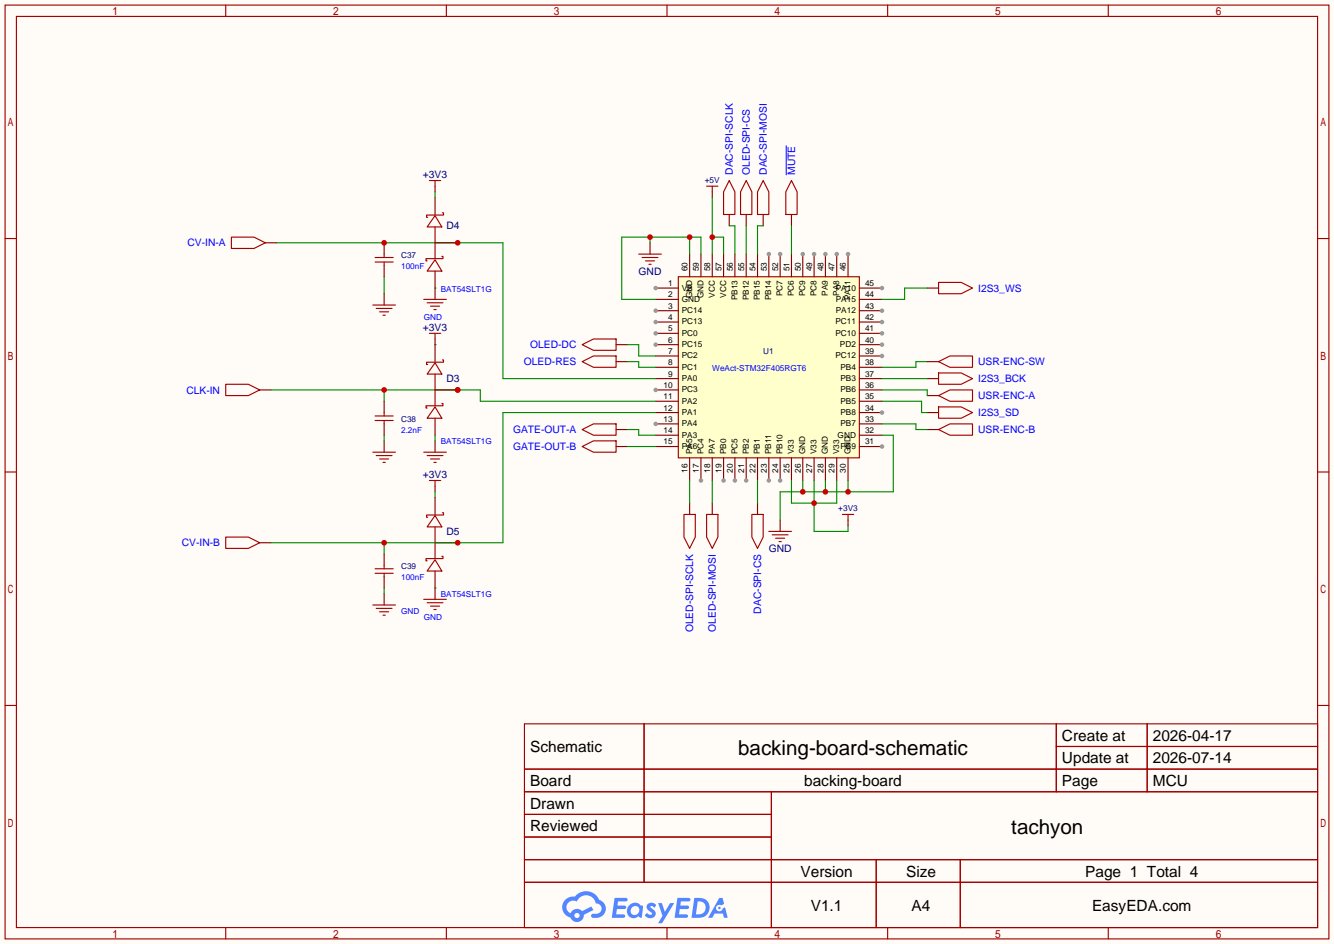
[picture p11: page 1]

DAC-SPI-MOSI DAC-SPI-CS

Schematic | backing-board-schematic | Create at | 2026-04-17

Update at | 2026-07-14

Board | backing-board | Page | MCU
Drawn | | tachyon
Reviewed

Version | Size | Page 1 Total 4
V1.1 | A4 | EasyEDA.com

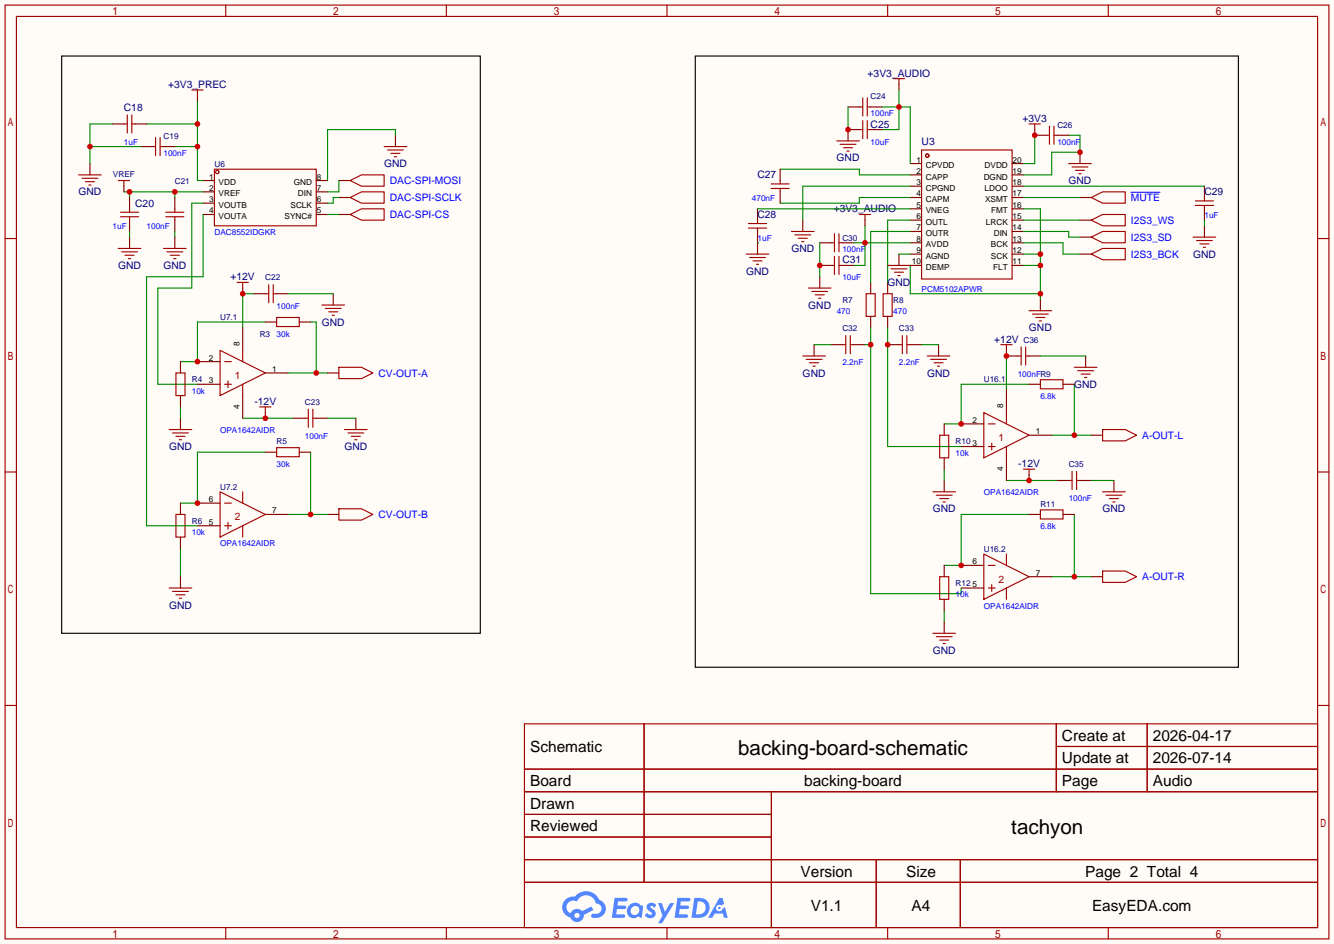
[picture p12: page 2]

Schematic | backing-board-schematic | Create at | 2026-04-17

Update at | 2026-07-14

Board | backing-board | Page | Audio
Drawn | | tachyon
Reviewed

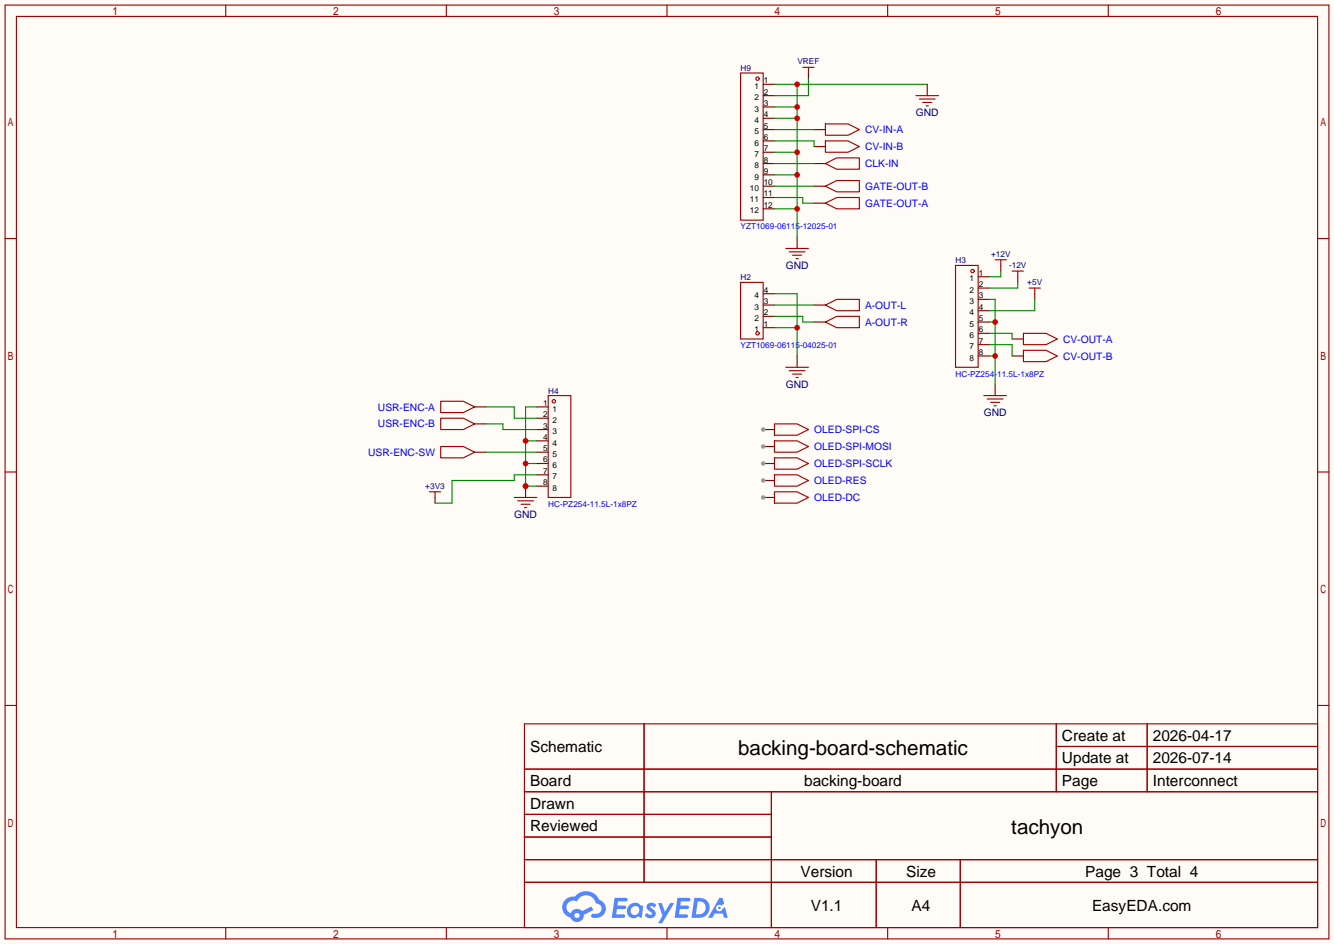
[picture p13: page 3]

Schematic | backing-board-schematic | Create at | 2026-04-17

Update at | 2026-07-14

Board | backing-board | Page | Interconnect
Drawn | | tachyon
Reviewed

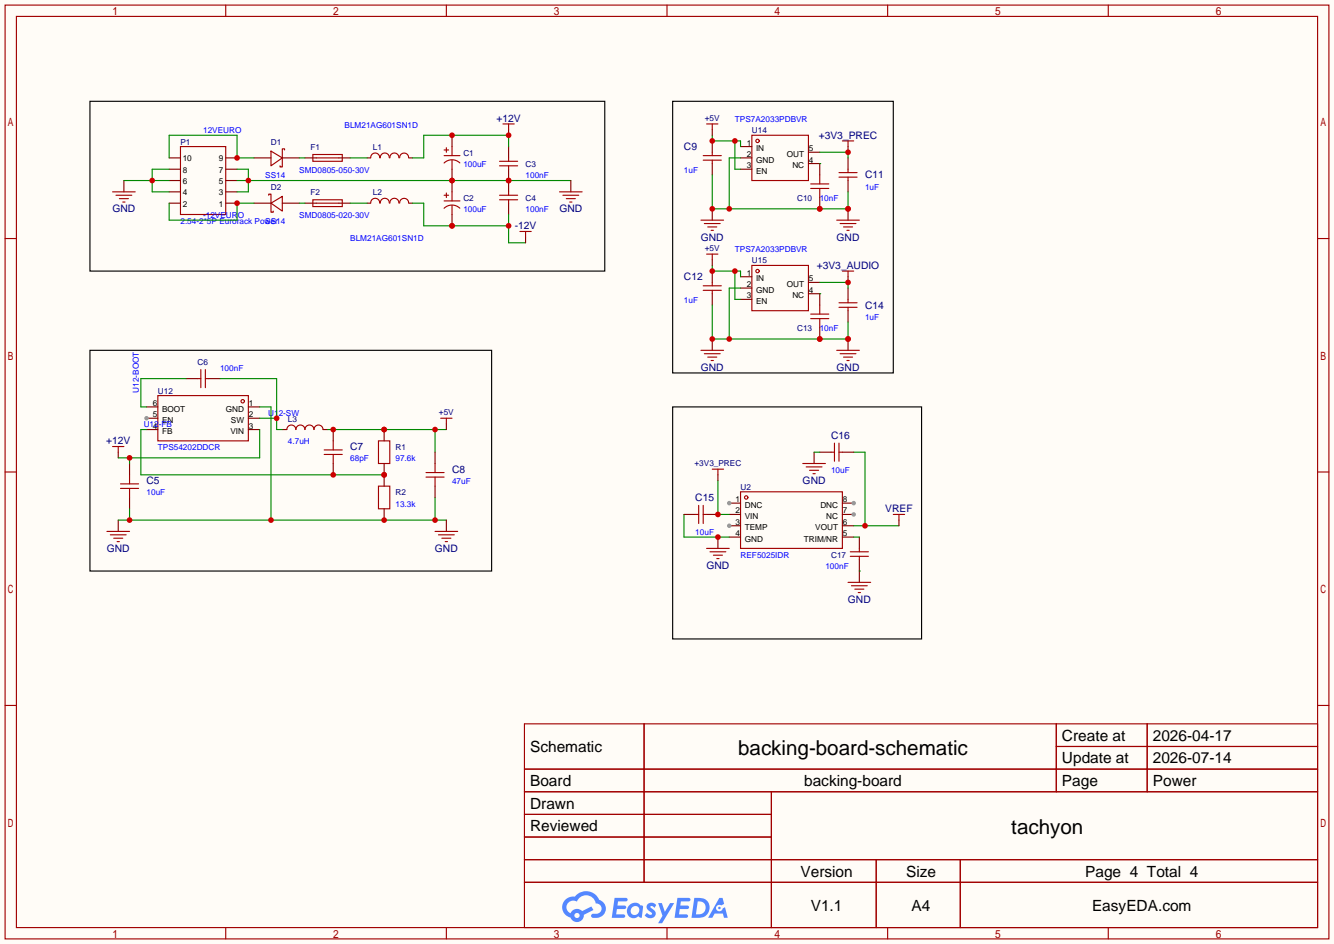
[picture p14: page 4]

Schematic | backing-board-schematic | Create at | 2026-04-17

Update at | 2026-07-14

Board | backing-board | Page | Power
Drawn | | tachyon
Reviewed

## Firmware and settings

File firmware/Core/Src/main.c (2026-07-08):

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
/* Includes ------------------------------------------------------------------*/
#include "main.h"
#include "usb_device.h"

/* USER CODE BEGIN Includes */
#include <stdio.h>
#include <math.h>
#include "usbd_cdc_if.h"
#include "DEV_Config.h"
#include "OLED_1in5.h"
#include "GUI_Paint.h"
#include "encoder.h"
#include "app.h"
#include "boot.h"
#include "audio.h"
#include "cv_out.h"
#include "gate_out.h"
#include "analog_in.h"
#include "clock_in.h"
#include "sd_fs.h"
#include "wt_osc.h"
/* USER CODE END Includes */

ADC_HandleTypeDef hadc1;

I2S_HandleTypeDef hi2s3;
DMA_HandleTypeDef hdma_spi3_tx;

SD_HandleTypeDef hsd;

SPI_HandleTypeDef hspi1;
SPI_HandleTypeDef hspi2;

TIM_HandleTypeDef htim2;
TIM_HandleTypeDef htim3;
TIM_HandleTypeDef htim4;

/* USER CODE BEGIN PV */
DMA_HandleTypeDef hdma_spi1_tx;   /* OLED frame blit: SPI1 TX on DMA2 Stream3 */
/* USER CODE END PV */

void SystemClock_Config(void);
static void MX_GPIO_Init(void);
static void MX_DMA_Init(void);
static void MX_SPI1_Init(void);
static void MX_TIM4_Init(void);
static void MX_I2S3_Init(void);
static void MX_SDIO_SD_Init(void);
static void MX_ADC1_Init(void);
static void MX_SPI2_Init(void);
static void MX_TIM2_Init(void);
static void MX_TIM3_Init(void);
/* USER CODE BEGIN 0 */
extern USBD_HandleTypeDef hUsbDeviceFS;

int _write(int file, char *ptr, int len)
{
    (void)file;
#if USB_SERIAL_DEBUG
    /* USB is the CDC console. No host connected? Drop the output — without this
     * the module would stall ~20 ms per printf when run standalone (CDC reports
     * busy / NULL handle until enumerated). printf becomes a harmless no-op. */
    if (hUsbDeviceFS.dev_state != USBD_STATE_CONFIGURED)
        return len;
    /* CDC_Transmit_FS drops the buffer (returns USBD_BUSY) while a previous
     * packet is still in flight, so back-to-back printf lines would be lost.
     * Wait briefly for the IN endpoint to free up; bound the wait so we never
     * block long even if the host stops draining the port. */
    uint32_t start = HAL_GetTick();
    while (CDC_Transmit_FS((uint8_t*)ptr, (uint16_t)len) == USBD_BUSY) {
        if ((HAL_GetTick() - start) >= 20U) break;
    }
#else
    /* USB is the MIDI device — route printf to SWO/ITM (debugger trace). Harmless
     * (the byte is dropped) when no SWV probe is attached. See usb-midi.md §3. */
    for (int i = 0; i < len; i++)
        (void)ITM_SendChar((uint32_t)(uint8_t)ptr[i]);
#endif /* USB_SERIAL_DEBUG */
    return len;
}
/* ---- timing diagnostics --------------------------------------------------
 * Measures, over a 2 s window: main-loop pass count + worst gap between passes
 * (DWT cycle counter, µs), worst render+blit duration, and arp inter-step
 * intervals (ms). One 'diag:' line per window so the printf itself (which can
 * stall ~20 ms per line when the CDC port isn't being drained) doesn't skew
 * what it measures — though such a stall WILL show up in the next window's
 * loop max. */
#define DIAG_PERIOD_MS 2000u

static struct {
  uint32_t loop_n, loop_max_cyc, last_cyc;
  uint8_t  have_last;
  uint32_t rend_n, rend_max_cyc, disp_max_cyc;
  uint32_t arp_n, arp_last_ms, arp_min_ms, arp_max_ms;
  uint32_t next_report;
} s_diag = { .arp_min_ms = 0xFFFFFFFFu };

static void diag_init(void)
{
  CoreDebug->DEMCR |= CoreDebug_DEMCR_TRCENA_Msk;
  DWT->CYCCNT = 0;
  DWT->CTRL |= DWT_CTRL_CYCCNTENA_Msk;
  s_diag.next_report = HAL_GetTick() + DIAG_PERIOD_MS;
}

void diag_arp_step(void)
{
  uint32_t now = HAL_GetTick();
  if (s_diag.arp_n++) {
    uint32_t dt = now - s_diag.arp_last_ms;
    if (dt < s_diag.arp_min_ms) s_diag.arp_min_ms = dt;
    if (dt > s_diag.arp_max_ms) s_diag.arp_max_ms = dt;
  }
  s_diag.arp_last_ms = now;
}

/* Call once per loop pass; prints + resets the window when due. */
static void diag_loop_pass(uint32_t now_ms, uint32_t rend_cyc, uint32_t disp_cyc)
{
  uint32_t cyc = DWT->CYCCNT;
  if (s_diag.have_last) {
    uint32_t d = cyc - s_diag.last_cyc;
    if (d > s_diag.loop_max_cyc) s_diag.loop_max_cyc = d;
  }
  s_diag.last_cyc = cyc;
  s_diag.have_last = 1;
  s_diag.loop_n++;
  if (rend_cyc) s_diag.rend_n++;
  if (rend_cyc > s_diag.rend_max_cyc) s_diag.rend_max_cyc = rend_cyc;
  if (disp_cyc > s_diag.disp_max_cyc) s_diag.disp_max_cyc = disp_cyc;

  if ((int32_t)(now_ms - s_diag.next_report) >= 0) {
    uint32_t cyc_per_us = SystemCoreClock / 1000000u;
    printf("diag: loop n=%lu max=%luus | rend n=%lu max=%luus disp max=%luus dirty=%d | arp n=%lu dt=%lu..%lums\r\n",
           (unsigned long)s_diag.loop_n,
           (unsigned long)(s_diag.loop_max_cyc / cyc_per_us),
           (unsigned long)s_diag.rend_n,
           (unsigned long)(s_diag.rend_max_cyc / cyc_per_us),
           (unsigned long)(s_diag.disp_max_cyc / cyc_per_us),
           (int)app_dirty(),
           (unsigned long)s_diag.arp_n,
           (unsigned long)(s_diag.arp_n > 1 ? s_diag.arp_min_ms : 0),
           (unsigned long)(s_diag.arp_n > 1 ? s_diag.arp_max_ms : 0));
    s_diag.loop_n = 0;
    s_diag.loop_max_cyc = 0;
    s_diag.rend_n = 0;
    s_diag.rend_max_cyc = 0;
    s_diag.disp_max_cyc = 0;
    s_diag.arp_n = s_diag.arp_n ? 1u : 0u;   /* keep last step as the new baseline */
    s_diag.arp_min_ms = 0xFFFFFFFFu;
    s_diag.arp_max_ms = 0;
    s_diag.next_report = now_ms + DIAG_PERIOD_MS;
  }
}
/* USER CODE END 0 */

/**
  * @brief  The application entry point.
  * @retval int
  */
int main(void)
{

  /* MCU Configuration--------------------------------------------------------*/

  /* Reset of all peripherals, Initializes the Flash interface and the Systick. */
  HAL_Init();

  /* Configure the system clock */
  SystemClock_Config();

  /* Initialize all configured peripherals */
  MX_GPIO_Init();
  MX_DMA_Init();
  MX_USB_DEVICE_Init();
  MX_SPI1_Init();
  MX_TIM4_Init();
  MX_I2S3_Init();
  /* SD card detect is NC switch: LOW=no card, HIGH=card inserted */
  if (HAL_GPIO_ReadPin(SD_CD_GPIO_Port, SD_CD_Pin) == GPIO_PIN_SET) {
    MX_SDIO_SD_Init();
  }
  MX_ADC1_Init();
  MX_SPI2_Init();
  MX_TIM2_Init();
  MX_TIM3_Init();
  /* USER CODE BEGIN 2 */
  HAL_Delay(1000);
  printf("USB ready\r\n");

  /* Mount the SD card; the app loads/selects wavetables from it. */
  if (HAL_GPIO_ReadPin(SD_CD_GPIO_Port, SD_CD_Pin) == GPIO_PIN_SET) {
    if (sd_fs_mount()) sd_fs_dump_root();
  } else {
    printf("No SD card detected\r\n");
  }

  System_Init();
  OLED_1in5_Init();
  OLED_1in5_Clear();

  static UBYTE image[128 * 128 / 2];
  Paint_NewImage(image, 128, 128, 0, BLACK);
  Paint_SetScale(16);
  Paint_SelectImage(image);

  encoder_init();
  printf("Encoder initialized\r\n");
  printf("OLED initialized\r\n");

  /* Load SD data (folder list + default wavetable) NOW, while audio is still
   * off — SD reads here have no audio-DMA/render-IRQ contention. The user
   * expects silence during the boot splash anyway. */
  app_preload();

  /* Power-on starfield hyperdrive splash (5 s). */
  boot_splash(image, 5000);

  /* Bring up the signal-IO driver layer. audio_init starts the continuous
   * (muted) I2S stream so the PCM5102A clocks stay locked; cv_out/gate_out
   * settle to a safe zero state; analog_in/clock_in arm their inputs. */
  audio_init();
  cv_out_init();
  gate_out_init();
  analog_in_init();
  clock_in_init();

  /* Wavetable oscillator is the audio voice: install it on the render seam. */
  wt_osc_init();
  wt_osc_install();

  /* Boot into the menu; app_init points the oscillator at the preloaded
   * wavetable (silent until a note is gated on). */
  app_init();
  /* USER CODE END 2 */

  /* Infinite loop */
  /* USER CODE BEGIN WHILE */
  /* Display frame pacing. Logic (inputs, arp, gates) runs every pass — sub-ms
   * period — so step/gate timing is tight; drawing + the 8 KB SPI frame push
   * (the slow part) runs only every FRAME_MS. */
  #define FRAME_MS 33u
  uint32_t next_frame = HAL_GetTick();
  diag_init();
  while (1)
  {
    /* USER CODE END WHILE */

    /* USER CODE BEGIN 3 */
    uint32_t now = HAL_GetTick();

    /* Refresh inputs first so app_tick (arp external-clock stepping) sees the
     * freshest CLK-IN edge this pass. */
    clock_in_poll(now);
    analog_in_sample();

    app_tick();

    uint32_t rend_cyc = 0, disp_cyc = 0;
    if (app_dirty() && (int32_t)(now - next_frame) >= 0) {
      uint32_t t0 = DWT->CYCCNT;
      app_render();
      uint32_t t1 = DWT->CYCCNT;
      OLED_1in5_Display(image);
      disp_cyc = DWT->CYCCNT - t1;
      rend_cyc = t1 - t0;
      next_frame = now + FRAME_MS;
    }

    /* Apply gate timing after the app may have (re)started pulses this pass. */
    gate_out_service(now);

    diag_loop_pass(now, rend_cyc, disp_cyc);
  }
  /* USER CODE END 3 */
}

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
/* USER CODE BEGIN 4 */
void HAL_GPIO_EXTI_Callback(uint16_t GPIO_Pin)
{
  if (GPIO_Pin == USR_ENC_SW_Pin) {
    encoder_button_isr();
  }
}
/* USER CODE END 4 */
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


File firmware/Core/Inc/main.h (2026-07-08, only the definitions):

#define USR_POT_1_Pin GPIO_PIN_0
#define USR_POT_1_GPIO_Port GPIOC
#define OLED_RES_Pin GPIO_PIN_1
#define OLED_RES_GPIO_Port GPIOC
#define OLED_DC_Pin GPIO_PIN_2
#define OLED_DC_GPIO_Port GPIOC
#define CV_IN_A_Pin GPIO_PIN_0
#define CV_IN_A_GPIO_Port GPIOA
#define CV_IN_B_Pin GPIO_PIN_1
#define CV_IN_B_GPIO_Port GPIOA
#define CLK_IN_Pin GPIO_PIN_2
#define CLK_IN_GPIO_Port GPIOA
#define GATE_OUT_A_Pin GPIO_PIN_3
#define GATE_OUT_A_GPIO_Port GPIOA
#define OLED_SPI_SCLK_Pin GPIO_PIN_5
#define OLED_SPI_SCLK_GPIO_Port GPIOA
#define GATE_OUT_B_Pin GPIO_PIN_6
#define GATE_OUT_B_GPIO_Port GPIOA
#define OLED_SPI_MOSI_Pin GPIO_PIN_7
#define OLED_SPI_MOSI_GPIO_Port GPIOA
#define DAC_SPI_CS_Pin GPIO_PIN_1
#define DAC_SPI_CS_GPIO_Port GPIOB
#define OLED_SPI_CS_Pin GPIO_PIN_12
#define OLED_SPI_CS_GPIO_Port GPIOB
#define MUTE_N_Pin GPIO_PIN_6
#define MUTE_N_GPIO_Port GPIOC
#define SD_CD_Pin GPIO_PIN_8
#define SD_CD_GPIO_Port GPIOA
#define USR_ENC_SW_Pin GPIO_PIN_4
#define USR_ENC_SW_GPIO_Port GPIOB
#define USR_ENC_SW_EXTI_IRQn EXTI4_IRQn
#define USR_ENC_A_Pin GPIO_PIN_6
#define USR_ENC_A_GPIO_Port GPIOB
#define USR_ENC_B_Pin GPIO_PIN_7
#define USR_ENC_B_GPIO_Port GPIOB

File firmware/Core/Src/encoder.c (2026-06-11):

#include "encoder.h"
#include "main.h"

/* TIM4 is configured in x4 encoder mode. The fitted EC11E18244AU is a
 * 36-detent / 18-pulse part: 18 electrical cycles/rev x 4 counts/cycle = 72
 * counts/rev, over 36 detents = 2 counts/detent (i.e. it rests at a half-cycle
 * detent, 2 detents per electrical cycle). This matches the datasheet and the
 * bench measurement (10 detents -> 20 counts). We divide by 2 to return detent
 * units. */
#define COUNTS_PER_DETENT   2

/* Long-press threshold in ms. See user-interface.md §2.5. */
#define LONG_PRESS_MS       500

/* Software debounce on the switch, on top of the 10 nF cap.
 * With the KY-040 breakout (no cap) this also handles contact bounce. */
#define DEBOUNCE_MS         10

extern TIM_HandleTypeDef htim4;

static int16_t  s_last_count;       /* signed snapshot of TIM4->CNT */
static int32_t  s_detent_residual;  /* leftover raw counts < 4 */

static volatile uint8_t  s_btn_pressed;    /* 1 while SW is held down */
static volatile uint16_t s_btn_hold_ms;    /* how long it's been held */
static volatile uint8_t  s_btn_debounce;   /* debounce countdown after edge */
static volatile encoder_btn_event_t s_btn_event;
static volatile uint8_t  s_long_press_fired; /* latched so we only fire once */

void encoder_init(void)
{
    HAL_TIM_Encoder_Start(&htim4, TIM_CHANNEL_ALL);
    s_last_count = (int16_t)__HAL_TIM_GET_COUNTER(&htim4);
    s_detent_residual = 0;
    s_btn_pressed = 0;
    s_btn_hold_ms = 0;
    s_btn_debounce = 0;
    s_btn_event = ENC_BTN_NONE;
    s_long_press_fired = 0;
}

int32_t encoder_get_delta(void)
{
    int16_t  now  = (int16_t)__HAL_TIM_GET_COUNTER(&htim4);
    int16_t  diff = (int16_t)(now - s_last_count); /* wraps correctly mod 2^16 */
    s_last_count = now;

    int32_t raw = s_detent_residual + diff;
    int32_t detents = raw / COUNTS_PER_DETENT;
    s_detent_residual = raw - (detents * COUNTS_PER_DETENT);
    return detents;
}

encoder_btn_event_t encoder_get_button_event(void)
{
    encoder_btn_event_t ev = s_btn_event;
    s_btn_event = ENC_BTN_NONE;
    return ev;
}

/* Falling edge: button just went down. */
void encoder_button_isr(void)
{
    if (s_btn_debounce == 0 && !s_btn_pressed) {
        s_btn_pressed = 1;
        s_btn_hold_ms = 0;
        s_btn_debounce = DEBOUNCE_MS;
        s_long_press_fired = 0;
    }
}

/* Called from SysTick at 1 kHz. Handles:
 *  - debounce window after press
 *  - detecting release (poll PB4 level)
 *  - firing long-press while still held
 *  - firing short-press on release
 */
void encoder_tick_1ms(void)
{
    if (s_btn_debounce) {
        s_btn_debounce--;
    }

    if (!s_btn_pressed) {
        return;
    }

    s_btn_hold_ms++;

    /* Long press fires as soon as threshold is crossed, even before release. */
    if (!s_long_press_fired && s_btn_hold_ms >= LONG_PRESS_MS) {
        s_long_press_fired = 1;
        s_btn_event = ENC_BTN_LONG_PRESS;
    }

    /* Poll the pin to detect release (no rising-edge EXTI configured). */
    if (HAL_GPIO_ReadPin(USR_ENC_SW_GPIO_Port, USR_ENC_SW_Pin) == GPIO_PIN_SET) {
        s_btn_pressed = 0;
        s_btn_debounce = DEBOUNCE_MS;
        if (!s_long_press_fired) {
            s_btn_event = ENC_BTN_SHORT_PRESS;
        }
    }
}

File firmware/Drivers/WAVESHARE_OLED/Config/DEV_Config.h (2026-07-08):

/******************************************************************************
**************************Hardware interface layer*****************************
* | file      		:	DEV_Config.h
* |	version			:	V1.0
* | date			:	2020-06-17
* | function		:	Provide the hardware underlying interface
******************************************************************************/
#ifndef _DEV_CONFIG_H_
#define _DEV_CONFIG_H_

#include "stm32f4xx_hal.h"
#include "main.h"
#include <stdint.h>
#include <stdlib.h>

/**
 * data
**/
#define UBYTE   uint8_t
#define UWORD   uint16_t
#define UDOUBLE uint32_t

#define USE_SPI_4W 		1
#define USE_IIC 		0
#define USE_IIC_SOFT	0

#define IIC_CMD		0X00
#define IIC_RAM		0X40

//OLED GPIO — pin names match CubeMX labels
#define OLED_CS_0		HAL_GPIO_WritePin(OLED_SPI_CS_GPIO_Port, OLED_SPI_CS_Pin, GPIO_PIN_RESET)
#define OLED_CS_1		HAL_GPIO_WritePin(OLED_SPI_CS_GPIO_Port, OLED_SPI_CS_Pin, GPIO_PIN_SET)

#define OLED_DC_0		HAL_GPIO_WritePin(OLED_DC_GPIO_Port, OLED_DC_Pin, GPIO_PIN_RESET)
#define OLED_DC_1		HAL_GPIO_WritePin(OLED_DC_GPIO_Port, OLED_DC_Pin, GPIO_PIN_SET)

#define OLED_RST_0		HAL_GPIO_WritePin(OLED_RES_GPIO_Port, OLED_RES_Pin, GPIO_PIN_RESET)
#define OLED_RST_1		HAL_GPIO_WritePin(OLED_RES_GPIO_Port, OLED_RES_Pin, GPIO_PIN_SET)

/*------------------------------------------------------------------------------------------------------*/

UBYTE 	System_Init(void);
void    System_Exit(void);

UBYTE 	SPI4W_Write_Byte(UBYTE value);
void 	SPI4W_Write_nByte(const UBYTE *buf, UWORD len);
UBYTE 	SPI4W_Write_DMA(const UBYTE *buf, UWORD len);   /* 0 = started */
void 	SPI4W_Wait_Idle(void);                          /* spin until DMA done */
void 	I2C_Write_Byte(UBYTE value, UBYTE Cmd);

void Driver_Delay_ms(uint32_t xms);
void Driver_Delay_us(uint32_t xus);

#endif

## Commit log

2026-04-08 Add schematic images to README
2026-04-12 Add SSD1327 OLED display support via Waveshare driver over SPI1
2026-04-12 Add circle of fifths UI test animation
    Replaces hello world with an animated circle of fifths that cycles
    through all 12 notes as a UI test. Note labels are pre-rendered via
    Python (generate_note_sprites.py) using RobotoCondensed-Bold for
    anti-aliased rotated text sprites.
    [main.c]
2026-04-12 Add smooth animation, pre-rendered text sprites, detent dots, 168MHz
    UI test animation now uses continuous rotation with snapping segments,
    pre-rendered note name sprites (generated via Python with Roboto font),
    and detent dot indicators along the arc edge. Clock upgraded to HSE at
    168MHz with SPI at 10.5MHz. User sources moved to top-level CMakeLists
    to survive CubeMX regeneration.
    [firmware.ioc, main.c]
2026-04-15 Add rotary encoder input with mark/unmark on circle of fifths
    Wire EC11E18244AU encoder to PB6/PB7 (TIM4 hardware quadrature) and
    PB3 (EXTI switch). Encoder driver returns detent deltas and short/long
    press events. Rotation steps the circle of fifths in 30 degree detents;
    short press toggles a black inset border on the centered note; long
    press clears all marks. Sprite set reduced from 5 to 3 angles per note.
    Schematic updated with encoder symbol and 10 nF debounce caps.
    [encoder.c, firmware.ioc, main.c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]
2026-04-15 Update schematic exports and add power schematic to README
2026-04-16 Reassign pins to enable onboard SDIO MicroSD
    The WeAct board has an onboard MicroSD slot on PC8-PC12/PD2 (SDIO),
    which conflicted with I2S3 (PCM5102A audio DAC) on PC10/PC12.
    Pin changes:
    - I2S3_CK: PC10 -> PB3 (AF6 alternate)
    - I2S3_SD: PC12 -> PB5 (AF6 alternate)
    - USR-ENC-SW: PB3 -> PB4
    - OLED-DC: PB4 -> PC2
    - OLED-RES: PB5 -> PC1
    - SDIO enabled: PC8-PC12, PD2 (AF12), PA8 card detect
    CubeMX regenerated with I2S3 (192kHz/32-bit), SDIO 4-bit wide bus,
    and EXTI4 for encoder switch. SDIO init deferred at startup to avoid
    hanging when no card is inserted.
    [encoder.c, firmware.ioc, main.c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]
2026-04-16 Add ADC1, SPI2, TIM2, TIM3 pin assignments and fix SD card detect
    Add 10 missing peripheral pins to CubeMX config:
    - ADC1: PA0 (CV_IN_A), PA1 (CV_IN_B), PC0 (USR_POT_1)
    - TIM2: PA2 (CLK_IN input capture), PA3 (GATE_OUT_A output compare)
    - TIM3: PA6 (GATE_OUT_B PWM)
    - SPI2: PB13/PB15 (DAC8552 dedicated bus, Mode 1)
    - GPIO: PB1 (DAC_SPI_CS, init HIGH), PC6 (MUTE_N, init HIGH)
    Fix SD card detect: WeAct MicroSD slot uses NC switch (LOW=no card,
    HIGH=card inserted). Add internal pull-up on PA8 and guard SDIO init
    so it only runs when a card is actually present.
    [firmware.ioc, main.c, main.h]
2026-04-22 Update BOM designators, REF5025 rail, and PCB layer naming
    - Populate real component designators (C, R, U) across schematic docs
    - Move REF5025 VIN from +5V to +3V3_PREC
    - Rename audio buffer U10 to U16
    - Rename PCB stackup layers to Layer 1-4 to disambiguate from L1/L2 ferrites
    - Note CV output channel swap between DAC8552 and OPA1642
    - Update REF5025 tolerances to I-grade in calibration
    - Add backing PCB 3D render to README
2026-04-29 Split design into IO and MCU/audio boards, add Gerbers, set 10 HP format
    [Drill_PTH_Through.DRL, Drill_PTH_Through_Via.DRL, Gerber_BoardOutlineLayer.GKO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]
2026-04-30 Add front and IO PCB 3D renders to README
2026-04-30 Update backing PCB 3D render
2026-04-30 Renumber designators across IO board and re-export Gerbers
    Free up R7/R8 (now PCM5102A audio EMI series resistors) by moving the
    TPS54202 feedback divider to R1/R2. CV output protection R_PROT_A/B
    become R13/R14 on the IO board; CV output feedback resistors shift to
    R3-R6. Audio buffer feedback shuffles to R10/R9/R12/R11 and series
    resistors to R15/R16. Audio channels swap so OUT_L drives U18 and OUT_R
    drives U17.
    CV-input anti-alias caps move to the WeAct ADC pin on the backing as
    C37/C39, with D4/D5 alongside. Encoder caps named C43-C45, pot wiper
    reservoir cap C46. Pot upgraded 10K -> 100K (Alps RK09K1130C0L,
    designator U25); higher source impedance is absorbed by C46 acting as
    the ADC s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
    [Drill_NPTH_Through.DRL, Drill_PTH_Through.DRL, Drill_PTH_Through_Via.DRL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]
2026-05-04 Add pcb-designer skill and reconcile design docs with as-built layout
    - New .claude/skills/pcb-designer/ with run_audit.py end-to-end audit
    script, .tel / PnP / gerber parsers, and format references
    - Per-board audit MDs at gerber/audit-<board>.md (front, IO, backing)
    - pcb-design.md §5 rewritten: stratified-layout description replaces
    the cardinal Zone A/B/C diagram; spacing rules codify the real
    engineering invariants; I2S series-termination analysis (Howard
    Johnson length-vs-edge-rate) replaces the unconditional 33 ohm
    mandate
    - pcb-design.md §4 + power-supply.md: corrected PCM5102A pin numbers
    (AVDD=8, CPVDD=1, DVDD=20) and dropped 74AHCT1G125 buffer references
    (the part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
    [Drill_NPTH_Through.DRL, Drill_PTH_Through.DRL, Drill_PTH_Through_Via.DRL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]
2026-05-05 Update README to cover IO board, full subsystem doc set, and Gerber outputs
2026-05-05 Tighten README intro wording and add Software required section
2026-05-12 Fix silkscreen errors on audio/MCU board and re-export Gerbers
    [Drill_PTH_Through.DRL, Drill_PTH_Through_Via.DRL, Gerber_BoardOutlineLayer.GKO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]
2026-06-03 Add firmware-test STM32F405 bring-up project
2026-06-05 Fix A-OUT-L: unshort U16A inputs, set buffer gain to 1.68x
    Re-exported audio-mcu-board gerbers + schematic; project now tachyon.eprj2. Needs refab.
    [Drill_PTH_Through.DRL, Drill_PTH_Through_Via.DRL, Gerber_BoardOutlineLayer.GKO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]
2026-06-05 Add firmware test harness for exercising IO over serial commands
    Console accepts serial commands to drive/read board IO for bring-up; this change adds I2S3 DMA tone streaming to the PCM5102A audio path.
2026-06-05 Document PCM5102A I2S clocking rules in firmware README
    Internal-PLL 3-wire mode requires continuously-running BCK/LRCK; covers circular-DMA streaming, PLL lock, and XSMT mute sequencing.
2026-06-10 firmware-test: menu UI + DAC8552 channel-select fix; DAC docs & audit tooling
    Firmware (test harness):
    - Add an on-device OLED menu UI (encoder navigation + pot parameter) running
    in parallel with the USB-CDC command console; drop the old per-command
    status-display code. Recalibrate the encoder to 2 counts/detent (bench-
    measured for the fitted part; was 4).
    - Fix DAC8552 channel select in dac_write(): the old code set DB21 as if it
    were the channel bit, but the channel is the DB18 buffer-select. Every write
    therefore landed in DAC A, so VOUTB (CV-out A) was never driven and looked
    like a dead DAC channel. Use the canonical control bytes 0x24 (write+update
    DAC B) / 0x10 (DAC A)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
    [encoder.c, test_console.c]
2026-06-10 pcb-designer: datasheet-driven mandatory power/ground pin check
    Pass 2 now reads each IC's datasheet pinout (DATASHEET_BY_DESIGNATOR map) and
    asserts every Power (Direction P) / Ground (Direction G) pin is connected to a
    real multi-pin net — ground pins specifically on a ground net — while excluding
    DNC/NC pins. A required supply/GND pin netlisted as a no-connect is flagged as
    a layout error: a logical rail check passes such a board, but the part reads
    dead or DC-offset on the bench. This is the class of the U6 (DAC8552) pin-8 GND
    omission, which the prior audit missed. Unlike the hand-maintained
    EXPECTED_IC_PINS allow-list, this derives the full power/GND pin set straight
    from the datas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
2026-06-10 Re-export backing-board gerbers + EasyEDA project after U6 GND fix
    Fresh EasyEDA Pro export of the backing (audio-mcu) board: regenerated gerbers
    and updated tachyon.eprj2. The recent netlist now connects U6 (DAC8552) pin 8
    to GND — the schematic omission that left the DAC's ground reference floating
    on the assembled board.
    [Drill_PTH_Through.DRL, Drill_PTH_Through_Via.DRL, Gerber_BoardOutlineLayer.GKO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]
2026-06-11 firmware-test: float-print, 56-cyc ADC sampling, CLK-IN BPM/PPQN + IC filter
    Bring-up harness fixes found during the bench session:
    - Link newlib float-print (`-u _printf_float`; newlib-nano omits it) so the
    `clk`/`adc` commands and the OLED render their %f fields instead of blanks.
    - ADC sample time 3 -> 56 cycles (cv-input.md §5) for the ~1 kOhm CV-in source.
    - CLK-IN tempo: was `freq*60` (BPM@1PPQN), which reads 4x high against a
    standard Doepfer/Eurorack 4-PPQN "step clock". Now `BPM = freq*60/CLK_PPQN`
    with CLK_PPQN=4 on both the OLED and serial `clk` (OLED shows the PPQN basis).
    Bench-verified: a ~70 BPM 4-PPQN source (4.70 Hz) now reads 70.5 BPM.
    - CLK-IN capture: ICFilter 0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
    [main.c, test_console.c]
2026-06-11 Gerber and EasyEDA project fixes
    Fix for U6 pin-8 GND missing
    Fix for CLK-IN to PA2 vs PC3
    [Drill_PTH_Through.DRL, Drill_PTH_Through_Via.DRL, Gerber_BoardOutlineLayer.GKO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]
2026-06-11 Update encoder.c
    Fix encoder detent/pulse rate
    [encoder.c]
2026-06-13 firmware: menu UI, signal-IO drivers, arpeggiator, Inter menu, boot splash
    Application layer
    - app.c state machine: boot menu -> Key Select (circle-of-fifths) / Arp /
    Playback; encoder nav, long-press = back.
    - Key Select drives pitch CV (CV-OUT-A, 1V/oct), preview tone, and gate
    pulses; rotating the key transposes live.
    Signal-IO driver layer (Core/IO), ported from the bench-validated
    firmware-test console:
    - audio: PCM5102A I2S engine, continuous circular DMA, pluggable render
    callback + built-in tone, XSMT mute. Adds the I2S DMA plumbing
    (hdma_spi3_tx, MX_DMA_Init, DMA1_Stream5 IRQ, __HAL_LINKDMA).
    - cv_out: DAC8552 with jack<->channel swap + calibrated volts->code.
    - gate_out: g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
    [analog_in.c, app.c, audio.c]
2026-06-13 Silkscreen jack labels for front panel
    [Drill_NPTH_Through.DRL, Drill_PTH_Through.DRL, Gerber_BoardOutlineLayer.GKO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]
2026-06-13 firmware: SD-card filesystem (FatFs exFAT/GPT) + folder enumeration
    Phase 1 of wavetable/multisample synthesis: bring up read access to the
    korgmultisample folders on the SD card.
    - Vendor ChaN FatFs R0.15 (Middlewares/Third_Party/FatFs) configured
    read-only with LFN + exFAT + 64-bit LBA (GPT). The stock cards are
    exFAT-formatted and GPT-partitioned, both of which FatFs only handles
    with FF_FS_EXFAT=1 and FF_LBA64=1.
    - sd_diskio.c: HAL_SD polling glue (pdrv 0), aligned bounce buffer for
    unaligned callers, failure diagnostics. SDIO_CK lowered to 4.8 MHz
    (ClockDiv=8) so the -O0 polling read loop does not RX-overrun the FIFO;
    samples are loaded to RAM once, so read speed is irrelev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
    [main.c, sd_diskio.c, sd_fs.c]
2026-06-13 firmware: WAV + korgmultisample parsers -> in-RAM zone table
    Phase 2 of wavetable synthesis: turn a sample folder into a loaded
    multisample (per-octave single-cycle wavetables with key mapping).
    - wav.c/.h: minimal RIFF/WAVE reader (fmt + data chunks); reads 16-bit
    mono PCM payloads.
    - korg_ms.c/.h: parser for the Korg .korgmultisample format ("Korg"
    magic + 3 length-prefixed chunks; chunk 3 = name + sample key-zones).
    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
2026-06-13 firmware: make printf USB-safe when the CDC host is absent
    _write() now returns immediately unless the USB device is enumerated
    (dev_state == USBD_STATE_CONFIGURED). Without this, running the module
    standalone (no USB host) stalled the main loop ~20 ms per printf, since
    CDC_Transmit_FS reports busy / has a NULL class handle until configured.
    printf is now a harmless no-op when unplugged, so the module runs cleanly
    on its own while the debug console still works when a host is connected.
    [main.c]
2026-06-13 firmware: wavetable oscillator as the audio voice + I2S tuning fix
    Phase 3 of wavetable synthesis: play the loaded multisample through a
    single-cycle wavetable oscillator, driven by the arp/key-preview.
    - wt_osc.c/.h: phase-accumulator oscillator on the audio_set_render seam.
    Selects the zone by the played note's key range, walks the one-cycle
    table with linear interpolation, phase_inc = f * frames / Fs. Output
    pitch comes from the played note, so it is independent of the table's
    recorded rate (the zone choice band-limits per octave). Params are
    swapped under a short critical section; the render runs in the I2S IRQ.
    - app.c: drive wt_osc_note()/wt_osc_gate_off() instead of the sin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
    [app.c, main.c]
2026-06-13 firmware: CV VCO free-run mode with semitone quantization
    Phase 4 of wavetable synthesis: a free-running voice whose pitch tracks
    CV-IN-A at 1 V/oct, switchable from the menu ("CV VCO"), alongside the
    note-triggered arp/key-preview voice.
    - wt_osc: add wt_osc_set_pitch() — update pitch/zone and keep sounding
    WITHOUT restarting the table phase, so CV-tracked pitch glides without
    clicks (vs wt_osc_note() which retriggers for a clean note attack).
    - app: new CV VCO screen. Reads CV-IN-A, quantizes to the nearest
    semitone (0 V = C3) with a little hysteresis so noise near a step
    boundary doesn't flutter, and drives the oscillator at the exact note
    frequency. CV-IN is a modulation inp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
    [app.c]
2026-06-14 firmware: wavetable browser + Audio Cfg menu, boot-time SD preload
    Phase 5 of wavetable synthesis: pick any of the SD card's wavetable
    folders live from the UI.
    - Audio Cfg menu screen: cursor-driven (rotate moves between Wavetable /
    Level, push acts — open the browser or enter Level edit). Removed the
    unused "Playback" stub mode.
    - Scrollable wavetable browser (windowed list over the ~116 folders);
    push loads the highlighted one. The oscillator is gated to silence
    while the SD read rewrites the PCM pool.
    - sd_fs_list_folders(): enumerate the card root into a RAM cache.
    SD reliability — do all SD I/O while audio is still silent:
    - app_preload() (called before audio_init) caches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
    [analog_in.c, app.c, main.c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]
2026-06-14 firmware: consistent cursor UX on the Arp screen
    Match the Menu / Audio Cfg interaction model: rotate moves the cursor
    between params; push acts on the cursored one — Enable/Clock toggle in
    place, value params (Dir/Octave/Length/Tempo) enter edit (value shown in
    brackets) where rotate adjusts and push confirms. Long-press leaves edit,
    then backs to the menu. Replaces the old push-cycles-cursor model.
    [app.c]
2026-06-14 firmware: polyphonic wavetable voice (4-voice pool)
    Turn the single-cycle oscillator into a pool of WT_MAX_VOICES=4 voices
    summed in the DMA-IRQ render. Each voice owns its zone / phase_inc /
    phase / active flag; the render snapshots the active voices once per
    block, sums them, and scales by level/sqrt(active) so a chord sits near
    a single voice's loudness, then clamps to int32.
    The mono path is byte-identical to the previous voice: wt_osc_note() and
    wt_osc_set_pitch() drive voice 0 and silence the rest, so the arp, key
    preview, and CV free-run are unchanged (1/sqrt(1)=1). New polyphonic API
    for the harmony engine's Chord engine (harmony-engine.md #4):
    wt_osc_chord(), wt_osc_note_on()/note_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
2026-06-14 docs: harmony engine spec (source x engine modes + progression sequencer)
    Design doc for the note-generation pipeline: harmonic source (CV-IN /
    key wheel / chord wheel) -> engine (Direct / Arp / Chord) -> outputs
    (wavetable audio + CV-OUT + gates). Captures the source x engine mode
    matrix, diatonic-triad theory, the bar-length key/chord progression
    sequencer, the UI model, a phased build plan, and open questions.
2026-06-14 firmware: harmony engine P1 — persistent source x engine modes
    Restructure note generation into the harmony-engine pipeline: a
    persistent mode = (pitch source x engine), decoupled from the on-screen
    view, replacing the peer-screens where the arp ran globally and collided
    with the CV VCO.
    - Menu is now modes + config: CV VCO / CV Arp / Key Arp / Arp Cfg /
    Audio Cfg. Boot is silent until a mode is selected.
    - engine_tick() runs every loop while a mode is active: it derives the
    root from the source (CV-IN quantized, or the key wheel) and drives the
    engine. Direct plays the root on the voice and passes it to CV-OUT with
    a gate on note change (#1); Arp feeds the root to the arp, whose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
    [app.c]
2026-06-14 firmware: USB-MIDI device mode + poly-voice deadline fix
    Replace the unstable CV-input play modes (CV VCO / CV Arp) with a class-compliant USB-MIDI device: the WeAct USB-C port enumerates as "Tachyon MIDI" and a host plays the polyphonic wavetable voice.
    - USB-MIDI 1.0 class (usbd_midi.c/.h): one embedded port; bulk-OUT parser -> lock-free event ring -> wt_osc_note_on/off (poly direct).
    - USB_SERIAL_DEBUG build flag selects the USB personality: default MIDI device; -DUSB_SERIAL_DEBUG=ON keeps the CDC console, with printf retargeted to SWO/ITM in the MIDI build. flash.ps1 gains -UsbSerialDebug.
    - app.c: drop the CV source/modes, add SRC_MIDI mode + USB MIDI screen.
    - Fix a 4-voice hang: the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
    [app.c, audio.c, main.c]
2026-06-14 docs: README — microSD wavetable use and the three play modes
    Document loading Korg .korgmultisample wavetables from microSD (Sample Builder / ConvertWithMoss, card layout, key-zones) and the Key Arp / Chord Arp / USB MIDI play modes.
2026-06-14 Update front-pcb-3d.png
    updated PCB front panel
2026-06-26 test: cover arp timing/clamp and wav header edge cases
2026-07-08 feat: per-voice velocity-sensitive envelope filter + Filter Cfg screen
2026-07-08 perf: fix arp jitter from display path; PCM pool to CCM
    - OLED frame blit over SPI1 DMA (was per-byte blocking, ~23 ms/frame)
    - dirty-flag rendering: screens redraw only on state change
    - app_tick/app_render split; display throttled to 30 fps
    - drift-free arp internal clock scheduling, with tests
    - GUI_Paint + circle_of_fifths compiled -O2 in Debug
    - wavetable PCM pool in CCM-RAM (.ccmbss section + startup zero-fill)
    - diag console line: loop/render/display/arp timing every 2 s
    Measured at 120 BPM: arp interval 486..521 ms before, 500..500 ms after.
    [DEV_Config.c, DEV_Config.h, OLED_1in5.c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]
2026-07-08 perf: circle-of-fifths wheel renders from precomputed geometry LUT
    Snapped 30-degree rotation only permutes segment indices, so the per-pixel
    sqrtf/atan2f pass runs once into a 32 KB CCM-RAM LUT (cof_prewarm at init);
    per-frame work is integer blends. Wheel render 34.5 ms -> 6.3 ms, and only
    on state change. Diag line gains a render count and dirty flag.
    [app.c, main.c]
2026-07-08 fix: move Filter Cfg render into app_render dispatch
    [app.c]
2026-07-08 docs: velocity is implemented, drop from usb-midi.md future list
2026-07-08 feat: selectable velocity mode (Volume/AtkAmt/AtkDec/FltEnv/AtkTime)
2026-07-14 v1.1 of PCB
    Redesign front panel PCB added silkscreen for sockets
    Remove usr-pot
    Fix for missing GND on U6 DAC8552
    [Drill_NPTH_Through.DRL, Drill_PTH_Through.DRL, Drill_PTH_Through_Via.DRL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]
2026-07-30 docs: add PCB ordering section (PCBWay layer mapping, Black FR4)
2026-10-14 Smooth voice stealing and decouple control acquisition from display (#4)
    * Smooth voice replacement and sample controls independently of display
    * Pin CI Arm GCC release to avoid broken latest download

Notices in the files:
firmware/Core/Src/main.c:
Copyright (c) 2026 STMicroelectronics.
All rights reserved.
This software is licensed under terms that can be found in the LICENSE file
